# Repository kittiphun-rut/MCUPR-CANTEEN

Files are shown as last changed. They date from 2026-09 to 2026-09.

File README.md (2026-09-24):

# MCU Phrae Smart Canteen — ระบบบริหารจัดการอาหารกลางวันนิสิต

ระบบคูปองอาหารดิจิทัล (โควตา 35 บาท/คน/วัน) ของมหาวิทยาลัยมหาจุฬาลงกรณราชวิทยาลัย
วิทยาเขตแพร่ ประกอบด้วยเฟิร์มแวร์ ESP32-S3 สองฝั่งที่คุยกันผ่าน ESP-NOW

> 📌 **ย้อนกลับไปใช้เวอร์ชันเก่า** — ทุกรุ่นของทั้งสองฝั่งอยู่บน GitHub แล้ว
> กดโหลด zip ได้เลยจาก [`VERSIONS.md`](VERSIONS.md) ·
> **ต้นฉบับก่อนแก้ไข** เก็บไว้ครบที่ [`original/`](original/)

| โฟลเดอร์ | บทบาท | เวอร์ชัน |
|---|---|---|
| `Canteen_Host_Server/` | เครื่องแม่ข่าย: ฐานข้อมูลนิสิต, นาฬิกา RTC, เว็บสำหรับเจ้าหน้าที่ | 113.1.0 |
| `Canteen_Station_Client/` | เครื่องประจำร้านค้า: อ่านบัตร RFID แล้วถามสิทธิ์จากแม่ข่าย | 122.1.0 |

> รุ่น 113.0.0 / 122.0.0 **เริ่มใหม่จากไฟล์ต้นฉบับ 107.0.1 / 117.0.7** ไม่ได้ต่อยอด
> จากสายเดิม ฟีเจอร์ที่เคยมีในสายเดิมบางอย่าง (เครื่องพิมพ์สลิป, คิวออฟไลน์,
> จอสาธารณะ `/display`) **ยังไม่ถูกใส่กลับเข้ามาในรุ่นนี้** ถ้าต้องการให้ใช้
> `release/11` หรือเก่ากว่า รายละเอียดอยู่ใน [`CHANGELOG.md`](CHANGELOG.md)

### โครงสร้างไฟล์

ทั้งสองฝั่งแยกส่วนวาดจอออกมาเป็นไฟล์ของตัวเองเหมือนกัน

```
Canteen_Host_Server/
├── Canteen_Host_Server.ino      ตรรกะระบบ ฐานข้อมูล ESP-NOW เส้นทางเว็บ  (2,052 บรรทัด)
├── HostScreen.h                 ทุกอย่างที่วาดลงจอ TFT ของแม่ข่าย           (836 บรรทัด)
└── WebDashboard.h               หน้าเว็บ แดชบอร์ด + จอสาธารณะบนทีวี          (936 บรรทัด)

Canteen_Station_Client/
├── Canteen_Station_Client.ino   ตรรกะระบบ อ่านบัตร ESP-NOW ปุ่มกด          (1,183 บรรทัด)
└── StationScreen.h              ทุกอย่างที่วาดลงจอ TFT ของจุดบริการ          (948 บรรทัด)
```

ไฟล์ `.h` เหล่านี้ถูก `#include` ไว้ **ท้ายไฟล์หลักก่อน `setup()`** เพราะโค้ดข้างใน
อ้างถึงตัวแปรส่วนกลางที่ประกาศไว้ข้างบน **อย่าย้าย `#include` ขึ้นไปบนสุด**
Arduino IDE จะแสดงทุกไฟล์เป็นแท็บของสเก็ตช์เดียวกัน เปิดพร้อมกันได้เลย

> ⚠️ ฟังก์ชันที่นิยามในไฟล์ `.h` จะ "มาทีหลัง" โค้ดทุกบรรทัดเหนือบรรทัด `#include`
> ถ้าโค้ดข้างบนเรียกใช้โดยไม่มีการประกาศล่วงหน้า **จะคอมไพล์ไม่ผ่าน**
> และค่าปริยายของพารามิเตอร์ต้องอยู่ที่การประกาศล่วงหน้าเท่านั้น ใส่ซ้ำที่นิยามไม่ได้
> ตรวจทั้งสองข้อได้ด้วย `python3 tools/proto-check/splitcheck.py`
>
> ⚠️ กติกาเดียวกันนี้ใช้ **ภายในไฟล์ `.h` เอง** ด้วย ฟังก์ชันที่ถูกเรียกต้องนิยามอยู่ข้างบน
> หรือมีบรรทัดประกาศล่วงหน้าอยู่ข้างบน จะอยู่ใน `.h` เดียวกันหรืออยู่ใน `.ino`
> เหนือบรรทัด `#include` ก็ได้ เพราะคอมไพเลอร์เห็นทั้งสองไฟล์เป็นไฟล์เดียวกัน
> ตรวจด้วย `python3 tools/proto-check/ordercheck.py`

---

## อินเตอร์เฟส

**หน้าเว็บเป็นสองภาษา ไทย/อังกฤษ** กดปุ่มบนแถบบนเพื่อสลับ เบราว์เซอร์จำค่าที่เลือกไว้
ค่าเริ่มต้นเป็นอังกฤษเพราะนิสิตส่วนใหญ่เป็นชาวต่างชาติ ส่วนหน้าเข้าสู่ระบบสลับได้เช่นกัน

**จอ TFT ทั้งสองฝั่งเป็นภาษาอังกฤษอย่างเดียว** เพราะฟอนต์ในตัวไลบรารี Adafruit GFX
ไม่มีตัวอักษรไทย ถ้าจะให้เป็นไทยต้องฝังฟอนต์บิตแมปเข้าไปเอง ซึ่งกินแฟลชเพิ่มมาก

> ⚠️ ถ้ามีภาษาไทยหลุดไปถึงจอ จะไม่ใช่แค่อ่านไม่ออก แต่ **ตัวอักษรจะซ้อนทับกัน**
> เพราะภาษาไทยหนึ่งตัวกินสามไบต์ จอจึงวาดเป็นสัญลักษณ์สามตัวและกว้างกว่าที่นับไว้สามเท่า
> ทุกข้อความที่มาจากผู้ใช้หรือฐานข้อมูลจึงผ่าน `asciiOnly()` ก่อนถึงจอเสมอ
> และ **ชื่อร้านมีช่องแยกสำหรับขึ้นจอโดยเฉพาะ** ตั้งได้จากแท็บ Shops บนหน้าเว็บ

มีสองโหมดสี **สว่าง** และ **มืด** เครื่องแม่ข่ายเป็นผู้กำหนดให้ทั้งระบบ

### คำแปลทำงานอย่างไร

ข้อความอังกฤษเขียนไว้ใน HTML ตามปกติแล้วติดป้าย `data-i="คีย์"` ส่วนคำไทยอยู่ใน
พจนานุกรมชุดเดียวชื่อ `TH` ที่หัวของ `DASH_JS` **ไม่ได้เขียนซ้ำสองชุดในทุกบรรทัด**
แบบที่เฟิร์มแวร์รุ่นเก่าทำ เวลาเพิ่มข้อความใหม่จึงแก้แค่สองที่ คือติดป้ายที่ HTML
กับเติมอีกหนึ่งบรรทัดในพจนานุกรม

ถ้าลืมเติมคำแปล หน้าเว็บจะแสดงภาษาอังกฤษไว้ก่อน ไม่พังและไม่กลายเป็นช่องว่าง

### หน้าเว็บของเจ้าหน้าที่

| แท็บ | มีอะไร |
|---|---|
| **Today** | จำนวนจานที่จ่ายวันนี้ · เป็นเงินเท่าไร · เหลืออีกกี่คน · นาฬิกาและสถานะเปิดบริการ<br>ยอดขายรายร้านเป็นแท่งเทียบกัน และสถานะของจุดบริการทั้งสี่จุด |
| **Students** | ค้นหา เพิ่ม ลบ ตัดสิทธิ์ด้วยตนเอง ผูกบัตรชั่วคราว และดาวน์โหลด CSV |
| **Shops** | ชื่อร้านและชื่อผู้ประกอบการทั้งสี่ร้าน |
| **Settings** | โหมดการแสดงผลของทุกจุดบริการ · เวลาเปิดบริการ · นาฬิกา · นำเข้ารายชื่อ<br>บัญชีเจ้าหน้าที่ · ไฟล์ประวัติย้อนหลัง · ปิดยอดประจำวัน |

ทุกแท็บสลับไทย/อังกฤษได้ รวมถึงข้อความแจ้งเตือนและกล่องถามยืนยันก่อนลบ

### จอของเครื่องแม่ข่าย (3 หน้า)

| หน้า | มีอะไร |
|---|---|
| **TODAY** | จำนวนจาน เงินที่จ่าย นาฬิกา และป้ายเปิด/ปิดบริการ |
| **SHOPS** | สี่ช่อง ช่องละร้าน ขึ้นชื่อร้านก่อนเลขจุดบริการ พร้อมจุดสถานะ สัญญาณ และแบตเตอรี่ |
| **SYSTEM** | ผลการแตะบัตรครั้งล่าสุด ข้อมูลเครือข่าย และข้อมูลเครื่อง |

### จอของเครื่องประจำร้านค้า (3 หน้า)

| หน้า | มีอะไร |
|---|---|
| **หน้าแรก** | บอกสถานะการให้บริการสามแบบ **TAP YOUR CARD** (คลื่นเขียว) เมื่อพร้อม · **SERVER OFFLINE** (คลื่นเหลือง) เมื่อแม่ข่ายไม่ตอบ · **OUT OF SERVICE** (คลื่นแดง) เมื่อเครื่องอ่านบัตรไม่ตอบ พร้อมยอดวันนี้และเวลา |
| **หน้าสอง** | ยอดของจุดนี้ หมายเลขจุด สถานะการเชื่อมต่อ และเวลา |
| **SYSTEM** | ข้อมูลเครื่องสำหรับคนดูแล |

ผลการแตะบัตรขึ้นเต็มจอเป็นคำเดียวตัวโต: `APPROVED` · `ALREADY SERVED` ·
`CLOSED NOW` · `NOT ON THE LIST` พร้อมประโยคอธิบายหนึ่งบรรทัดด้านล่าง

---

## ภาพหน้าจอ

ภาพทั้งหมดอยู่ใน [`docs/interface/`](docs/interface/) และเปิดดูพร้อมคำอธิบายทีละภาพได้ที่
[`docs/interface-gallery.html`](docs/interface-gallery.html) (โหลดไฟล์แล้วเปิดด้วยเบราว์เซอร์)

| | |
|---|---|
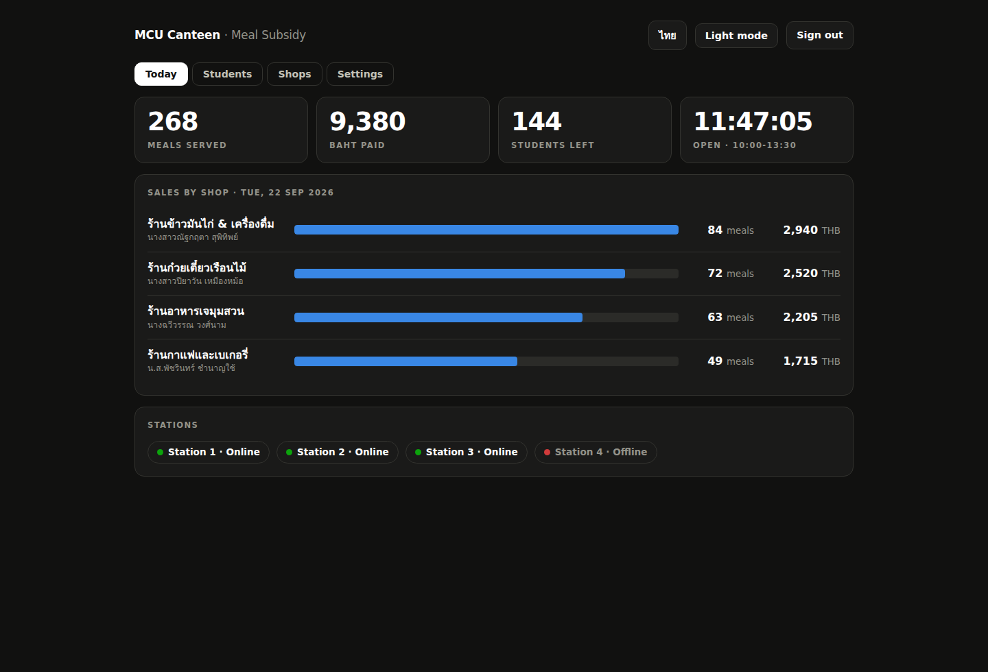
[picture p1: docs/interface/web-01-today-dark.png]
แดชบอร์ด Today โหมดมืด
|  | แดชบอร์ด Today โหมดสว่าง |
| **Today** — สิ่งที่เจ้าของร้านอยากรู้อยู่หน้าแรก | โหมดสว่าง ใช้ชุดสีที่ปรับแยกกัน |
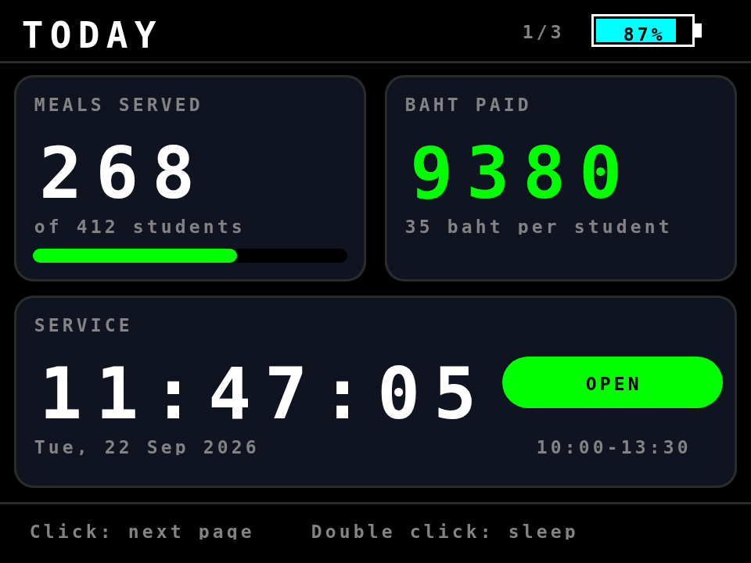
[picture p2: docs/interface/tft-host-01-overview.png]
จอแม่ข่ายหน้า TODAY
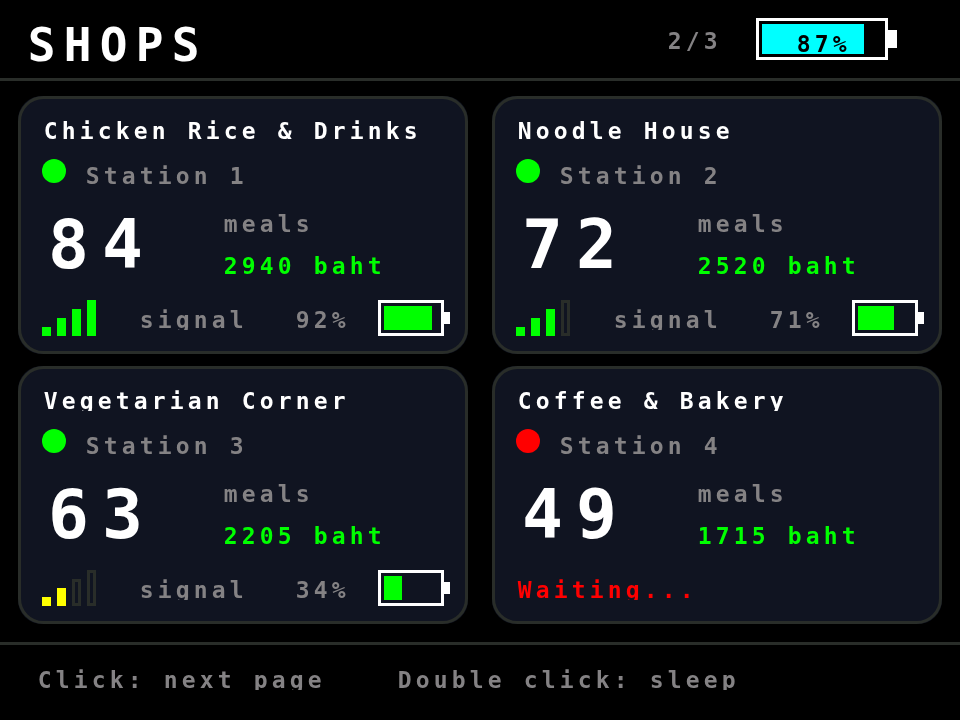
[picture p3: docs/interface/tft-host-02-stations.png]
จอแม่ข่ายหน้า SHOPS
|  |  |
| จอแม่ข่าย หน้า **TODAY** | จอแม่ข่าย หน้า **SHOPS** |
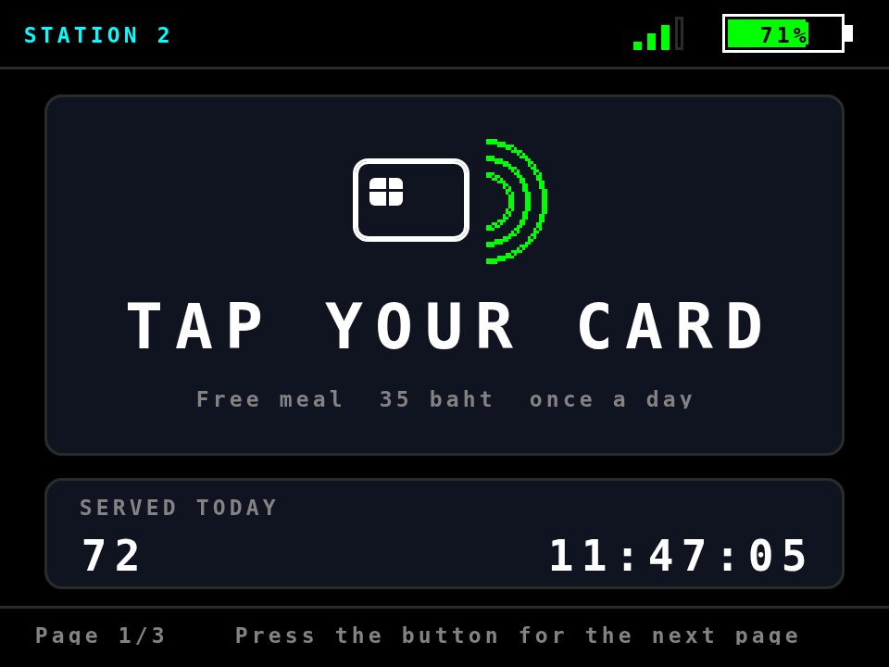
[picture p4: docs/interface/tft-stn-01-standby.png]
จอร้านค้ารอแตะบัตร
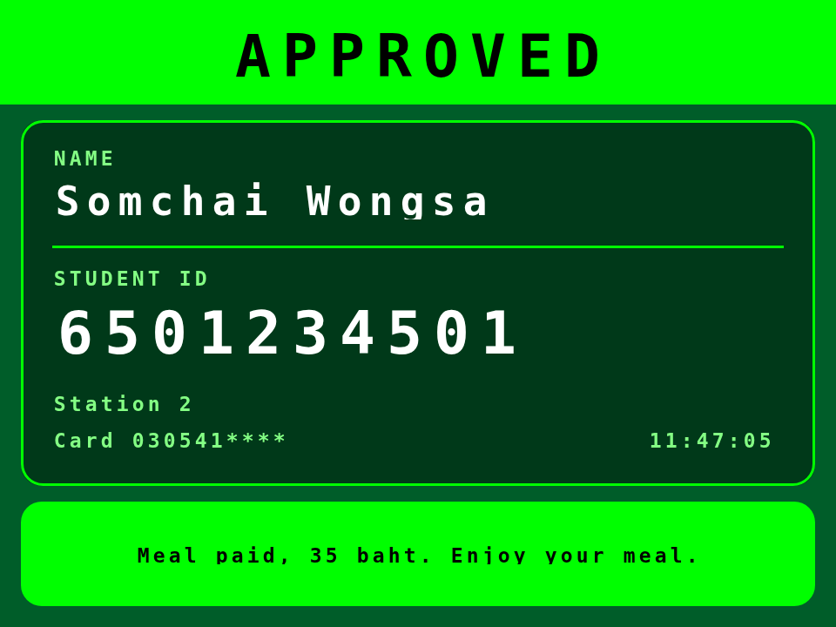
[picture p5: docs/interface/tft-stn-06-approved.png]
แจ้งผล APPROVED
|  |  |
| จอประจำร้านค้า มีประโยคเดียวที่นิสิตต้องอ่าน | ผลการแตะบัตร คำเดียวตัวโต |

ภาพจอ TFT ทั้งหมดเรนเดอร์จากตัวจำลอง Adafruit GFX บนผืนผ้าใบ 320x240
ภาพหน้าเว็บเรนเดอร์จากหน้าจริงที่ประกอบจาก `WebDashboard.h` ด้วย Chromium
ข้อมูลในภาพเป็นชุดตัวอย่างสำหรับสาธิต

---

## ฮาร์ดแวร์

ทั้งสองฝั่งใช้ ESP32-S3 DevKitC-1 (N16R8) + จอ ST7789V 2.8" 320x240 + WS2812 บน GPIO 48

**อุปกรณ์ภายนอกทุกตัวอยู่บนแถวซ้ายของบอร์ดแถวเดียว** แถวขวาไม่ได้ต่ออะไรเลย
และขาของแต่ละโมดูลเรียงติดกันตามลำดับขาบนตัวโมดูลเอง สายจึงไม่มีเส้นไหนไขว้กัน

### Host Server
| อุปกรณ์ | ขา | ตำแหน่งบนแถวซ้าย |
|---|---|---|
| TFT (บัส FSPI) | BLK 9 · CS 10 · DC 11 · RES 12 · SDA 13 · SCL 14 | 15–20 |
| DS3231 RTC (I2C) | SDA 4 · SCL 5 | 4–5 |
| Buzzer | 17 | 10 |
| ปุ่มกด | 18 (INPUT_PULLUP) | 11 |
| วัดแรงดันแบตเตอรี่ | 8 (ADC1_CH7, ตัวแบ่งแรงดัน 1:2) | 12 |
| การ์ด SD (หลังโมดูลจอ, **บัส HSPI แยกของตัวเอง**) | SCK 6 · MISO 7 · MOSI 15 · CS 16 | 6–9 |

### Station Client
| อุปกรณ์ | ขา | ตำแหน่งบนแถวซ้าย |
|---|---|---|
| TFT (**บัส HSPI**) | BLK 9 · CS 10 · DC 11 · RES 12 · SDA 13 · SCL 14 | 15–20 |
| RC522 (**บัส FSPI ผ่านตัวแปร `SPI`**) | SS 4 · SCK 5 · MOSI 6 · MISO 7 · RST 15 | 4–8 |
| Buzzer | 17 | 10 |
| ปุ่มกด | 18 (INPUT_PULLUP) | 11 |
| วัดแรงดันแบตเตอรี่ | 8 (ADC1_CH7, ตัวแบ่งแรงดัน 1:2) | 12 |

บัซเซอร์ ปุ่มกด และสายวัดแบตเตอรี่ **ใช้ขาเดียวกันทั้งสองบอร์ด**
ประกอบสายชุดเดียวแล้วสลับใช้ได้ทั้งสองฝั่ง

> **สำคัญ:** บน ESP32-S3 ตัวแปร `SPI` มาตรฐานผูกกับ FSPI (SPI2_HOST) และไลบรารี MFRC522
> เรียกใช้ตัวแปรนั้น จอจึงต้องอยู่บน HSPI (SPI3_HOST) มิฉะนั้นอุปกรณ์สองตัวจะแย่ง
> peripheral เดียวกันคนละขา และจอจะเพี้ยนหลัง `PCD_Init()`

---

## เมื่อเครื่องแม่ข่ายไม่ตอบ

ระบบนี้ออกแบบให้ **fail-closed** คือถ้าตัดสินสิทธิ์ไม่ได้ก็ไม่ให้บริการ
ไม่ใช่เดาแล้วปล่อยผ่าน เพราะอาหารที่จ่ายไปแล้วเรียกคืนไม่ได้
และสิทธิ์เป็นวันละครั้งข้ามสี่จุดบริการ ถ้าแม่ข่ายล่มก็ล่มพร้อมกันทั้งสี่จุด
การอนุมัติเองตอนออฟไลน์จึงเปิดช่องให้รับซ้ำได้ทันทีโดยกระทบกันทีหลังไม่ได้

**จุดบริการไม่มีฐานข้อมูลเลย** ไม่เคยตัดสินใจเอง ส่งหมายเลขบัตรไปแล้วรอคำตอบอย่างเดียว

| สถานการณ์ | สิ่งที่จุดบริการทำ | ตัดสิทธิ์ไปหรือยัง |
|---|---|---|
| แม่ข่ายเงียบเกิน 15 วินาที | หน้าแรกขึ้น **SERVER OFFLINE** และ**ไม่รับการแตะบัตร** | **ไม่** การันตีได้ เพราะไม่ได้ส่งอะไรออกไป |
| แตะบัตรตอนนั้นพอดี | ขึ้นหน้าเตือน **SERVER OFFLINE** ทันที ไม่ต้องรอหมดเวลา | **ไม่** เหตุผลเดียวกัน |
| ส่งไปแล้วไม่มีคำตอบใน 3 วินาที | ขึ้นหน้า **RESULT UNKNOWN** | **ไม่ทราบ** ดูคำอธิบายข้างล่าง |

### ทำไมต้องมีคำว่า "ไม่ทราบผล"

ถ้าแม่ข่ายอนุมัติและบันทึกไปแล้ว แต่แพ็กเก็ตตอบกลับหายระหว่างทางทั้งสามครั้ง
จุดบริการจะหมดเวลารอโดยที่ **แม่ข่ายบันทึกว่ารับไปแล้วจริง ๆ**
การขึ้นว่า "ไม่สำเร็จ" ในกรณีนี้จึงเป็นการบอกข้อมูลผิด

เรื่องนี้แก้ให้หายขาดไม่ได้ในทางทฤษฎี เป็นปัญหา **Two Generals**
มาตรฐานจึงไม่พยายามกำจัด แต่ทำให้ **กู้คืนได้** แทน
หน้าจอจึงบอกว่าไม่ทราบผล แล้วชี้ทางให้ **แตะบัตรซ้ำ**
ถ้าแม่ข่ายบันทึกไปแล้วจะตอบว่า `ALREADY SERVED` ถ้ายังไม่ได้บันทึกก็จะตัดสิทธิ์ให้ตามปกติ
ไม่ว่าทางไหนก็ได้คำตอบที่ถูกต้อง และไม่มีทางจ่ายซ้ำ

### การส่งซ้ำไม่ทำให้ตัดสิทธิ์ซ้ำ

ทุกครั้งที่แตะบัตร จุดบริการแนบ **หมายเลขลำดับ (seq)** ไปด้วย และส่งซ้ำสูงสุดสามครั้ง
แม่ข่ายจำคู่ `(หมายเลขจุดบริการ, seq)` ล่าสุดไว้ ถ้าเจอคู่เดิมซ้ำ
มันจะ **ส่งคำตอบเดิมที่แคชไว้กลับไป ไม่ประมวลผลใหม่**
คุณสมบัตินี้เรียกว่า idempotent request เป็นหัวใจของการกันข้อมูลไม่ตรงกัน
ถ้าไม่มี การส่งซ้ำสามครั้งจะกลายเป็นตัดสิทธิ์สามครั้ง

> ⚠️ บนรุ่น **N16R8** ขา `GPIO33`–`GPIO37` ถูก **PSRAM แบบ OPI** จองไว้
> ถึงแม้ `GPIO35` `GPIO36` `GPIO37` จะโผล่อยู่บนแถวขวาของบอร์ดก็ห้ามใช้
> ตรวจได้ด้วย `python3 tools/proto-check/pincheck.py`

**ผังการต่อสายเต็ม ๆ พร้อมลำดับขาของทุกโมดูล อยู่ใน
[`docs/HARDWARE.md`](docs/HARDWARE.md)**

---

## ไลบรารีที่ต้องติดตั้ง

`Adafruit GFX` · `Adafruit ST7735/ST7789` · `ArduinoJson (v6)` · `RTClib` · `MFRC522`
บน Arduino ESP32 core 2.x หรือ 3.x (โค้ดครอบ `ESP_ARDUINO_VERSION_MAJOR` ไว้แล้ว)

### การตั้งค่าบอร์ดใน Arduino IDE

| หัวข้อใน Tools | ต้องตั้งเป็น |
|---|---|
| Board | ESP32S3 Dev Module |
| Flash Size | **16MB (128Mb)** |
| PSRAM | **OPI PSRAM** |
| Partition Scheme | **Huge APP (3MB No OTA/1MB SPIFFS)** |
| USB Mode | Hardware CDC and JTAG |

> ⚠️ **Partition Scheme สำคัญมาก เลือกผิดแล้วอัปโหลดไม่ได้เลย**
>
> ถ้าใช้ค่าเริ่มต้น *Default 4MB with spiffs* จะได้พื้นที่โปรแกรมแค่ **1.25 MB**
> ซึ่งไม่พอ เฟิร์มแวร์แม่ข่ายจะขึ้นว่า `Sketch too big` ทั้งที่บอร์ดมีแฟลช 16 MB
> พอเปลี่ยนเป็น *Huge APP* จะได้ 3 MB
>
> **ห้ามเลือกแบบที่ลงท้ายด้วย FATFS** (เช่น *16M Flash (3MB APP/9.9MB FATFS)*)
> เพราะโค้ดเรียก `LittleFS.begin(true)` ซึ่งมองหาพาร์ทิชันชื่อ `spiffs`
> ส่วนแบบ FATFS ตั้งชื่อพาร์ทิชันว่า `ffat` ทำให้เมานต์ไม่ขึ้นและ
> **ฐานข้อมูลนิสิตทั้งหมดหายไป** ต้องเป็นแบบที่ลงท้ายด้วย SPIFFS เท่านั้น

---

## แก้ปัญหาที่พบบ่อย

### ไม่มีชื่อ Wi-Fi `MCU_CANTEEN_HOST` ขึ้นมาให้เลือก

เครื่องแม่ข่าย **ขึ้นจอบอกสถานะเครือข่ายให้เองตอนบูต** ค้างไว้สามวินาที
ดูที่จอของเครื่องแม่ข่ายก่อนเสมอ

| สิ่งที่เห็นบนจอ | แปลว่า | ทำอย่างไร |
|---|---|---|
| แถบเขียว **WI-FI IS ON** พร้อมชื่อ รหัสผ่าน และเลข IP | เครื่องปล่อยสัญญาณแล้ว | ปัญหาอยู่ที่อุปกรณ์ที่ใช้ค้นหา ลองปิด-เปิด Wi-Fi ของโทรศัพท์ หรือลืมเครือข่ายเดิมแล้วค้นใหม่ |
| แถบแดง **WI-FI FAILED TO START** | เรียก `WiFi.softAP()` ไม่สำเร็จสามครั้งติด | ถอดไฟแล้วเสียบใหม่ ถ้ายังเป็นอีกให้แฟลชใหม่ (การอ่านบัตรยังทำงานได้ตามปกติ) |
| จอไม่ขึ้นอะไรเลย หรือค้างที่แอนิเมชันบูต | เครื่องแพนิกหรือบูตวน | ดูข้อความบน Serial Monitor ที่ 115200 |

> **เคยเกิดขึ้นจริงมาแล้ว** ในสายเฟิร์มแวร์เดิม สาเหตุคือ `WIFI_PROTOCOL_LR`
> ซึ่งเป็นโหมดระยะไกลเฉพาะของ Espressif ทำให้โทรศัพท์และคอมพิวเตอร์
> **มองไม่เห็นชื่อ Wi-Fi** ทั้งที่เครื่องปล่อยสัญญาณอยู่
> รุ่นนี้เริ่มใหม่จากต้นฉบับซึ่งไม่มีบรรทัดนั้นแล้ว ถ้าจะเพิ่มโหมดระยะไกลในอนาคต
> **ต้องทดสอบกับโทรศัพท์จริงก่อนเสมอ**

### เข้า `canteen.local` ไม่ได้

Android บางรุ่นไม่รองรับ mDNS ให้พิมพ์ `192.168.4.1` ตรง ๆ แทน
(จอตอนบูตแสดงหมายเลขนี้ไว้ให้แล้ว)

---

## ข้อควรรู้เวลาแก้โค้ดต่อ

Arduino IDE **สร้างต้นแบบฟังก์ชัน (prototype) ให้เองอัตโนมัติ** แล้ววางไว้ใกล้หัวไฟล์
ซึ่งอยู่ **เหนือจุดที่นิยาม struct ของสเก็ตช์** ถ้าเพิ่มฟังก์ชันที่รับ struct ของโครงการ
เป็นพารามิเตอร์แล้วลืมประกาศล่วงหน้า จะคอมไพล์ไม่ผ่านด้วยข้อความชวนงงแบบนี้

```
error: variable or field 'fillStationConfig' declared void
error: 'HostConfigPacket' was not declared in this scope
```

ทุกฟังก์ชันแบบนั้นต้องมีบรรทัดประกาศอยู่ในบล็อก *Forward Declarations*
(อยู่หลังนิยามโครงสร้างทั้งหมด) ตรวจได้ด้วย

```sh
python3 tools/proto-check/protoscan.py \
  Canteen_Host_Server/Canteen_Host_Server.ino \
  Canteen_Station_Client/Canteen_Station_Client.ino
```

และตรวจวงเล็บของทุกไฟล์ (รวมไฟล์ `.h` ที่ถูก include) ด้วย

```sh
python3 tools/proto-check/runall.py        # รันทุกตัวข้างล่างนี้รวดเดียว

python3 tools/proto-check/headercheck.py   # หัวไฟล์และป้ายเวอร์ชัน
python3 tools/proto-check/asciicheck.py    # ข้อความที่ฟอนต์ของจอ TFT วาดไม่ได้
python3 tools/proto-check/bracecheck.py    # วงเล็บและเครื่องหมายคำพูดของทุกไฟล์
python3 tools/proto-check/splitcheck.py    # ปัญหาจากการแยกโค้ดไปไว้ในไฟล์ .h
python3 tools/proto-check/ordercheck.py    # ฟังก์ชันที่ถูกเรียกก่อนถูกประกาศ
python3 tools/proto-check/gfxcheck.py      # ฟังก์ชัน GFX ที่ต้องมี startWrite() ก่อน
python3 tools/proto-check/packetcheck.py   # แพ็กเก็ตคำสั่งที่ใส่ฟิลด์ไม่ครบ
python3 tools/proto-check/pincheck.py      # ขาชนกันเองหรือไปโดนขาต้องห้าม
python3 tools/proto-check/kicadcheck.py    # ไฟล์วงจร KiCad ตรงกับผังขาในซอร์ส
```

### มาตรฐานคอมเมนต์

ทุกไฟล์ซอร์สมีหัวไฟล์แบบ **Doxygen** บอกเวอร์ชัน วันที่ และ **ตารางประวัติการแก้ไข**
ว่าแต่ละรุ่นเปลี่ยนอะไรในไฟล์นั้นบ้าง ส่วนในเนื้อโค้ดมีป้าย `// [113.0.0] เพิ่ม: ...`
ปักไว้เหนือจุดที่เพิ่มหรือแก้ เปิดไฟล์ขึ้นมาแล้วรู้ทันทีว่าอะไรมาจากรุ่นไหน
โดยไม่ต้องไปไล่อ่าน git log

รายละเอียดและกติกาทั้งหมดอยู่ใน **[`docs/CODE-STANDARD.md`](docs/CODE-STANDARD.md)**
และถูกบังคับด้วย `headercheck.py` — ถ้าลืมอัปเดตเลขเวอร์ชัน ลืมเติมแถวในตาราง
หรือปักป้ายด้วยเลขที่ไม่มีอยู่จริง ตัวตรวจจะฟ้องทันที

`bracecheck` ตรวจทั้งวงเล็บและ **สตริงที่เปิดแล้วไม่ปิดภายในบรรทัดเดียวกัน**
ข้อหลังเพิ่มเข้ามาหลังจากพลาดลบเครื่องหมายคำพูดเปิดทิ้งตอนแก้ HTML ที่ฝังอยู่ในสตริง C++
ซึ่งคอมไพล์ไม่ผ่านแน่นอนแต่ตัวนับวงเล็บมองไม่เห็น

---

## โปรโตคอล ESP-NOW (ช่อง 1, ไม่เข้ารหัส)

ทุกแพ็กเก็ตขึ้นต้นด้วย `magic = 0xCA` และ `version = 2` ฝั่งรับจะตรวจทั้งสองค่าก่อนเสมอ

| โครงสร้าง | ขนาด | ทิศทาง | ใช้เมื่อ |
|---|---|---|---|
| `StationPacket` | 50 ไบต์ | สถานี → แม่ข่าย | `MSG_HEARTBEAT (1)`, `MSG_SCAN_REQ (2)` |
| `HostResponsePacket` | 200 ไบต์ | แม่ข่าย → สถานี | `MSG_HEARTBEAT (1)`, `MSG_SCAN_RESP (3)` |
| `HostConfigPacket` | 8 ไบต์ | แม่ข่าย → สถานี | `MSG_CONFIG (4)` สั่งโหมดการแสดงผล: ธีม ไฟหน้าจอ และโหมดพักหน้าจอ (`stationId = 0` คือทุกสถานี) |

ขนาดทั้งสามถูกยืนยันด้วย `static_assert` ทั้งสองฝั่ง ถ้าแก้โครงสร้างแล้วขนาดไม่ตรง
จะคอมไพล์ไม่ผ่าน แทนที่จะไปพังตอนใช้งานจริง

การกันแพ็กเก็ตซ้ำ: `MSG_SCAN_REQ` พกหมายเลขลำดับ (`seq`) ถ้าแม่ข่ายได้รับซ้ำ
จะส่งคำตอบเดิมกลับไปโดยไม่ตัดสิทธิ์ซ้ำ

---

## เว็บสำหรับเจ้าหน้าที่

เข้าผ่าน `http://192.168.4.1` หรือ `http://canteen.local` หลังต่อ Wi-Fi `MCU_CANTEEN_HOST`
บัญชีเริ่มต้น `admin` / `admin1234` (**ควรเปลี่ยนทันทีหลังติดตั้ง**)

### หน้าเข้าระบบเด้งขึ้นเอง (Captive Portal)

เมื่อโทรศัพท์ต่อ Wi-Fi ระบบปฏิบัติการจะยิงคำขอไปยัง URL ที่ใช้ตรวจว่าเครือข่าย
ออกอินเทอร์เน็ตได้หรือไม่ เครื่องแม่ข่ายดักไว้ด้วย `DNSServer` ที่ตอบทุกโดเมน
กลับมาที่ `192.168.4.1` และ `server.onNotFound()` ที่ตอบ HTTP 302 ไปหน้าเข้าสู่ระบบ

หน้าต่างที่เด้งขึ้นมาบน iOS เป็นเบราว์เซอร์ย่อส่วน คุกกี้ที่ได้จากการล็อกอินในหน้าต่างนี้
จะไม่ถูกส่งต่อให้ Safari ถ้าเจ้าหน้าที่ต้องใช้งานนาน ให้เลือก "ใช้เครือข่ายนี้ตามที่เป็น"
แล้วเปิด Safari ไปที่ `192.168.4.1` แทน

### เส้นทาง

| Method | Path | หน้าที่ |
|---|---|---|
| GET | `/` | แดชบอร์ด (โครงหน้าเล็ก ๆ ตัวเลขมาจาก `/api/dashboard`) |
| GET | `/display` | **จอสาธารณะสำหรับทีวีในโรงอาหาร เปิดดูได้โดยไม่ต้องเข้าสู่ระบบ** |
| GET | `/api/board` | ตัวเลขของจอสาธารณะ ดึงทุกสองวินาที เปิดดูได้โดยไม่ต้องเข้าสู่ระบบ |
| GET | `/s.css` · `/a.js` | สไตล์และสคริปต์ เสิร์ฟตรงจากแฟลช เบราว์เซอร์แคชได้ 1 วัน |
| GET | `/api/dashboard` | ตัวเลขสดทั้งหมด หน้าเว็บดึงทุกสองวินาที |
| GET | `/api/students` | รายชื่อแบบแบ่งหน้า (`page`, `limit` สูงสุด 100, `search`) |
| GET | `/export.csv` | รายงานสรุปประจำวัน |
| GET | `/api/archive/download?file=arc_*.csv` | ดาวน์โหลดไฟล์ประวัติ |
| GET | `/api/system/health` | อุณหภูมิ โหลด และหน่วยความจำของเครื่องแม่ข่าย |
| POST | `/api/display` | สั่งโหมดการแสดงผลของทุกจุดบริการ |
| POST | `/api/student/save` · `/api/student/delete` | จัดการรายชื่อ |
| POST | `/api/tempcard/save` · `/api/tempcard/remove` · `/bind-temp` | จัดการบัตรชั่วคราว |
| POST | `/manual-claim` | ตัดสิทธิ์ด้วยตนเอง |
| POST | `/api/admin/save` · `/api/admin/delete` | จัดการบัญชีเจ้าหน้าที่ |
| POST | `/save-shops` · `/api/settings/time` · `/api/rtc/set` | ตั้งค่าระบบ |
| POST | `/reset` · `/api/archive/delete` | ปิดยอดประจำวัน / ลบไฟล์ประวัติ |
| POST | `/upload` | นำเข้ารายชื่อจาก CSV |

**คำสั่งที่เปลี่ยนแปลงข้อมูลเป็น POST ทั้งหมด** ลิงก์เดียวจึงลบข้อมูลไม่ได้
และการพรีเฟตช์ของเบราว์เซอร์ไม่ไปกดคำสั่งโดยบังเอิญ

---

## จอสาธารณะบนทีวี (`/display`)

เปิดเบราว์เซอร์บนทีวีหรือกล่อง Android ไปที่ `http://192.168.4.1/display`
แล้วกดเต็มจอ ปล่อยค้างไว้ได้ทั้งวัน หน้านี้ **ไม่ต้องเข้าสู่ระบบ** โดยตั้งใจ
เพราะไม่มีใครอยากพิมพ์รหัสผ่านด้วยรีโมททีวี และถ้าเครื่องทีวีรีบูต
หน้าจอต้องกลับมาเองโดยไม่ต้องมีคนไปกด

### แสดงอะไรบ้าง

| ส่วน | เนื้อหา |
|---|---|
| แถบบน | ชื่อโรงอาหาร นาฬิกา วันที่ และป้ายเปิด/ปิดบริการพร้อมช่วงเวลา |
| ตัวเลขสามช่อง | จ่ายไปกี่จาน เป็นเงินกี่บาท และเหลืออีกกี่คน |
| ยอดขายรายร้าน | ชื่อร้าน จำนวนจาน จำนวนเงิน และแท่งเทียบสัดส่วนกัน |
| รายการล่าสุด | แปดรายการหลังสุดที่ผ่านแล้วเท่านั้น |

ไทยกับอังกฤษขึ้นพร้อมกันทั้งคู่ ไม่มีปุ่มสลับภาษาแบบหน้าแดชบอร์ด
เพราะไม่มีใครเดินไปกดปุ่มบนจอทีวี

### ข้อมูลที่หน้านี้ห้ามมีเด็ดขาด

ใครเดินผ่านโรงอาหารก็เห็นจอนี้ หน้านี้จึงถูกกำหนดไว้ว่า

* **รหัสนิสิตถูกปิดบังเหลือห้าหลักแรก** ที่เหลือเป็นดอกจัน เช่น `65012*****`
* **ไม่มีชื่อนิสิต** ไม่ว่ากรณีใด
* **ไม่มีหมายเลขบัตร** และ **ไม่มีเลขอ้างอิงรายการ**
* **ไม่มีข้อมูลฮาร์ดแวร์ของเครื่องแม่ข่าย** เช่น อุณหภูมิ หน่วยความจำ หรือ MAC
* **มีเฉพาะรายการที่ผ่านแล้ว** รายการที่ถูกปฏิเสธหรือซ้ำไม่ขึ้นบนจอนี้

ข้อกำหนดนี้ไม่ได้อยู่แค่ในเอกสาร แต่ถูกบังคับด้วย
`tools/proto-check/privacycheck.py` ซึ่งจะฟ้องทันทีถ้ามีใครเผลอใส่ฟิลด์ต้องห้าม
ลงใน `handlePublicBoard()` หรือเพิ่มเส้นทางสาธารณะใหม่โดยไม่ได้ตั้งใจ

### ข้อควรระวังเรื่องเครือข่าย

เส้นทางนี้เปิดให้ **ทุกคนที่ต่อ Wi-Fi ของเครื่องแม่ข่ายได้** ไม่ใช่เฉพาะทีวี
ข้อมูลที่ปล่อยออกไปจึงถูกจำกัดไว้เท่าที่ยอมให้คนนอกเห็นตามรายการข้างบน
ถ้าต้องการให้แคบกว่านี้ ต้องแยกเครือข่ายของทีวีออกจากเครือข่ายที่ให้บริการ

---

## ไฟล์ข้อมูลใน LittleFS

| ไฟล์ | เนื้อหา |
|---|---|
| `/students.csv` | ทะเบียนนิสิต `studentId,fullName,uid` |
| `/daily_log.csv` | บันทึกการรับสิทธิ์ของวัน ใช้กู้สถานะเมื่อไฟดับแล้วบูตใหม่ |
| `/arc_YYYYMMDD_HHMMSS.csv` | ไฟล์ประวัติที่ถูกจัดเก็บตอนปิดยอดประจำวัน |
| `/admins.json` | บัญชีเจ้าหน้าที่ |
| `/shops.json` | ชื่อร้านและผู้ประกอบการ |

ไฟล์ที่ส่งออกจาก `/export.csv` ครอบทุกช่องด้วยเครื่องหมายคำพูดและเติมซ้ำให้ถูกแบบ
ชื่อร้านหรือชื่อนิสิตที่มีลูกน้ำหรือเครื่องหมายคำพูดจึงไม่ทำให้คอลัมน์เลื่อน

---

## การใช้งานปุ่มกด

| การกด | Host Server | Station Client |
|---|---|---|
| คลิก 1 ครั้ง | เปลี่ยนหน้า (3 หน้า) | เปลี่ยนหน้า (3 หน้า) |
| คลิก 2 ครั้ง | เข้าโหมดพักหน้าจอ **+ สั่งทุกจุดบริการตาม** | พักหน้าจอเฉพาะเครื่องนี้ (ตื่นเองเมื่อมีคนแตะบัตร) |
| คลิก 3 ครั้ง | สลับธีมสว่าง/มืด **+ สั่งทุกจุดบริการตาม** | ขึ้นข้อความแจ้งว่าธีมถูกกำหนดจากแม่ข่าย |
| กดค้าง 1.5 วินาที | — | ขึ้นข้อความแจ้งว่าการแสดงผลถูกกำหนดจากแม่ข่าย |
| กดค้าง 3 วินาที | — | ตั้งหมายเลขจุดบริการ (1-4) |
| กดค้าง 5 วินาที | หน้าเครดิตผู้พัฒนา | หน้าเครดิตผู้พัฒนา |

### โหมดการแสดงผลถูกควบคุมจากเครื่องแม่ข่าย

เครื่องแม่ข่ายเป็นเจ้าของโหมดการแสดงผลของทั้งระบบ สั่งได้สองทาง คือหน้า **Settings**
บนเว็บ และปุ่มกดบนเครื่อง คำสั่งไปถึงจุดบริการผ่าน `HostConfigPacket` (`MSG_CONFIG`)
ทั้งแบบ broadcast ทันทีที่โหมดเปลี่ยน และย้ำอีกครั้งทุกครั้งที่ตอบ heartbeat
จุดบริการที่เพิ่งบูตหรือที่พลาดคำสั่ง broadcast จึงกลับมาตรงกับแม่ข่ายภายในไม่กี่วินาที

| สิ่งที่ซิงค์ | พฤติกรรม |
|---|---|
| ธีมสว่าง/มืด | **บังคับเสมอ** จุดบริการเปลี่ยนตามทุกครั้งที่ค่าไม่ตรงกับแม่ข่าย |
| โหมดพักหน้าจอ | ทำตามเมื่อแม่ข่ายเข้า/ออกโหมดพักหน้าจอ |
| ไฟหน้าจอ | ทำตามเมื่อเจ้าหน้าที่สั่งปิด/เปิดจอที่แม่ข่าย |

โหมดพักหน้าจอและไฟหน้าจอเป็นคำสั่งแบบ "สั่งเมื่อเปลี่ยน" (ดูจากค่า `modeSeq` ที่เพิ่มขึ้น)
ส่วนธีมเป็นคำสั่งแบบบังคับ

**เหตุผลที่ตัดการตั้งค่าฝั่งจุดบริการออก:** ถ้าแต่ละจุดตั้งเองได้ จอในโรงอาหารจะไม่เหมือนกัน
และคนที่มารับช่วงดูแลต่อจะไม่มีทางรู้ว่าใครไปกดอะไรไว้ที่เครื่องไหน

ข้อยกเว้นที่ตั้งใจไว้: ถ้ามีคนแตะบัตรขณะระบบพักหน้าจอ จุดบริการนั้นจะตื่นขึ้นแสดงผลทันที
และแม่ข่ายจะปลุกทุกจุดพร้อมกัน เพราะถือว่ากลับมาให้บริการแล้ว

---

## ข้อควรทราบด้านความปลอดภัย

- รหัสผ่านเจ้าหน้าที่เก็บเป็นข้อความธรรมดาใน `/admins.json` — เครื่องนี้จึงควรอยู่ในพื้นที่ควบคุม
- ESP-NOW ไม่ได้เข้ารหัส ผู้ที่อยู่ในระยะสามารถดักฟังหมายเลขบัตรได้
- Wi-Fi AP ใช้รหัสผ่านเริ่มต้น `12345678` และบัญชีเริ่มต้นคือ `admin` / `admin1234`
  **ทั้งสองอย่างควรเปลี่ยนก่อนเปิดใช้งานจริง**
- โทเคนเข้าสู่ระบบสุ่มจากตัวสุ่มในตัวชิป (`esp_random`) ไม่ใช่ `random()` ของ Arduino
  ที่ให้ลำดับเดิมทุกครั้งที่เปิดเครื่อง
- การดาวน์โหลดและลบไฟล์ประวัติรับเฉพาะชื่อ `arc_*` ในรากของ LittleFS เท่านั้น

รายละเอียดสิ่งที่แก้ไขทั้งหมดอยู่ใน [CHANGELOG.md](CHANGELOG.md)

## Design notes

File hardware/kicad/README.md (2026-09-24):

# ไฟล์วงจรสำหรับ KiCad

ไฟล์ในโฟลเดอร์นี้ **สร้างขึ้นอัตโนมัติ** จากผังขาในซอร์สของเฟิร์มแวร์
อย่าแก้ไฟล์ `.kicad_sch` ด้วยมือ เพราะจะถูกทับเมื่อสร้างใหม่

| ไฟล์ | คืออะไร |
|---|---|
| `Canteen_Host.kicad_pro` · `.kicad_sch` | วงจรของเครื่องแม่ข่าย เปิดด้วย KiCad ได้เลย |
| `Canteen_Station.kicad_pro` · `.kicad_sch` | วงจรของจุดบริการ |
| `MCUPR_Canteen.kicad_sym` | ไลบรารีสัญลักษณ์ เผื่ออยากเอาไปใช้ในงานอื่น |
| `*.net` | netlist ที่ KiCad เอ็กซ์พอร์ตออกมา ใช้ตรวจสอบและนำเข้า Pcbnew |
| `*.pdf` | ภาพวงจรสำหรับพิมพ์หรือส่งต่อ ไม่ต้องมี KiCad ก็เปิดดูได้ |
| `generate_kicad.py` | ตัวสร้างไฟล์ทั้งหมด |

## วิธีเปิด

ดับเบิลคลิก `Canteen_Station.kicad_pro` แล้วเปิดหน้า Schematic
**ไม่ต้องติดตั้งไลบรารีอะไรเพิ่ม** เพราะสัญลักษณ์ทุกตัวถูกฝังไว้ในไฟล์วงจรแล้ว
สร้างและทดสอบด้วย **KiCad 7** ส่วน KiCad 8 ขึ้นไปจะถามว่าจะอัปเกรดไฟล์หรือไม่ ตอบตกลงได้

## อ่านวงจรนี้อย่างไร

วงจรนี้ **ไม่ได้ลากเส้นยาวข้ามหน้า** แต่ใช้ **ป้ายชื่อเน็ต (global label)** แทน
ขาไหนที่มีป้ายชื่อเดียวกัน คือขาที่ต้องต่อถึงกัน เช่น ขา `GPIO14` ของบอร์ด
กับขา `SCL` ของจอ ต่างก็มีป้ายว่า `TFT_SCL` แปลว่าสองขานี้ต่อเข้าหากัน

วิธีนี้ตรงกับงานเดินสายจริงมากกว่าการลากเส้น เพราะสิ่งที่ช่างต้องรู้คือ
"ขานี้ไปขาไหน" ไม่ใช่ "เส้นวิ่งอ้อมทางไหน" และหน้ากระดาษก็ไม่รก

ขาที่มีเครื่องหมาย **✕** คือขาที่ตั้งใจไม่ต่ออะไร

## หมายเลขขาของบอร์ด ESP32-S3 DevKitC-1

สัญลักษณ์ `U1` นับขาแบบนี้ ให้หันด้านพอร์ต USB เข้าหาตัว

* **ขา 1 ถึง 22** คือแถวซ้าย ไล่จากบนลงล่าง เริ่มที่ `3V3` จบที่ `GND`
* **ขา 23 ถึง 44** คือแถวขวา ไล่จากบนลงล่าง เริ่มที่ `GND` จบที่ `GND`

เลขนี้ตรงกับตำแหน่งจริงบนบอร์ด และตรงกับตารางใน [`docs/HARDWARE.md`](../../docs/HARDWARE.md)

## รายการอุปกรณ์

| อ้างอิง | อุปกรณ์ | หมายเหตุ |
|---|---|---|
| `U1` | ESP32-S3 DevKitC-1 (N16R8) | 16 MB flash · 8 MB PSRAM แบบ OPI |
| `J2` | จอ ST7789 2.8" 320×240 | แปดขา ตรวจแรงดันก่อนจ่ายไฟ |
| `J3` (จุดบริการ) | MFRC522 13.56 MHz | ขา IRQ ไม่ได้ใช้ |
| `J3` (แม่ข่าย) | DS3231 ZS-042 | มีตัวต้านทานดึงขึ้น I2C บนโมดูลแล้ว ไม่ต้องใส่เพิ่ม |
| `J4` | ขั้วแบตเตอรี่ลิเธียม 1 เซลล์ | |
| `BZ1` | บัซเซอร์แบบพาสซีฟ | |
| `SW1` | สวิตช์กดติดปล่อยดับ | ใช้ตัวต้านทานดึงขึ้นภายในของชิป |
| `R1` `R2` | 100 kΩ 1% | วงจรแบ่งแรงดัน 1:2 สำหรับวัดแบตเตอรี่ |
| `C1` | 100 nF | กรองสัญญาณรบกวนที่จุดวัดแบตเตอรี่ |
| `C2` `C3` | 100 nF | กรองไฟเลี้ยงของโมดูล วางให้ชิดขาไฟของโมดูลที่สุด |

## สร้างไฟล์ใหม่และตรวจสอบ

```sh
python3 hardware/kicad/generate_kicad.py

cd hardware/kicad
kicad-cli sch export netlist --output Canteen_Host.net    Canteen_Host.kicad_sch
kicad-cli sch export netlist --output Canteen_Station.net Canteen_Station.kicad_sch
cd ../..

python3 tools/proto-check/kicadcheck.py
```

`kicadcheck.py` **ไม่ได้อ่านไฟล์วงจรตรง ๆ** แต่อ่าน netlist ที่ KiCad คำนวณออกมาเอง
แล้วเทียบกับค่าขาในซอร์สเฟิร์มแวร์ เท่ากับให้ KiCad เป็นคนยืนยันว่าเน็ตเชื่อมถึงกันจริง
จากนั้นตรวจสามข้อ

1. ทุกขาที่เฟิร์มแวร์ใช้ ต้องอยู่ในเน็ตชื่อเดียวกันในไฟล์วงจร
2. เน็ตสัญญาณต้องมีสองปลายพอดี ปลายเดียวคือลืมต่อ สามปลายคือชนกัน
3. ขา GPIO หนึ่งขาต้องไม่ไปโผล่อยู่สองเน็ต

## ข้อควรระวังก่อนลงมือประกอบ

* **แรงดันของจอ** จอ ST7789 บางรุ่นรับ 3.3V เท่านั้น ในวงจรต่อขา `VCC` ไว้ที่ `+3V3`
  ถ้าจอของท่านรับ 5V ได้และอยากใช้ 5V ให้ย้ายเอง **ตรวจสเปกก่อนจ่ายไฟทุกครั้ง**
* **บัซเซอร์ต่อตรงกับขา GPIO** ตามที่เครื่องต้นแบบใช้อยู่ ถ้าต้องการเสียงดังขึ้น
  ควรเพิ่มทรานซิสเตอร์ NPN กับตัวต้านทานฐาน แล้วให้ GPIO ขับฐานแทนการขับลำโพงตรง ๆ
* **วงจรแบ่งแรงดันกินไฟตลอดเวลา** ที่ 4.2V จะกินราว 21 µA ซึ่งน้อยมาก
  ถ้าต้องการประหยัดกว่านี้ให้เพิ่มมอสเฟตตัดวงจรตอนไม่ได้วัด

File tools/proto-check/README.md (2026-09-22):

# ตัวตรวจ forward declaration

Arduino IDE จะ **สร้างต้นแบบฟังก์ชัน (prototype) ให้เองอัตโนมัติ** แล้ววางไว้
ใกล้ ๆ หัวไฟล์ ซึ่งอยู่ **เหนือจุดที่นิยาม struct ของสเก็ตช์** ผลคือฟังก์ชันไหน
ที่รับ struct ของเราเป็นพารามิเตอร์แล้วไม่มีการประกาศล่วงหน้าไว้เอง จะคอมไพล์ไม่ผ่าน
ด้วยข้อความแบบนี้

```
error: variable or field 'fillStationConfig' declared void
error: 'HostConfigPacket' was not declared in this scope
```

วิธีแก้คือประกาศฟังก์ชันนั้นไว้ในบล็อก *Forward Declarations* (ซึ่งอยู่หลังนิยาม
โครงสร้างทั้งหมด) พอมีการประกาศไว้แล้ว Arduino จะไม่สร้างต้นแบบซ้อนให้อีก

สคริปต์นี้ไล่หาฟังก์ชันที่ยังขาดการประกาศ ใช้แทนการคอมไพล์จริงได้ในกรณีที่
เครื่องที่ใช้พัฒนาไม่มี toolchain ของ ESP32

## วิธีรัน

```sh
python3 tools/proto-check/protoscan.py \
  Canteen_Host_Server/Canteen_Host_Server.ino \
  Canteen_Station_Client/Canteen_Station_Client.ino
```

ได้ `ไม่พบปัญหา` ทั้งสองไฟล์แปลว่าผ่าน ถ้ามีรายการขึ้นมา ให้เอาชื่อฟังก์ชันนั้น
ไปเพิ่มในบล็อก Forward Declarations ของไฟล์นั้น (ฟังก์ชันที่เป็น `static`
ต้องประกาศเป็น `static` ด้วย)

## ข้อจำกัด

ตรวจเฉพาะฟังก์ชันที่เขียนนิยามโดยวงเล็บปีกกาเปิดอยู่บรรทัดเดียวกัน
ซึ่งเป็นรูปแบบที่ใช้ทั้งโครงการอยู่แล้ว

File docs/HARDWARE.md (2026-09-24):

# ผังการต่อสาย (Hardware Wiring)

> เอกสารนี้เป็นของ **Host 113.10.0 / Station 122.11.0** ขึ้นไป
> รุ่นก่อนหน้าใช้การจัดขาแบบเก่าซึ่งสายไขว้กันหลายเส้น ดู [`CHANGELOG.md`](../CHANGELOG.md)

ทั้งสองฝั่งใช้บอร์ดเดียวกันคือ **ESP32-S3 DevKitC-1 (N16R8)**
16 MB flash · 8 MB PSRAM แบบ OPI · Xtensa สองแกน 240 MHz

---

## หลักการจัดขาชุดนี้

1. **อุปกรณ์ภายนอกทุกตัวอยู่บนแถวซ้ายของบอร์ดแถวเดียว** แถวขวาไม่ได้ต่ออะไรเลย
   จึงเดินสายลงมาทางเดียว ไม่ต้องอ้อมหัวหรือท้ายบอร์ด
2. **ขาของโมดูลเดียวกันอยู่ติดกันเป็นกลุ่ม** และเรียงตามลำดับขาบนตัวโมดูลเอง
   สายของโมดูลหนึ่งจึงขนานกันทั้งชุด ไม่มีเส้นไหนไขว้ข้ามอีกเส้น
3. **บัซเซอร์ ปุ่มกด และสายวัดแบตเตอรี่ใช้ขาเดียวกันทั้งสองบอร์ด**
   ประกอบสายชุดเดียวแล้วสลับใช้ได้ทั้งเครื่องแม่ข่ายและจุดบริการ
4. **หลีกเลี่ยงขาต้องห้ามทั้งหมด** ดูรายการท้ายเอกสาร
   บังคับด้วย `tools/proto-check/pincheck.py` ซึ่งฟ้องทันทีถ้ามีใครย้ายขาไปโดน

---

## ผังรวมแถวซ้าย

นับตำแหน่งจาก **บนลงล่าง** ตามที่หันด้านพอร์ต USB เข้าหาตัว

| ตำแหน่ง | ขาบนบอร์ด | เครื่องแม่ข่าย | จุดบริการ |
|:---:|:---|:---|:---|
| 1 | `3V3` | ไฟเลี้ยงโมดูล | ไฟเลี้ยงโมดูล |
| 2 | `3V3` | ไฟเลี้ยงโมดูล | ไฟเลี้ยงโมดูล |
| 3 | `RST` | **ห้ามต่อ** ปุ่มรีเซ็ตของบอร์ด | **ห้ามต่อ** |
| 4 | `GPIO4` | DS3231 **SDA** | RC522 **SDA (SS)** |
| 5 | `GPIO5` | DS3231 **SCL** | RC522 **SCK** |
| 6 | `GPIO6` | การ์ด SD **SD_SCK** | RC522 **MOSI** |
| 7 | `GPIO7` | การ์ด SD **SD_MISO** | RC522 **MISO** |
| 8 | `GPIO15` | การ์ด SD **SD_MOSI** | RC522 **RST** |
| 9 | `GPIO16` | การ์ด SD **SD_CS** | ว่าง (คั่นกลุ่ม) |
| 10 | `GPIO17` | **บัซเซอร์** | **บัซเซอร์** |
| 11 | `GPIO18` | **ปุ่มกด** | **ปุ่มกด** |
| 12 | `GPIO8` | **วัดแบตเตอรี่** | **วัดแบตเตอรี่** |
| 13 | `GPIO3` | **ไม่ใช้** (strapping) | **ไม่ใช้** |
| 14 | `GPIO46` | **ไม่ใช้** (strapping) | **ไม่ใช้** |
| 15 | `GPIO9` | TFT **BLK** | TFT **BLK** |
| 16 | `GPIO10` | TFT **CS** | TFT **CS** |
| 17 | `GPIO11` | TFT **DC** | TFT **DC** |
| 18 | `GPIO12` | TFT **RES** | TFT **RES** |
| 19 | `GPIO13` | TFT **SDA** (MOSI) | TFT **SDA** (MOSI) |
| 20 | `GPIO14` | TFT **SCL** (SCLK) | TFT **SCL** (SCLK) |
| 21 | `5V0` | ไม่ได้ใช้ | ไม่ได้ใช้ |
| 22 | `GND` | กราวด์ร่วม | กราวด์ร่วม |

**แถวขวาไม่ได้ต่อสายอะไรเลย** มีแต่ `GPIO48` ซึ่งเป็นไฟ WS2812 บนบอร์ดอยู่แล้ว
ไม่ต้องเดินสายออกมา

---

## จอ ST7789 — เสียบตรงลงมาได้ทั้งแถว

โมดูลจอ 8 ขาที่ขายทั่วไปเรียงขาว่า
`GND · VCC · SCL · SDA · RES · DC · CS · BLK`

ถ้าอ่านตำแหน่งบนบอร์ด **จากล่างขึ้นบน** จะได้

```
ตำแหน่ง 22  GND    <-- GND ของจอ
ตำแหน่ง 21  5V0    <-- VCC ของจอ  (ดูหมายเหตุแรงดันข้างล่าง)
ตำแหน่ง 20  GPIO14 <-- SCL
ตำแหน่ง 19  GPIO13 <-- SDA
ตำแหน่ง 18  GPIO12 <-- RES
ตำแหน่ง 17  GPIO11 <-- DC
ตำแหน่ง 16  GPIO10 <-- CS
ตำแหน่ง 15  GPIO9  <-- BLK
```

**ตรงกันขาต่อขาทั้งแปดเส้น** สายแพเส้นเดียววางขนานลงมาได้เลย ไม่มีเส้นไหนไขว้

> ⚠️ **หมายเหตุเรื่องแรงดันของจอ**
> จอ ST7789 บางรุ่นรับได้ทั้ง 5V เพราะมีเรกูเลเตอร์ในตัว แต่บางรุ่นรับ **3.3V เท่านั้น**
> ถ้าจอของท่านเป็นแบบ 3.3V ให้ต่อ **VCC ไปที่ขา `3V3` ตำแหน่ง 1 หรือ 2 ด้านบน**
> แทนตำแหน่ง 21 ส่วนขาสัญญาณอีกหกเส้นยังเสียบตรงเหมือนเดิม
> **ตรวจสเปกจอของท่านก่อนจ่ายไฟทุกครั้ง**

---

## การ์ด SD — เฉพาะฝั่งแม่ข่าย

โมดูลจอบางรุ่นมีช่องเสียบการ์ด microSD อยู่ด้านหลัง **แต่หัวต่อของการ์ดเป็นคนละชุด
กับหัวแถว SPI ของจอ** อยู่คนละขอบของบอร์ด ต้องเดินสายเพิ่มอีกสี่เส้น

| ขาบนหัวต่อการ์ด | ต่อไปที่ | ตำแหน่ง |
|---|---|:---:|
| `SD_SCK` | `GPIO6` | 6 |
| `SD_MISO` | `GPIO7` | 7 |
| `SD_MOSI` | `GPIO15` | 8 |
| `SD_CS` | `GPIO16` | 9 |

**สี่สายไปสี่ขาที่เรียงติดกัน หนึ่งต่อหนึ่ง** และลำดับตรงกับลำดับขาบนตัวโมดูลพอดี
เสียบตรงลงมาได้โดยไม่ต้องแยกสายเลย

### ทำไมถึงแยกบัส ไม่ใช้ร่วมกับจอ

โมดูลแบบนี้ **ออกแบบมาให้แชร์บัสกับจอได้** และนั่นคือวิธีมาตรฐานในตำราทั่วไป
แต่ผังนี้เลือกให้การ์ดอยู่บนบัสของตัวเอง (HSPI) ด้วยเหตุผลสามข้อ

1. **เดินสายง่ายกว่า** การแชร์บัสต้องเอาสายสองเส้นยัดเข้าหัวต่อเดียวกันที่
   `GPIO13` กับ `GPIO14` ซึ่งเป็นจุดที่หลุดง่ายที่สุดในงานประกอบด้วยมือ
2. **สายหลุดเส้นเดียวไม่ดับทั้งคู่** ถ้าแชร์บัสแล้วสาย SCK หลุด จอกับการ์ดจะดับพร้อมกัน
3. **บัสของจอสะอาดเหมือนเดิม** ไลบรารี ST77xx ตั้งความเร็วไว้ที่ **32 MHz**
   การแตกแขนงสายเพิ่มที่ความถี่นั้นทำให้คุณภาพสัญญาณแย่ลง

ที่ทำได้เพราะแม่ข่ายใช้ SPI อยู่ตัวเดียวคือ FSPI ส่วน **HSPI ว่างสนิท**
เหตุผลที่ตำราส่วนใหญ่ให้แชร์บัสคือบอร์ดอย่าง Arduino Uno มีขาไม่พอ
ซึ่งไม่ใช่ข้อจำกัดของบอร์ดนี้

### การ์ดเป็นสำเนา ไม่ใช่ที่เก็บหลัก

**LittleFS ในบอร์ดยังเป็นที่เก็บหลักเหมือนเดิมทุกประการ** ออกแบบแบบนี้โดยตั้งใจ
เพราะการ์ดถอดออกได้ เสียได้ และไม่มีก็ได้ ถ้าให้การ์ดเป็นที่เก็บหลัก
วันที่ลืมเสียบการ์ดคือวันที่ระบบจ่ายอาหารไม่ได้

สิ่งที่ถูกเขียนลงการ์ด

| ไฟล์บนการ์ด | เขียนเมื่อไร |
|---|---|
| `/canteen/daily_log.csv` | ทุกครั้งที่มีนิสิตรับสิทธิ์สำเร็จ |
| `/canteen/arc_YYYYMMDD_HHMMSS.csv` | ตอนปิดยอดประจำวัน |
| `/canteen/students_backup.csv` | ทุกครั้งที่ทะเบียนนิสิตเปลี่ยน |

ถ้าไม่มีการ์ด ระบบข้ามการเขียนไปเฉย ๆ และลองเมานต์ใหม่ทุกสามสิบวินาที
เสียบการ์ดทีหลังได้โดยไม่ต้องรีบูต สถานะดูได้ที่หน้าตั้งค่าบนเว็บ

> การ์ดต้องฟอร์แมตเป็น **FAT32** และควรใช้ความจุไม่เกิน 32 GB

---

## RC522 — เฉพาะฝั่งจุดบริการ

โมดูล RC522 เรียงขาว่า
`SDA · SCK · MOSI · MISO · IRQ · GND · RST · 3.3V`

| ขาบนโมดูล | ต่อไปที่ | ตำแหน่ง |
|---|---|:---:|
| SDA (SS) | `GPIO4` | 4 |
| SCK | `GPIO5` | 5 |
| MOSI | `GPIO6` | 6 |
| MISO | `GPIO7` | 7 |
| IRQ | **ไม่ต่อ** | — |
| GND | รางกราวด์ | — |
| RST | `GPIO15` | 8 |
| 3.3V | รางไฟ 3.3V | — |

สี่เส้นแรกเสียบตรงลงมาที่ตำแหน่ง 4 ถึง 7 พอดี ส่วน RST ข้าม IRQ กับ GND
ลงมาที่ตำแหน่ง 8 **ลำดับยังเรียงลงทางเดียวกัน จึงไม่มีเส้นไหนไขว้กัน**

> **สำคัญ:** บน ESP32-S3 ตัวแปร `SPI` มาตรฐานผูกกับ FSPI (SPI2_HOST)
> และไลบรารี MFRC522 เรียกใช้ตัวแปรนั้น **จอจึงต้องอยู่บน HSPI (SPI3_HOST)**
> ไม่งั้นอุปกรณ์สองตัวจะแย่ง peripheral เดียวกันคนละขา และจอจะเพี้ยนทันทีหลัง `PCD_Init()`
> เรื่องนี้กำหนดไว้ในโค้ดแล้วด้วยบรรทัด `SPIClass SPI_TFT(HSPI);`

---

## ไฟเลี้ยงและกราวด์

บอร์ดรุ่นนี้วาง `3V3` ไว้บนสุดของแถวซ้าย ส่วน `GND` อยู่ล่างสุด
ถ้าโมดูลอยู่คนละปลาย สายไฟกับสายกราวด์จะต้องวิ่งยาวข้ามสายสัญญาณ

**วิธีที่แนะนำคือทำรางไฟเล็ก ๆ** สองแถวไว้ข้างบอร์ด แถวหนึ่งเป็น 3.3V อีกแถวเป็นกราวด์
แล้วลากจากบอร์ดไปรางแถวละเส้นเดียว จากนั้นทุกโมดูลดึงไฟและกราวด์จากรางแทน
สายสัญญาณจึงเป็นสายสั้น ๆ ขนานกันทั้งหมด และเหลือสายยาวแค่สองเส้น

---

## ขาที่ห้ามต่ออุปกรณ์บนรุ่น N16R8

| ขา | เหตุผล |
|---|---|
| `GPIO26`–`GPIO32` | ขาของ SPI flash บนโมดูล |
| `GPIO33`–`GPIO37` | **ขาของ PSRAM แบบ OPI** ต่ออะไรลงไปแล้วหน่วยความจำเสียหาย |
| `GPIO19` · `GPIO20` | USB D- และ D+ ใช้แล้วพอร์ต USB ของบอร์ดใช้ไม่ได้ |
| `GPIO43` · `GPIO44` | U0TXD และ U0RXD ของ Serial Monitor |
| `GPIO0` | ขา strapping และปุ่ม BOOT |
| `GPIO3` | ขา strapping เลือกแหล่ง JTAG |
| `GPIO45` | ขา strapping กำหนดแรงดัน VDD_SPI |
| `GPIO46` | ขา strapping เปิดปิดข้อความจาก ROM |

`GPIO35` `GPIO36` `GPIO37` **โผล่อยู่บนแถวขวาของบอร์ดและดูเหมือนใช้ได้**
แต่บนรุ่น N16R8 สามขานี้ถูก PSRAM จองไว้แล้ว เป็นกับดักที่เจอบ่อยที่สุด

### เรื่องที่ต้องระวังเพิ่ม

* **วัดแรงดันแบตเตอรี่ต้องใช้ขาใน ADC1 เท่านั้น** คือ `GPIO1` ถึง `GPIO10`
  เพราะ **ADC2 อ่านค่าไม่ได้ขณะเปิด Wi-Fi** ซึ่งเครื่องนี้เปิดตลอดเวลา
  ผังชุดนี้ใช้ `GPIO8` (ADC1_CH7) ทั้งสองบอร์ด
* **ไฟ WS2812 บนบอร์ด** รุ่น v1.1 ใช้ `GPIO48` ส่วนรุ่น v1.0 ใช้ `GPIO38`
  โค้ดตั้งไว้ที่ `GPIO48` ถ้าไฟไม่ติดให้แก้ `RGB_LED_PIN` เป็น `38`
* ตัวแบ่งแรงดันของแบตเตอรี่เป็นอัตราส่วน **1:2** และโค้ดตั้ง `analogSetAttenuation(ADC_11db)` ไว้แล้ว

---

## ไฟล์วงจรสำหรับ KiCad

ผังเดียวกันนี้มีเป็น **ไฟล์วงจรที่ KiCad เปิดได้จริง** อยู่ที่
[`hardware/kicad/`](../hardware/kicad/) พร้อมไฟล์ PDF สำหรับพิมพ์
สัญลักษณ์ทุกตัวฝังอยู่ในไฟล์แล้ว เปิดได้โดยไม่ต้องติดตั้งไลบรารีเพิ่ม

ไฟล์เหล่านั้น **สร้างจากผังขาในซอร์สของเฟิร์มแวร์โดยตรง** ไม่ได้วาดมือ
จึงไม่มีทางเพี้ยนจากของจริง และมีตัวตรวจ `kicadcheck.py` คอยยืนยันอีกชั้น

---

## ตรวจแล้วว่าไม่ทับบริการของบอร์ด

`ESP32-S3-DevKitC-1` ต่ออุปกรณ์ของตัวเองไว้เพียงห้าจุด นอกจากนี้ขาว่างหมด

| ขา | บอร์ดใช้ทำอะไร | ผังนี้ใช้ไหม |
|---|---|---|
| `GPIO0` | ปุ่ม BOOT | **ไม่ใช้** |
| `GPIO19` · `GPIO20` | USB D- และ D+ | **ไม่ใช้** |
| `GPIO43` · `GPIO44` | UART ของตัวแปลง USB สำหรับแฟลชและ Serial Monitor | **ไม่ใช้** |
| `GPIO48` | ไฟ WS2812 บนบอร์ด | **ใช้ และตั้งใจใช้** |
| `GPIO26`–`GPIO37` | แฟลชกับ PSRAM ภายในโมดูล | **ไม่ใช้** |

จุดเดียวที่ซ้อนกันคือ `GPIO48` ซึ่งเป็นไฟ WS2812 ที่เราตั้งใจใช้อยู่แล้ว
**ไม่ได้ต่อสายออกมา** เพราะมันอยู่บนบอร์ด

ขาที่ผังนี้ใช้ทั้งหมดอยู่ในช่วง `GPIO4` ถึง `GPIO18` ซึ่งบนบอร์ดรุ่นนี้
**ไม่ได้ต่อกับอะไรเลย** เป็นขาเปล่าที่ออกมาที่หัวต่อโดยตรง

### สองจุดที่ต้องรู้ไว้ แต่ไม่ถึงกับห้าม

* **`GPIO15` และ `GPIO16`** มีหน้าที่สำรองเป็นขาคริสตัล 32.768 kHz
  ใช้ได้ปกติเพราะ DevKitC-1 มาตรฐาน **ไม่ได้ติดคริสตัลตัวนั้นมา**
  และถึงมีก็ไม่กระทบ เพราะเวลาของระบบมาจาก DS3231 ไม่ได้มาจากคริสตัลในชิป
* **`GPIO17` และ `GPIO18`** มีหน้าที่สำรองเป็น `U1TXD` กับ `U1RXD`
  ใช้ได้เพราะโปรเจกต์นี้ **ไม่ได้ใช้ `Serial1` เลย** ตรวจได้ด้วยการค้นหาในซอร์ส

ดูตารางเต็มที่ระบุหน้าที่ประจำของทุกขาที่ใช้ได้จาก

```sh
python3 tools/proto-check/pincheck.py
```

---

## เรื่องไฟเลี้ยงที่ต้องเผื่อไว้

ขาสัญญาณไม่ทับกันแล้ว แต่ **ไฟเลี้ยงเป็นอีกเรื่องหนึ่ง** ทุกโมดูลกินไฟจาก
ตัวควบคุมแรงดัน 3.3V ตัวเดียวบนบอร์ด และโหลดที่กินเป็นจังหวะมีหลายตัวพร้อมกัน

| ตัวกิน | ลักษณะการกิน |
|---|---|
| ESP32-S3 ตอนส่ง Wi-Fi | พุ่งเป็นจังหวะสั้น ๆ ระดับหลายร้อยมิลลิแอมป์ |
| **การ์ด SD ตอนเขียน** | พุ่งได้หลายสิบถึงร้อยมิลลิแอมป์ ขึ้นกับยี่ห้อการ์ด |
| RC522 ตอนอ่านบัตร | พุ่งเป็นจังหวะ |
| ไฟส่องหลังจอ | กินต่อเนื่อง |

จังหวะที่แย่ที่สุดคือ **นิสิตแตะบัตรแล้วระบบเขียนการ์ดพอดีกับที่ Wi-Fi ส่งออก**
ถ้าแรงดันตกชั่วขณะ บอร์ดอาจรีบูตเอง ซึ่งเป็นอาการที่หาสาเหตุยากมาก

ข้อแนะนำ

1. ใส่ **ตัวเก็บประจุ 100 µF** คร่อมไฟ 3.3V กับกราวด์ **ให้ใกล้ช่องเสียบการ์ดที่สุด**
   เพิ่มจากตัว 100 nF ที่มีอยู่แล้วในวงจร ตัวใหญ่รับกระแสพุ่ง ตัวเล็กกรองความถี่สูง
2. จ่ายไฟเข้าบอร์ดด้วยอะแดปเตอร์ 5V ที่จ่ายได้อย่างน้อย **2 A**
   ไม่ใช่พอร์ต USB ของคอมพิวเตอร์หรือที่ชาร์จโทรศัพท์กำลังต่ำ
3. ถ้าใช้สาย USB ยาว ให้เปลี่ยนเป็นสายสั้นและหนา สายบางทำให้แรงดันตกที่ปลายทาง

### ไฟส่องหลังจอ

ขา `BLK` ของโมดูลจอบางรุ่นต่อเข้าทรานซิสเตอร์บนโมดูลเองแล้ว บางรุ่นต่อตรงเข้าหลอด
ถ้าเป็นแบบหลัง กระแสอาจเกินที่ขา GPIO ขับไหวสบาย ๆ
**วัดด้วยมัลติมิเตอร์ก่อนใช้งานจริง** ถ้าเกิน 20 mA ให้เพิ่มทรานซิสเตอร์ขับ
หรือต่อ `BLK` ไปที่ 3.3V ตรง ๆ แล้วยอมให้ไฟส่องหลังติดตลอด

---

## ตรวจก่อนจ่ายไฟ

```sh
python3 tools/proto-check/pincheck.py
```

ตัวตรวจนี้อ่านค่าขาจากซอร์สจริงของทั้งสองบอร์ด แล้วฟ้องเมื่อ

* มีขาไหนถูกใช้ซ้ำสองหน้าที่ในบอร์ดเดียวกัน
* มีขาไหนไปโดนรายการต้องห้ามข้างบน
* ขาวัดแบตเตอรี่ไม่ได้อยู่ใน ADC1

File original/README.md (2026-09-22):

# ต้นฉบับของเฟิร์มแวร์ก่อนแก้ไข (Baseline)

โฟลเดอร์นี้เก็บ **โค้ดต้นฉบับที่ส่งมาให้ตอนเริ่มโครงการ** ไว้ตามเดิมทุกไบต์
เพื่อให้ย้อนดูได้เสมอว่าจุดเริ่มต้นของระบบเขียนมาแบบไหน และการแก้ไขแต่ละครั้ง
เปลี่ยนอะไรไปบ้างเมื่อเทียบกับของเดิม

| ไฟล์ | เวอร์ชัน | ขนาด |
|---|---|---|
| `Canteen_Host_Server/Canteen_Host_Server.ino` | 107.0.1 | 3,207 บรรทัด |
| `Canteen_Station_Client/Canteen_Station_Client.ino` | 117.0.7 | 1,629 บรรทัด |

## ข้อควรระวัง

> **ห้ามแก้ไฟล์ในโฟลเดอร์นี้** ถ้าแก้แล้วจะหมดความหมายของการเก็บต้นฉบับ
> โค้ดที่ใช้งานจริงและพัฒนาต่ออยู่ที่ `Canteen_Host_Server/` และ
> `Canteen_Station_Client/` ที่โฟลเดอร์หลักของโครงการ

ทั้งสองไฟล์วางไว้ในโฟลเดอร์ที่ชื่อตรงกับชื่อไฟล์ จึงเปิดด้วย Arduino IDE
และคอมไพล์ได้ทันทีถ้าต้องการย้อนกลับไปใช้ของเดิมจริง ๆ

## เทียบกับของเดิมอย่างไร

ดูความต่างทั้งหมดตั้งแต่ต้นจนถึงตอนนี้:

```sh
diff -u original/Canteen_Host_Server/Canteen_Host_Server.ino \
        Canteen_Host_Server/Canteen_Host_Server.ino | less

diff -u original/Canteen_Station_Client/Canteen_Station_Client.ino \
        Canteen_Station_Client/Canteen_Station_Client.ino | less
```

หรือดูผ่าน git ซึ่งเก็บต้นฉบับไว้เป็นคอมมิตแรกของโครงการด้วย
(คอมมิต `b351769`)

```sh
git diff b351769 HEAD -- Canteen_Host_Server/
```

## สิ่งที่พบในต้นฉบับ

รายการข้อผิดพลาดและช่องโหว่ที่ตรวจพบในโค้ดชุดนี้ พร้อมวิธีแก้ทีละข้อ
อยู่ในหัวข้อท้าย ๆ ของ [`../CHANGELOG.md`](../CHANGELOG.md)
(หัวข้อ *Host Server 108.0.0 / Station Client 118.0.0*)

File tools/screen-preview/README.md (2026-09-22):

# ตัวจำลองหน้าจอ TFT

วาดหน้าจอของทั้งสองฝั่งลงบนผืนผ้าใบในเบราว์เซอร์ ด้วยพรีมิทีฟชุดเดียวกับ
Adafruit GFX (`fillRect`, `drawRoundRect`, `setCursor`, ฟอนต์กว้าง 6 พิกเซลต่อขนาด 1)
ที่ความละเอียด 320x240 เท่าจอจริง

มีไว้ดูหน้าตาและตรวจว่าตัวอักษรไม่ล้นกรอบ **โดยไม่ต้องแฟลชลงบอร์ด**

> ⚠️ **นี่คือสำเนาที่เขียนตามโค้ดเฟิร์มแวร์ ไม่ใช่ตัวเฟิร์มแวร์เอง**
> ถ้าแก้หน้าจอใน `HostScreen.h` หรือ `StationScreen.h` แล้วไม่แก้ที่นี่ด้วย
> ภาพที่เห็นจะไม่ตรงกับของจริง **อย่าเชื่อภาพจากที่นี่แทนการทดสอบบนเครื่องจริง**

## ใช้อย่างไร

```sh
cd tools/screen-preview
python3 -m http.server 8099      # แล้วเปิด http://127.0.0.1:8099/tft.html
```

## ตรวจว่าการวาดบางส่วนไม่ทิ้งเศษพิกเซล

หน้าจอ MCU ไม่วาดใหม่ทั้งหน้าทุกครั้ง แต่วาดซ้ำเฉพาะช่องที่ค่าเปลี่ยน
ถ้าช่องที่ล้างเล็กกว่าตัวเลขเดิม จะเหลือเศษพิกเซลค้างบนจอ

`run_partial.mjs` ทดสอบให้อัตโนมัติ โดยวาดเต็มหน้าด้วยค่า ก. แล้วเทียบกับ
การวาดเต็มหน้าด้วยค่า ข. กับการวาดค่า ก. แล้วแก้เฉพาะช่องเป็นค่า ข.
**สองภาพต้องตรงกันทุกพิกเซล** ทดสอบทั้งโหมดมืดและโหมดสว่าง

```sh
cd tools/screen-preview
python3 -m http.server 8099 &
node run_partial.mjs
```

ตัวทดสอบนี้จับบั๊กจริงมาแล้ว: การเปลี่ยนป้าย ONLINE เป็น OFFLINE
ทิ้งสีเขียวค้างไว้ที่มุมโค้งทั้งสี่ของป้าย เพราะ `fillRoundRect` ไม่ได้ลงสีที่มุม
จึงต้องล้างกรอบสี่เหลี่ยมเต็ม ๆ ก่อนวาดป้ายใหม่

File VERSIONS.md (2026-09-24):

# สารบัญเวอร์ชัน (Release Index)

ทุกจุดที่เลขเวอร์ชันของฝั่งใดฝั่งหนึ่งเปลี่ยน ถูกชี้ตำแหน่งไว้ที่นี่
เพื่อให้ **ย้อนกลับไปใช้ชุดที่สมบูรณ์ชุดไหนก็ได้** โดยไม่ต้องไล่หาคอมมิตเอง

หนึ่งรุ่นคือ **เฟิร์มแวร์ครบทั้งคู่** ทั้งฝั่งแม่ข่ายและฝั่งสถานี
ที่ทดสอบและจัดทำเอกสารมาด้วยกัน — ไม่ควรจับคู่ข้ามรุ่น เพราะโปรโตคอล
ESP-NOW ระหว่างสองฝั่งเปลี่ยนไปในบางรุ่น

ทุกรุ่นถูก push ขึ้น GitHub ไว้เป็น **branch** ใต้โฟลเดอร์ `release/`
กดโหลดเป็นไฟล์ zip จากตารางข้างล่างได้เลย ไม่ต้องใช้คำสั่ง git

### โครงสร้าง branch ของ repository

```
main                              branch หลัก งานล่าสุดทั้งหมดอยู่ที่นี่
claude/fervent-wozniak-66knt2     branch ที่ Claude ใช้พัฒนา ชี้คอมมิตเดียวกับ main
release/00-h107.0.1-s117.0.7      หมุดเวลาของแต่ละรุ่น ห้ามแก้ ห้าม push ทับ
release/01-h107.0.1-s118.0.0
release/02-h108.0.0-s118.0.0
release/03-h108.0.0-s118.1.0
release/04-h108.0.0-s118.2.0
release/05-h108.0.0-s119.0.0
release/06-h109.0.0-s119.0.0
release/07-h110.0.1-s120.0.0
release/08-h110.0.2-s120.0.1
release/09-h111.0.0-s120.0.1
release/10-h111.1.0-s120.0.1
release/11-h112.0.0-s121.0.0
release/12-h113.0.0-s122.0.0
release/13-h113.1.0-s122.0.0
release/14-h113.1.0-s122.1.0
release/15-h113.1.0-s122.1.0-docs
release/16-h113.2.0-s122.2.0
release/17-h113.3.0-s122.3.0
release/18-h113.4.0-s122.4.0
release/19-h113.5.0-s122.5.0
release/20-h113.6.0-s122.5.0
release/21-h113.6.0-s122.6.0
release/22-h113.6.0-s122.6.1
release/23-h113.6.0-s122.6.2
release/24-h113.7.0-s122.7.0
release/25-h113.8.0-s122.8.0
release/26-h113.8.0-s122.9.0
release/27-h113.9.0-s122.10.0
release/28-h113.10.0-s122.11.0
release/29-h113.10.0-s122.12.0
release/30-h113.11.0-s122.12.0
release/31-h113.12.0-s122.12.0
```

> หมายเหตุ: ปกติงานลักษณะนี้ควรเป็น **tag** ไม่ใช่ branch แต่บัญชีที่เซสชันนี้ใช้
> push `refs/tags/*` ไม่ได้ เซิร์ฟเวอร์ตอบ 403 ทุกครั้ง จึงใช้ branch แทน
> ได้ผลเหมือนกันทุกอย่างสำหรับการย้อนกลับ
> ถ้าอยากได้ tag จริงด้วย รันคำสั่งในหัวข้อ **สร้างแท็กเอง** ครั้งเดียวจบ
>
> **branch เหล่านี้ห้ามแก้และห้าม push ทับ** ให้ถือเป็นหมุดเวลาอย่างเดียว
> งานที่พัฒนาต่ออยู่ที่ `main`

| ชื่อรุ่น | Host | Station | คอมไพล์ | โหลด zip | คอมมิต | สาระสำคัญ |
|---|---|---|---|---|---|---|
| `release/00-h107.0.1-s117.0.7` | 107.0.1 | 117.0.7 | ✅ | [zip](https://github.com/kittiphun-rut/MCUPR-CANTEEN/archive/refs/heads/release/00-h107.0.1-s117.0.7.zip) | [`b351769`](https://github.com/kittiphun-rut/MCUPR-CANTEEN/tree/b3517697c239e72ce180c0759843973b8903d7bf) | **ต้นฉบับตามที่ส่งมา** ยังไม่แก้อะไรเลย เก็บสำเนาไว้ที่ [`original/`](original/) ด้วย<br><sub>21 ก.ย. 2026</sub> |
| `release/01-h107.0.1-s118.0.0` | 107.0.1 | 118.0.0 | ✅ | [zip](https://github.com/kittiphun-rut/MCUPR-CANTEEN/archive/refs/heads/release/01-h107.0.1-s118.0.0.zip) | [`8a20d11`](https://github.com/kittiphun-rut/MCUPR-CANTEEN/tree/8a20d11c8268e7102bd789f66c212bea5e83f9fc) | ฝั่งสถานี: แยกบัส SPI ของจอกับเครื่องอ่านบัตร (จอเพี้ยนหลัง `PCD_Init()`), ซ่อมสถานะลิงก์สด, รับคำสั่งสลับธีมจากแม่ข่าย<br><sub>21 ก.ย. 2026</sub> |
| `release/02-h108.0.0-s118.0.0` | 108.0.0 | 118.0.0 | ✅ | [zip](https://github.com/kittiphun-rut/MCUPR-CANTEEN/archive/refs/heads/release/02-h108.0.0-s118.0.0.zip) | [`eec7139`](https://github.com/kittiphun-rut/MCUPR-CANTEEN/tree/eec713955d9c3fd56498f801d28f0bdd6d0f4662) | ฝั่งแม่ข่าย: ปิดช่องโหว่ความปลอดภัย, ซ่อม CSV และเลขอ้างอิง, ยกเครื่องเว็บพอร์ทัลให้อัปเดตสด, แยกหน้าเว็บออกเป็น `WebPortal.h`, เพิ่มจอสาธารณะ `/display`<br><sub>21 ก.ย. 2026</sub> |
| `release/03-h108.0.0-s118.1.0` | 108.0.0 | 118.1.0 | ❌ | [zip](https://github.com/kittiphun-rut/MCUPR-CANTEEN/archive/refs/heads/release/03-h108.0.0-s118.1.0.zip) | [`a883805`](https://github.com/kittiphun-rut/MCUPR-CANTEEN/tree/a883805c9283a80f4240d1d90b7a971217f1a5b5) | ซิงค์โหมดการแสดงผลจากแม่ข่ายไปทุกสถานี, แก้พอร์ทัลใช้งานไม่ได้ในหน้าต่าง captive portal, เพิ่มสัญลักษณ์ RFID บนหน้าแรกของสถานี<br><sub>21 ก.ย. 2026</sub> |
| `release/04-h108.0.0-s118.2.0` | 108.0.0 | 118.2.0 | ❌ | [zip](https://github.com/kittiphun-rut/MCUPR-CANTEEN/archive/refs/heads/release/04-h108.0.0-s118.2.0.zip) | [`1ca1c8a`](https://github.com/kittiphun-rut/MCUPR-CANTEEN/tree/1ca1c8ac3f8d21df85a88f87a076334e787bf659) | เติมข้อมูลหน้า 2 ของสถานีให้เต็มจอและเป็นข้อมูลสด (ยอดทั้งโรงอาหาร + รายการที่จ่ายล่าสุด)<br><sub>21 ก.ย. 2026</sub> |
| `release/05-h108.0.0-s119.0.0` | 108.0.0 | 119.0.0 | ❌ | [zip](https://github.com/kittiphun-rut/MCUPR-CANTEEN/archive/refs/heads/release/05-h108.0.0-s119.0.0.zip) | [`6620ab5`](https://github.com/kittiphun-rut/MCUPR-CANTEEN/tree/6620ab5382a80fa3a9519bbb75f90561896788f5) | เสริมความทนทานของลิงก์สำหรับระยะ 20 เมตร และเพิ่ม **คิวออฟไลน์** ฝั่งสถานี<br><sub>21 ก.ย. 2026</sub> |
| `release/06-h109.0.0-s119.0.0` | 109.0.0 | 119.0.0 | ❌ | [zip](https://github.com/kittiphun-rut/MCUPR-CANTEEN/archive/refs/heads/release/06-h109.0.0-s119.0.0.zip) | [`c3584ff`](https://github.com/kittiphun-rut/MCUPR-CANTEEN/tree/c3584ffe8522ec5314dd960944e6ae16a2df569a) | เพิ่ม **เครื่องพิมพ์สลิปความร้อน 58 มม.** (`ThermalPrinter.h`) ผ่าน USB OTG หรือ UART<br><sub>21 ก.ย. 2026</sub> |
| `release/07-h110.0.1-s120.0.0` | 110.0.1 | 120.0.0 | ❌ | [zip](https://github.com/kittiphun-rut/MCUPR-CANTEEN/archive/refs/heads/release/07-h110.0.1-s120.0.0.zip) | [`7fd0e20`](https://github.com/kittiphun-rut/MCUPR-CANTEEN/tree/7fd0e20) | **ตรวจสิทธิ์ได้เองตอนลิงก์ขาด** ด้วยบัญชีสิทธิ์ย่อที่แม่ข่ายผลักไปเก็บที่สถานี<br><sub>22 ก.ย. 2026</sub> |
| `release/08-h110.0.2-s120.0.1` | 110.0.2 | 120.0.1 | ✅ | [zip](https://github.com/kittiphun-rut/MCUPR-CANTEEN/archive/refs/heads/release/08-h110.0.2-s120.0.1.zip) | [`b7dfc73`](https://github.com/kittiphun-rut/MCUPR-CANTEEN/tree/b7dfc734119d9352e1c4e2de58a9e684670a343c) | **แก้ให้คอมไพล์ผ่าน Arduino IDE** — เพิ่ม forward declaration ที่ขาดสองจุด ฟีเจอร์เท่ากับ `release/07` ทุกอย่าง<br><sub>22 ก.ย. 2026</sub> |
| `release/09-h111.0.0-s120.0.1` | 111.0.0 | 120.0.1 | ✅ | [zip](https://github.com/kittiphun-rut/MCUPR-CANTEEN/archive/refs/heads/release/09-h111.0.0-s120.0.1.zip) | [`4ade160`](https://github.com/kittiphun-rut/MCUPR-CANTEEN/tree/4ade160790e7f5dd9c22b044dd1ec9f31f60fb70) | **ปิดเครื่องพิมพ์สลิปเป็นค่าเริ่มต้น** เพื่อลดขนาดเฟิร์มแวร์ ฟีเจอร์เดิมคงไว้ครบทุกอย่าง เปิดกลับได้ด้วยการแก้ `#define` บรรทัดเดียว<br><sub>22 ก.ย. 2026</sub> |
| `release/10-h111.1.0-s120.0.1` | 111.1.0 | 120.0.1 | ✅ | [zip](https://github.com/kittiphun-rut/MCUPR-CANTEEN/archive/refs/heads/release/10-h111.1.0-s120.0.1.zip) | [ล่าสุดของ branch นี้](https://github.com/kittiphun-rut/MCUPR-CANTEEN/tree/release/10-h111.1.0-s120.0.1) | **แยกไฟล์หลักให้เหลือ 2,674 บรรทัด** ย้ายส่วนวาดจอไป `HostDisplay.h` และเนื้อหาสลิปไป `HostSlips.h` เป็นการย้ายที่อยู่ล้วน ๆ ตรรกะไม่เปลี่ยน<br><sub>22 ก.ย. 2026</sub> |

| `release/11-h112.0.0-s121.0.0` | 112.0.0 | 121.0.0 | ✅ | [zip](https://github.com/kittiphun-rut/MCUPR-CANTEEN/archive/refs/heads/release/11-h112.0.0-s121.0.0.zip) | [`427e5d4`](https://github.com/kittiphun-rut/MCUPR-CANTEEN/tree/427e5d499f3dde2921b1fac6c9f8b9882c37a870) | **แก้ปัญหาชื่อ Wi-Fi ไม่โผล่มา** ปิด `WIFI_PROTOCOL_LR` เป็นค่าเริ่มต้น ย้าย `printerBegin()` ไปหลังเว็บเซิร์ฟเวอร์ และเพิ่มจอแจ้งสถานะเครือข่ายตอนบูต<br><sub>22 ก.ย. 2026</sub> |
| `release/12-h113.0.0-s122.0.0` | 113.0.0 | 122.0.0 | ❔ | [zip](https://github.com/kittiphun-rut/MCUPR-CANTEEN/archive/refs/heads/release/12-h113.0.0-s122.0.0.zip) | [`7f4fed9`](https://github.com/kittiphun-rut/MCUPR-CANTEEN/tree/7f4fed947d667942dbf3e8ceccf1079165cfda96) | **เริ่มใหม่จากต้นฉบับ 107.0.1/117.0.7** แล้วรื้ออินเตอร์เฟสทั้งหมดเป็นภาษาอังกฤษสองโหมด แยกไฟล์แดชบอร์ดและไฟล์วาดจอออกมา แม่ข่ายคุมการแสดงผลของทุกจุดบริการ **ยังไม่มีเครื่องพิมพ์สลิป คิวออฟไลน์ และจอสาธารณะ**<br><sub>22 ก.ย. 2026</sub> |

| `release/13-h113.1.0-s122.0.0` | 113.1.0 | 122.0.0 | ❔ | [zip](https://github.com/kittiphun-rut/MCUPR-CANTEEN/archive/refs/heads/release/13-h113.1.0-s122.0.0.zip) | [`b18a20c`](https://github.com/kittiphun-rut/MCUPR-CANTEEN/tree/b18a20cb0929869e58c711e713fab3f6268c5a3f) | **หน้าเว็บกลับมาเป็นสองภาษา ไทย/อังกฤษ** คำไทยอยู่ในพจนานุกรมชุดเดียว ไม่ได้เขียนซ้ำสองชุดทุกบรรทัดแบบรุ่นเก่า · ฝั่งจอ TFT ยังเป็นอังกฤษ · เพิ่มตัวตรวจคำพูดไม่ครบคู่ใน bracecheck<br><sub>22 ก.ย. 2026</sub> |

| `release/14-h113.1.0-s122.1.0` | 113.1.0 | 122.1.0 | ❔ | [zip](https://github.com/kittiphun-rut/MCUPR-CANTEEN/archive/refs/heads/release/14-h113.1.0-s122.1.0.zip) | [`0a4bd73`](https://github.com/kittiphun-rut/MCUPR-CANTEEN/tree/0a4bd7397e8102e8c929b02df0e71965e987ec8a) | **แยกส่วนวาดจอของฝั่งจุดบริการออกเป็น `StationScreen.h`** ไฟล์หลักเหลือ 1,141 บรรทัด ย้ายแบบยกก้อน ไม่แก้เนื้อใน · เพิ่มเครื่องมือ `splitcheck.py` ตรวจปัญหาจากการแยกไฟล์<br><sub>22 ก.ย. 2026</sub> |

| `release/15-h113.1.0-s122.1.0-docs` | 113.1.0 | 122.1.0 | ❔ | [zip](https://github.com/kittiphun-rut/MCUPR-CANTEEN/archive/refs/heads/release/15-h113.1.0-s122.1.0-docs.zip) | [`3d8a123`](https://github.com/kittiphun-rut/MCUPR-CANTEEN/tree/3d8a12324dd3261527af9bf94af9fc76b7b5620e) | **มาตรฐานคอมเมนต์แบบ Doxygen** หัวไฟล์มีตารางประวัติการแก้ไข และป้าย `// [เวอร์ชัน] เพิ่ม/แก้/ย้าย` ในเนื้อโค้ด · เพิ่ม `headercheck.py` บังคับใช้ · **แตะแต่คอมเมนต์ ตรรกะเหมือน `release/14` ทุกบรรทัด**<br><sub>22 ก.ย. 2026</sub> |

| `release/16-h113.2.0-s122.2.0` | 113.2.0 | 122.2.0 | ❔ | [zip](https://github.com/kittiphun-rut/MCUPR-CANTEEN/archive/refs/heads/release/16-h113.2.0-s122.2.0.zip) | [`beda1b4`](https://github.com/kittiphun-rut/MCUPR-CANTEEN/tree/beda1b4c5d6f682d200c53eec77cb17fd8cb0119) | **ซ่อมการรีเฟรชตัวเลขบนจอทั้งสองฝั่ง** ยอดรายร้าน หน้า SYSTEM นาฬิกาของจุดบริการ และแถบสัญญาณที่ไม่เคยขึ้นมาเลย · วาดซ้ำเฉพาะช่องที่เปลี่ยน จอไม่กะพริบ · เพิ่ม `tools/screen-preview/`<br><sub>22 ก.ย. 2026</sub> |

| `release/17-h113.3.0-s122.3.0` | 113.3.0 | 122.3.0 | ❔ | [zip](https://github.com/kittiphun-rut/MCUPR-CANTEEN/archive/refs/heads/release/17-h113.3.0-s122.3.0.zip) | [`38eb7ee`](https://github.com/kittiphun-rut/MCUPR-CANTEEN/tree/38eb7eefd48ba438e35ab521dffe0f8c704c6bac) | **แก้จอกะพริบทุกวินาที** ต้นเหตุคือการล้างพื้นก่อนเขียนตัวอักษร เปลี่ยนมาเขียนทับที่เดิมด้วย `drawFixedText()` · แก้สีค้างที่มุมโค้งของแถบความคืบหน้า<br><sub>22 ก.ย. 2026</sub> |

| `release/18-h113.4.0-s122.4.0` | 113.4.0 | 122.4.0 | ❔ | [zip](https://github.com/kittiphun-rut/MCUPR-CANTEEN/archive/refs/heads/release/18-h113.4.0-s122.4.0.zip) | [`712f5c4`](https://github.com/kittiphun-rut/MCUPR-CANTEEN/tree/712f5c4da8ebe1fc0d6ab977c637ae73547c529e) | **แก้อักษรซ้อนและภาษาไทยอ่านไม่ออกบนจอ** ต้นตอคือค่าเริ่มต้นของชื่อร้านเป็นภาษาไทยแล้วถูกวาดลงจอตรง ๆ · เพิ่มช่องตั้งชื่อร้านสำหรับจอ และตัวกรอง `asciiOnly()`<br><sub>23 ก.ย. 2026</sub> |

| `release/19-h113.5.0-s122.5.0` | 113.5.0 | 122.5.0 | ❔ | [zip](https://github.com/kittiphun-rut/MCUPR-CANTEEN/archive/refs/heads/release/19-h113.5.0-s122.5.0.zip) | [`24e4b9c`](https://github.com/kittiphun-rut/MCUPR-CANTEEN/tree/24e4b9cdd50e07890d8c8f54417139125dafc6a5) | **จัดตำแหน่งตัวอักษรบนจอ** หน้าพักจอจัดกึ่งกลางทุกบรรทัด · แก้หน่วยเงินที่เหลือช่องว่างกลางอากาศ · กระจายแถวหน้า SYSTEM ของจุดบริการให้เต็มการ์ด<br><sub>23 ก.ย. 2026</sub> |

| `release/20-h113.6.0-s122.5.0` | 113.6.0 | 122.5.0 | ❔ | [zip](https://github.com/kittiphun-rut/MCUPR-CANTEEN/archive/refs/heads/release/20-h113.6.0-s122.5.0.zip) | [`9e19814`](https://github.com/kittiphun-rut/MCUPR-CANTEEN/tree/9e198141987be7143dbb6ff61b74772c98e93683) | **จอสาธารณะบนทีวีในโรงอาหาร** หน้า `/display` เปิดดูได้โดยไม่ต้องเข้าสู่ระบบ · มี `/api/board` เป็นของตัวเองที่ปิดบังรหัสนิสิตเหลือห้าหลักแรก ไม่มีชื่อ ไม่มีหมายเลขบัตร ไม่มีเลขอ้างอิง และไม่มีข้อมูลฮาร์ดแวร์ · เพิ่มตัวตรวจ `privacycheck.py` บังคับข้อกำหนดนี้<br><sub>23 ก.ย. 2026</sub> |

| `release/21-h113.6.0-s122.6.0` | 113.6.0 | 122.6.0 | ❌ | [zip](https://github.com/kittiphun-rut/MCUPR-CANTEEN/archive/refs/heads/release/21-h113.6.0-s122.6.0.zip) | [`9d86481`](https://github.com/kittiphun-rut/MCUPR-CANTEEN/tree/9d8648129de47011b51e201491fceee9b1dbcdd3) | **คืนสัญลักษณ์แตะบัตร RFID บนหน้าแรกของจุดบริการ** ที่หายไปตอนเริ่มใหม่ในรุ่น 122.0.0 · ต่อเข้ากับตัวตรวจสุขภาพ RC522 คลื่นเขียวคือเครื่องอ่านพร้อม แดงคือไม่ตอบพร้อมบรรทัดให้ตามเจ้าหน้าที่<br><sub>23 ก.ย. 2026</sub> |

| `release/22-h113.6.0-s122.6.1` | 113.6.0 | 122.6.1 | ✅ | [zip](https://github.com/kittiphun-rut/MCUPR-CANTEEN/archive/refs/heads/release/22-h113.6.0-s122.6.1.zip) | [`f35e8b0`](https://github.com/kittiphun-rut/MCUPR-CANTEEN/tree/f35e8b0ff8f17d550c5f81b5c99a4fe589ac47bd) | **แก้ `release/21` ที่คอมไพล์ไม่ผ่าน** `drawStandbyReadyState()` ถูกวางไว้ต่ำกว่าจุดที่เรียก · เพิ่มตัวตรวจ `ordercheck.py` จับฟังก์ชันที่ถูกเรียกก่อนถูกประกาศ ซึ่งตัวตรวจเดิมทั้งหกตัวมองไม่เห็น<br><sub>23 ก.ย. 2026</sub> |

| `release/23-h113.6.0-s122.6.2` | 113.6.0 | 122.6.2 | ✅ | [zip](https://github.com/kittiphun-rut/MCUPR-CANTEEN/archive/refs/heads/release/23-h113.6.0-s122.6.2.zip) | [`51bb316`](https://github.com/kittiphun-rut/MCUPR-CANTEEN/tree/51bb31635c3761aab7b672d4b4348804ca87b7c9) | **แก้คลื่นของสัญลักษณ์แตะบัตรที่ไม่ขึ้นบนจอจริง** `drawCircleHelper()` ไม่เปิดทรานแซกชัน SPI เอง · เปลี่ยนมาวาดครึ่งวงกลมเองด้วย `drawPixel()` · เพิ่มตัวตรวจ `gfxcheck.py` และแก้โปรแกรมจำลองที่ปิดบังบั๊กนี้<br><sub>23 ก.ย. 2026</sub> |

| `release/24-h113.7.0-s122.7.0` | 113.7.0 | 122.7.0 | ❔ | [zip](https://github.com/kittiphun-rut/MCUPR-CANTEEN/archive/refs/heads/release/24-h113.7.0-s122.7.0.zip) | [`7fc1ebf`](https://github.com/kittiphun-rut/MCUPR-CANTEEN/tree/7fc1ebf19da60b6e5d1401faa4aa56c8d14b3b85) | **คำสั่งเปลี่ยนโหมดการแสดงผลไปถึงจุดบริการทันที** เดิมต้องรอรอบ heartbeat ราวห้าวินาที · ส่งยูนิแคสต์ก่อนแล้วค่อยกระจายเสียง · แก้แพ็กเก็ตกระจายเสียงที่ใส่ฟิลด์ไม่ครบ · สั่งเปลี่ยนธีมตอนพักหน้าจอไม่เตะออกจากหน้าพักจออีก<br><sub>23 ก.ย. 2026</sub> |

| `release/25-h113.8.0-s122.8.0` | 113.8.0 | 122.8.0 | ❔ | [zip](https://github.com/kittiphun-rut/MCUPR-CANTEEN/archive/refs/heads/release/25-h113.8.0-s122.8.0.zip) | [`b79d6cd`](https://github.com/kittiphun-rut/MCUPR-CANTEEN/tree/b79d6cd90f94ebd72aff44d127f0c4084f2cd295) | **เปลี่ยนคำว่า Point เป็น Station ทั้งจอและหน้าเว็บ** ให้ตรงกับชื่อไฟล์ ตัวแปร และโปรโตคอล · ร้านค้ายังใช้คำว่า Shop เหมือนเดิม · คำไทยไม่เปลี่ยน<br><sub>23 ก.ย. 2026</sub> |

| `release/26-h113.8.0-s122.9.0` | 113.8.0 | 122.9.0 | ❔ | [zip](https://github.com/kittiphun-rut/MCUPR-CANTEEN/archive/refs/heads/release/26-h113.8.0-s122.9.0.zip) | [`232306b`](https://github.com/kittiphun-rut/MCUPR-CANTEEN/tree/232306b04efe35e5b66da13b5ef4eb4fed884b3a) | **ขีดสัญญาณมุมขวาบนของจุดบริการหายหลังเปลี่ยนหน้า** เพราะแถบบนล้างพื้นแล้วไม่วาดคืน · ตัดตัวเลข dBm และคำว่า OFFLINE ออก เหลือแต่สัญลักษณ์ ตอนขาดการเชื่อมต่อโครงขีดเป็นสีแดง<br><sub>23 ก.ย. 2026</sub> |

| `release/27-h113.9.0-s122.10.0` | 113.9.0 | 122.10.0 | ❔ | [zip](https://github.com/kittiphun-rut/MCUPR-CANTEEN/archive/refs/heads/release/27-h113.9.0-s122.10.0.zip) | [`361c907`](https://github.com/kittiphun-rut/MCUPR-CANTEEN/tree/361c907947d3b674b3db6811cef5b672ec450b73) | **ต้นเหตุจริงของการหน่วงห้าวินาที** วิทยุของจุดบริการหลับ เพราะ Arduino core สั่งทับ `esp_wifi_set_ps()` กลับเป็นโหมดประหยัดพลังงานตอนอีเวนต์ STA_START · แก้ด้วย `WiFi.setSleep(false)` · แม่ข่ายย้ำคำสั่งหกรอบกระจายสองวินาทีโดยไม่หน่วงลูป<br><sub>23 ก.ย. 2026</sub> |

| `release/28-h113.10.0-s122.11.0` | 113.10.0 | 122.11.0 | ❔ | [zip](https://github.com/kittiphun-rut/MCUPR-CANTEEN/archive/refs/heads/release/28-h113.10.0-s122.11.0.zip) | [`6ff9621`](https://github.com/kittiphun-rut/MCUPR-CANTEEN/tree/6ff96219e0cc25851c31c06a655aa1e8e906b65a) | **จัดขาใหม่ทั้งสองบอร์ดให้สายไม่ไขว้กัน** อุปกรณ์ทุกตัวอยู่บนแถวซ้ายแถวเดียว · จอเสียบตรงลงมาได้ทั้งแถว · ย้ายวัดแบตเตอรี่ออกจากขา strapping GPIO3 · เพิ่ม `pincheck.py` และ `docs/HARDWARE.md` · **ต้องรื้อสายจริง**<br><sub>24 ก.ย. 2026</sub> |

| `release/29-h113.10.0-s122.12.0` | 113.10.0 | 122.12.0 | ❔ | [zip](https://github.com/kittiphun-rut/MCUPR-CANTEEN/archive/refs/heads/release/29-h113.10.0-s122.12.0.zip) | [`b0a1038`](https://github.com/kittiphun-rut/MCUPR-CANTEEN/tree/b0a103853a161a30234107607d4a896d70ece210) | **หน้าแรกบอกสถานะก่อนนิสิตแตะบัตร** SERVER OFFLINE คลื่นเหลือง และไม่รับการแตะบัตร · แยกหน้าเตือน "ไม่ทราบผล" ออกจาก "ไม่สำเร็จ" เพราะคำตอบอาจหายหลังแม่ข่ายบันทึกแล้ว<br><sub>24 ก.ย. 2026</sub> |

| `release/30-h113.11.0-s122.12.0` | 113.11.0 | 122.12.0 | ❔ | [zip](https://github.com/kittiphun-rut/MCUPR-CANTEEN/archive/refs/heads/release/30-h113.11.0-s122.12.0.zip) | [`1476746`](https://github.com/kittiphun-rut/MCUPR-CANTEEN/tree/14767466e75d0571bb4a2c72fb70c03fb55ed4fc) | **บันทึกสำเนาลงการ์ด SD หลังโมดูลจอ** รายการประจำวัน ไฟล์ปิดยอด และทะเบียนนิสิต · LittleFS ยังเป็นที่เก็บหลัก ไม่มีการ์ดก็ทำงานได้ครบ · **ต้องเดินสายเพิ่มสี่เส้น**<br><sub>24 ก.ย. 2026</sub> |

| `release/31-h113.12.0-s122.12.0` | 113.12.0 | 122.12.0 | ❔ | [zip](https://github.com/kittiphun-rut/MCUPR-CANTEEN/archive/refs/heads/release/31-h113.12.0-s122.12.0.zip) | [`515f9e4`](https://github.com/kittiphun-rut/MCUPR-CANTEEN/tree/515f9e4355204bc8e575e4cbaa2de2c3423772fe) | **การ์ด SD ย้ายไปบัส HSPI ของตัวเอง** ไม่ใช้ร่วมกับจอ · สี่ขาเรียงติดกันที่ตำแหน่ง 6 ถึง 9 เดินสายหนึ่งต่อหนึ่งไม่ต้องแยกสาย · **ใช้แทน `release/30`**<br><sub>24 ก.ย. 2026</sub> |

> ❔ **`release/12` ถึง `release/31` ยังไม่ผ่านการคอมไพล์จริง**
> (`release/18` ท่านแฟลชแล้วและยืนยันว่าอักษรซ้อนหาย การกะพริบดีขึ้น แต่ยังไม่ได้แจ้งผลการคอมไพล์) เพราะเครื่องที่ใช้พัฒนาเข้า
> `downloads.arduino.cc` ไม่ได้ ตรวจมาแล้วเท่าที่ตรวจได้: วงเล็บครบทุกไฟล์
> การประกาศฟังก์ชันล่วงหน้าครบ ไวยากรณ์ JavaScript ที่ฝังอยู่ผ่าน `node --check`
> และทุกหน้าจอถูกเรนเดอร์ดูแล้วว่าตัวอักษรไม่ล้นกรอบ
> **รบกวนท่านคอมไพล์แล้วแจ้งผลกลับมา** ถ้าผ่านจะได้แก้ช่องนี้เป็น ✅

> ⚠️ **`release/22` คอมไพล์ผ่านแล้ว แต่คลื่นของสัญลักษณ์แตะบัตรไม่ขึ้นบนจอ**
> `drawCircleHelper()` ของไลบรารีไม่เปิดทรานแซกชัน SPI เอง จอจึงไม่ได้รับข้อมูล
> ใช้ **`release/23`** แทน ซึ่งมีฟีเจอร์เท่ากันทุกอย่าง

> ℹ️ **`release/30` ใช้บัส SPI ร่วมกับจอ** ซึ่งใช้งานได้แต่ต้องต่อสายสองเส้น
> เข้าหัวต่อเดียวกัน ใช้ **`release/31`** แทน ซึ่งแยกบัสของการ์ดออกมา
> เดินสายหนึ่งต่อหนึ่ง ฟีเจอร์เท่ากันทุกอย่าง

> ⚠️ **`release/21` คอมไพล์ไม่ผ่าน** `drawStandbyReadyState()` ถูกวางไว้ต่ำกว่า
> จุดที่เรียกใน `StationScreen.h` ขึ้นข้อความว่า `was not declared in this scope`
> ใช้ **`release/22`** แทน ซึ่งมีฟีเจอร์เท่ากันทุกอย่าง

> ⚠️ **`release/03` ถึง `release/07` คอมไพล์ไม่ผ่าน** ด้วย Arduino IDE
> ติดปัญหา forward declaration ที่หายไป (`fillStationConfig` และ `rosterApplyPacket`)
> ขึ้นข้อความว่า `variable or field 'fillStationConfig' declared void`
> ถ้าต้องการรุ่นล่าสุดที่ใช้งานได้จริง ให้ใช้ **`release/08`**
> ถ้าจำเป็นต้องย้อนไปรุ่นใดรุ่นหนึ่งในช่วงนั้นจริง ๆ แก้ได้เองด้วยการเพิ่มบรรทัดเดียว
> ในบล็อก *Forward Declarations* ของไฟล์นั้น รายละเอียดอยู่ใน
> [`tools/proto-check/`](tools/proto-check/)

รายละเอียดของแต่ละรุ่นอยู่ใน [`CHANGELOG.md`](CHANGELOG.md)

## หมายเหตุเรื่องเลขเวอร์ชันฝั่งแม่ข่ายที่ค้าง

ระหว่าง `release/02` ถึง `release/05` ฝั่งแม่ข่ายมีการแก้ไขจริงหลายรอบ
(จอสาธารณะ, ซิงค์โหมดการแสดงผล, แก้ captive portal) แต่ `APP_VERSION`
ในโค้ดถูกลืมเลื่อน ค้างอยู่ที่ `108.0.0` ตลอด ขณะที่ CHANGELOG ระบุเป็น
108.1.0 / 108.2.0 / 108.3.0 ไปแล้ว เรื่องนี้ถูกแก้ตอน `release/06`
ด้วยการกระโดดไป `109.0.0` ทีเดียว
**ชื่อรุ่นในตารางข้างบนใช้เลขที่อยู่ในโค้ดจริง** ไม่ใช่เลขใน CHANGELOG
ตรวจแล้วทีละรุ่นด้วยการอ่าน `APP_VERSION` ออกมาจากโค้ดของคอมมิตนั้นจริง ๆ

## วิธีย้อนกลับไปใช้เวอร์ชันเก่า

### ไม่ใช้ git เลย

กด **zip** ในตารางข้างบน ได้ไฟล์ที่มีทั้งสองสเก็ตช์ครบชุดพร้อมอัปโหลดทันที

### ดูว่ารุ่นนั้นมีอะไรบ้าง

```sh
git fetch origin
git show origin/release/05-h108.0.0-s119.0.0 --stat
```

### ดึงโค้ดของรุ่นนั้นมาดูโดยไม่ยุ่งกับงานปัจจุบัน

```sh
git switch --detach origin/release/05-h108.0.0-s119.0.0
```

กลับมางานล่าสุดด้วย `git switch main`

### ดึงเฉพาะไฟล์เดียวจากรุ่นเก่ามาทับของปัจจุบัน

```sh
git checkout origin/release/05-h108.0.0-s119.0.0 -- Canteen_Station_Client/
```

### ล้าง branch ชุดเก่า

รอบก่อนใช้ชื่อแบน ๆ `release-00-...` ตอนนี้ย้ายมาอยู่ใต้โฟลเดอร์ `release/` แล้ว
และ branch หลักเดิมชื่อ `fervent-wozniak-66knt2` (ชื่อสุ่มจากเซสชัน) ถูกแทนด้วย `main`
ของเก่าทั้งหมดชี้คอมมิตเดียวกับของใหม่ จึงลบทิ้งได้โดยไม่เสียอะไรเลย

บัญชีที่เซสชันนี้ใช้ **ลบ branch ไม่ได้** (เซิร์ฟเวอร์ตอบ 403 เช่นเดียวกับ tag)
ทำสองขั้นนี้เองครับ

**ขั้นที่ 1** เปลี่ยน branch หลักเป็น `main` ที่หน้า
<https://github.com/kittiphun-rut/MCUPR-CANTEEN/settings/branches>
กดปุ่มสลับตรง *Default branch* แล้วเลือก `main`

**ขั้นที่ 2** รันคำสั่งนี้เพื่อลบของเก่าทิ้ง

```sh
git push origin --delete \
  release-00-h107.0.1-s117.0.7 \
  release-01-h107.0.1-s118.0.0 \
  release-02-h108.0.0-s118.0.0 \
  release-03-h108.0.0-s118.1.0 \
  release-04-h108.0.0-s118.2.0 \
  release-05-h108.0.0-s119.0.0 \
  release-06-h109.0.0-s119.0.0 \
  release-07-h110.0.1-s120.0.0 \
  fervent-wozniak-66knt2
```

> ต้องทำขั้นที่ 1 ก่อนเสมอ เพราะ GitHub ไม่ยอมให้ลบ branch ที่เป็น default อยู่
> และอย่าลบ `main` กับ `claude/fervent-wozniak-66knt2`

### สร้างแท็กเอง

คัดลอกทั้งก้อนนี้ไปวางในเครื่องที่มีสิทธิ์ push เต็ม แล้วรันครั้งเดียวจบ

```sh
git tag -a v00-h107.0.1-s117.0.7 b351769 -m "Host 107.0.1 / Station 117.0.7"
git tag -a v01-h107.0.1-s118.0.0 8a20d11 -m "Host 107.0.1 / Station 118.0.0"
git tag -a v02-h108.0.0-s118.0.0 eec7139 -m "Host 108.0.0 / Station 118.0.0"
git tag -a v03-h108.0.0-s118.1.0 a883805 -m "Host 108.0.0 / Station 118.1.0"
git tag -a v04-h108.0.0-s118.2.0 1ca1c8a -m "Host 108.0.0 / Station 118.2.0"
git tag -a v05-h108.0.0-s119.0.0 6620ab5 -m "Host 108.0.0 / Station 119.0.0"
git tag -a v06-h109.0.0-s119.0.0 c3584ff -m "Host 109.0.0 / Station 119.0.0"
git tag -a v07-h110.0.1-s120.0.0 origin/release-07-h110.0.1-s120.0.0 -m "Host 110.0.1 / Station 120.0.0"
git tag -a v08-h110.0.2-s120.0.1 origin/release/08-h110.0.2-s120.0.1 -m "Host 110.0.2 / Station 120.0.1"
git tag -a v09-h111.0.0-s120.0.1 origin/release/09-h111.0.0-s120.0.1 -m "Host 111.0.0 / Station 120.0.1"
git tag -a v10-h111.1.0-s120.0.1 origin/release/10-h111.1.0-s120.0.1 -m "Host 111.1.0 / Station 120.0.1"
git push origin --tags
```

หลังจากนั้นหน้า <https://github.com/kittiphun-rut/MCUPR-CANTEEN/tags> จะมีทุกรุ่นให้กดดาวน์โหลด zip ได้เลย

## เวลาจะแจ้งให้ปรับปรุง

บอกชื่อรุ่นมาได้เลย เช่น *"ย้อนไป `release/05` แล้วแก้เรื่อง ..."*
จะได้ตรงกันว่าหมายถึงโค้ดชุดไหน และไม่ต้องเดาว่าเป็นเวอร์ชันก่อนหรือหลัง
การเปลี่ยนโปรโตคอล

## ความเข้ากันได้ของโปรโตคอล ESP-NOW

ขนาดโครงสร้างด้านล่างอ่านจาก `static_assert` ในโค้ดของแต่ละแท็กจริง ไม่ได้อ้างจากความจำ

| ช่วงรุ่น | โครงสร้างแพ็กเก็ต | ผสมรุ่นข้ามฝั่งได้ไหม |
|---|---|---|
| `release/00` ถึง `release/02` | Station 50 / Host 200 / Config **5** ไบต์ | ได้ ขนาดเท่าต้นฉบับทั้งหมด (ต้นฉบับมี `HostConfigPacket` อยู่แล้ว แต่ฝั่งสถานีประกาศไว้เฉย ๆ ไม่เคยรับคำสั่งจริง) |
| `release/03` ถึง `release/06` | Config ขยาย **5 → 8** ไบต์ | **ไม่ได้** ต้องแฟลชทั้งสองฝั่ง ไม่งั้นคำสั่งโหมดการแสดงผลจะถูกทิ้งทั้งหมด |
| `release/07` | เพิ่ม `HostRosterPacket` **206** ไบต์ | ได้ แม่ข่ายรุ่นใหม่ตรวจจาก heartbeat ว่าสถานีรองรับบัญชีหรือไม่ ถ้าเป็นรุ่นเก่าจะไม่ส่งบัญชีไปให้เลย และแดชบอร์ดขึ้นว่า *เฟิร์มแวร์เก่า ไม่รองรับ* (จุดบริการนั้นยังทำงานครบทุกอย่าง แค่ไม่มีการตรวจสิทธิ์ตอนลิงก์ขาด) |

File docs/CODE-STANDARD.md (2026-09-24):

# มาตรฐานคอมเมนต์ของโครงการ

เอกสารนี้กำหนดรูปแบบคอมเมนต์ที่ทุกไฟล์ซอร์สในโครงการต้องมี
เพื่อให้เปิดไฟล์ขึ้นมาแล้ว **รู้ทันทีว่าไฟล์นี้คืออะไร เวอร์ชันอะไร และมีอะไรเพิ่มเข้ามาบ้าง**
โดยไม่ต้องไปไล่อ่าน git log หรือ CHANGELOG

รูปแบบที่ใช้คือ **Doxygen** ซึ่งเป็นมาตรฐานที่ใช้กันทั่วไปในงานเฟิร์มแวร์
แท็กทุกตัวที่ใช้ในเอกสารนี้เป็นแท็กจริงของ Doxygen ไม่ได้คิดขึ้นเอง
ถ้าวันหนึ่งอยากสร้างเอกสารอัตโนมัติจากโค้ด ก็รัน Doxygen ได้เลยโดยไม่ต้องแก้อะไร

---

## 1. หัวไฟล์ (บังคับทุกไฟล์)

ทุกไฟล์ `.ino` และ `.h` ต้องขึ้นต้นด้วยบล็อกนี้

```c
/**
 * @file      ชื่อไฟล์.h
 * @brief     ไฟล์นี้ทำอะไร หนึ่งบรรทัด
 * @version   113.1.0
 * @date      2026-09-22
 * @author    Kittiphan Rattanakorn <kittiphun.rut@mcu.ac.th>
 *
 * @par Organization
 * มหาวิทยาลัยมหาจุฬาลงกรณราชวิทยาลัย วิทยาเขตแพร่
 *
 * @par Description
 * คำอธิบายยาวได้ตามต้องการ ว่าไฟล์นี้รับผิดชอบส่วนไหนของระบบ
 *
 * @par Revision History
 * | Version | Date | Change |
 * |---|---|---|
 * | 113.1.0 | 2026-09-22 | สิ่งที่เปลี่ยนในเวอร์ชันนี้ |
 * | 113.0.0 | 2026-09-22 | สิ่งที่เปลี่ยนในเวอร์ชันก่อน |
 *
 * @warning  เรื่องที่ถ้าไม่รู้แล้วจะพัง
 * @note     เรื่องที่ควรรู้แต่ไม่ถึงกับพัง
 */
```

### กติกาของแต่ละแท็ก

| แท็ก | บังคับ | กติกา |
|---|---|---|
| `@file` | ✅ | ต้องตรงกับชื่อไฟล์จริง |
| `@brief` | ✅ | หนึ่งบรรทัด ไม่เกินหนึ่งประโยค |
| `@version` | ✅ | ไฟล์ `.ino` ต้องตรงกับ `APP_VERSION` **เป๊ะ** · ไฟล์ `.h` คือ **เวอร์ชันที่ไฟล์นี้ถูกแก้ครั้งล่าสุด** ต้องเป็นแถวบนสุดของตารางของตัวเอง และต้องไม่ใหม่กว่า `APP_VERSION` |
| `@date` | ✅ | รูปแบบ `YYYY-MM-DD` เท่านั้น คือวันที่แก้ไขล่าสุด |
| `@author` | ✅ | ชื่อผู้พัฒนาหลัก |
| `@par Revision History` | ✅ | ตารางเรียงจาก**ใหม่ไปเก่า** แถวบนสุดต้องตรงกับ `@version` ของไฟล์ · ใส่เฉพาะเวอร์ชันที่ไฟล์นี้**ถูกแก้จริง** ไม่ต้องใส่เวอร์ชันที่ไม่ได้แตะไฟล์นี้ |
| `@warning` / `@note` | ตามสมควร | ใส่เมื่อมีเรื่องที่คนมารับช่วงต่อต้องรู้ |

> ทั้งหมดนี้ถูกตรวจอัตโนมัติด้วย `python3 tools/proto-check/headercheck.py`
> ถ้าลืมอัปเดตเลขเวอร์ชันหรือลืมเติมแถวใหม่ในตาราง ตัวตรวจจะฟ้อง
>
> **ตัวอย่างจริง** `HostScreen.h` ค้างอยู่ที่ `113.0.0` ขณะที่สเก็ตช์เป็น `113.1.0`
> เพราะรุ่น 113.1.0 แก้แค่หน้าเว็บ ไม่ได้แตะไฟล์วาดจอเลย **นี่คือสิ่งที่ถูกต้อง**
> การไล่ขยับเลขทุกไฟล์ให้เท่ากันหมดจะทำให้ตารางโกหกว่าไฟล์นั้นถูกแก้ทั้งที่ไม่ได้แก้

---

## 2. ป้ายบอกเวอร์ชันในโค้ด

หัวไฟล์บอกภาพรวม แต่ไม่ได้บอกว่า **บรรทัดไหน** เพิ่มมาตอนไหน
เวลาเพิ่มหรือแก้อะไรที่ไม่ใช่เรื่องเล็ก ให้ปักป้ายไว้เหนือจุดนั้น

```c
// [113.0.0] เพิ่ม: ข้อมูลสดสำหรับแดชบอร์ด หน้าเว็บดึงชุดนี้ทุกสองวินาที
void handleDashboardAPI() {
```

รูปแบบคือ `// [เลขเวอร์ชัน] คำกริยา: คำอธิบาย` โดยคำกริยาใช้สามคำนี้เท่านั้น

| คำกริยา | ใช้เมื่อ |
|---|---|
| **เพิ่ม** | ของใหม่ที่ไม่เคยมีมาก่อน |
| **แก้** | ของเดิมที่ทำงานผิดแล้วซ่อม |
| **ย้าย** | ของเดิมที่ย้ายที่อยู่ ตรรกะไม่เปลี่ยน |

เลขเวอร์ชันในป้ายต้องมีอยู่จริงในตาราง Revision History ของไฟล์นั้น
ตัวตรวจจะฟ้องถ้าปักป้ายด้วยเลขที่ไม่มีในตาราง

**ไม่ต้องปักป้ายกับ** การแก้คำผิด จัดย่อหน้า เปลี่ยนชื่อตัวแปร
หรือการแก้เล็ก ๆ ที่อ่านโค้ดแล้วเข้าใจได้เอง ป้ายที่เยอะเกินไปจะกลายเป็นขยะ

---

## 3. คอมเมนต์ในเนื้อโค้ด

- **เขียนเป็นภาษาไทย** เพราะคนที่มารับช่วงดูแลต่อคือนิสิตของวิทยาเขต
  ส่วนข้อความที่ผู้ใช้เห็นบนจอและบนหน้าเว็บเป็นภาษาอังกฤษ คนละเรื่องกัน

### ห้ามมีภาษาไทยในโค้ดที่วาดลงจอ TFT

ฟอนต์ในตัวของ Adafruit GFX **มีแต่ ASCII** ไบต์ตั้งแต่ `0x80` ขึ้นไปจะถูกวาดเป็น
สัญลักษณ์มั่ว ภาษาไทยหนึ่งตัวกินสามไบต์ จึงกลายเป็นตัวประหลาดสามตัว
และ **กินที่กว้างกว่าที่โค้ดนับไว้สามเท่า** ข้อความจึงล้นไปทับของข้างเคียง
เห็นเป็นอักษรซ้อนกัน

- สตริงในไฟล์ที่วาดจอ (`HostScreen.h`, `StationScreen.h`) ต้องเป็น ASCII ล้วน
- ข้อความที่มาจากผู้ใช้หรือจากฐานข้อมูล ต้องผ่าน `asciiOnly()` ก่อนถึงจอเสมอ
- ชื่อร้านมีช่องแยกสำหรับขึ้นจอโดยเฉพาะ ตั้งได้จากแท็บ Shops บนหน้าเว็บ

`asciicheck.py` ตรวจทั้งสองข้อให้อัตโนมัติ
- **อธิบายว่าทำไม ไม่ใช่ทำอะไร** โค้ดบอกอยู่แล้วว่าทำอะไร
  สิ่งที่โค้ดบอกไม่ได้คือเหตุผล เช่น *"แยกบัสจอออกจากเครื่องอ่านบัตร
  เพราะไลบรารี MFRC522 ยึดตัวแปร SPI มาตรฐานไว้ ถ้าใช้ร่วมกันจอจะเพี้ยนหลัง PCD_Init()"*
- **ห้ามเขียนคอมเมนต์รับประกันสิ่งที่ยังไม่ได้ทดสอบ** เคยเกิดขึ้นมาแล้วว่า
  มีคอมเมนต์เขียนไว้ว่า *"การใส่เพิ่มเฉย ๆ ปลอดภัย"* ทั้งที่ไม่เคยลองจริง
  แล้วทำให้ชื่อ Wi-Fi ไม่ขึ้นมาให้เลือก ถ้ายังไม่ได้ทดสอบให้เขียนตรง ๆ ว่ายังไม่ได้ทดสอบ

---

## 4. ตรวจก่อน commit ทุกครั้ง

```sh
python3 tools/proto-check/runall.py        # รันทุกตัวข้างล่างนี้รวดเดียว

python3 tools/proto-check/headercheck.py   # หัวไฟล์และป้ายเวอร์ชัน
python3 tools/proto-check/asciicheck.py    # ข้อความที่ฟอนต์ของจอวาดไม่ได้
python3 tools/proto-check/bracecheck.py    # วงเล็บและเครื่องหมายคำพูด
python3 tools/proto-check/splitcheck.py    # ปัญหาจากการแยกโค้ดไปไว้ในไฟล์ .h
python3 tools/proto-check/ordercheck.py    # ฟังก์ชันที่ถูกเรียกก่อนถูกประกาศ
python3 tools/proto-check/gfxcheck.py      # ฟังก์ชัน GFX ที่ต้องมี startWrite() ก่อน
python3 tools/proto-check/packetcheck.py   # แพ็กเก็ตคำสั่งที่ใส่ฟิลด์ไม่ครบ
python3 tools/proto-check/pincheck.py      # ขาชนกันเองหรือไปโดนขาต้องห้าม
python3 tools/proto-check/kicadcheck.py    # ไฟล์วงจร KiCad ตรงกับผังขาในซอร์ส
python3 tools/proto-check/protoscan.py Canteen_Host_Server/Canteen_Host_Server.ino \
                                       Canteen_Station_Client/Canteen_Station_Client.ino
```

ทุกตัวไม่ได้แทนการคอมไพล์ เป็นแค่ตัวกันความผิดพลาดที่เคยเกิดขึ้นจริงมาแล้ว
**การคอมไพล์และทดสอบบนเครื่องจริงยังจำเป็นเสมอ**

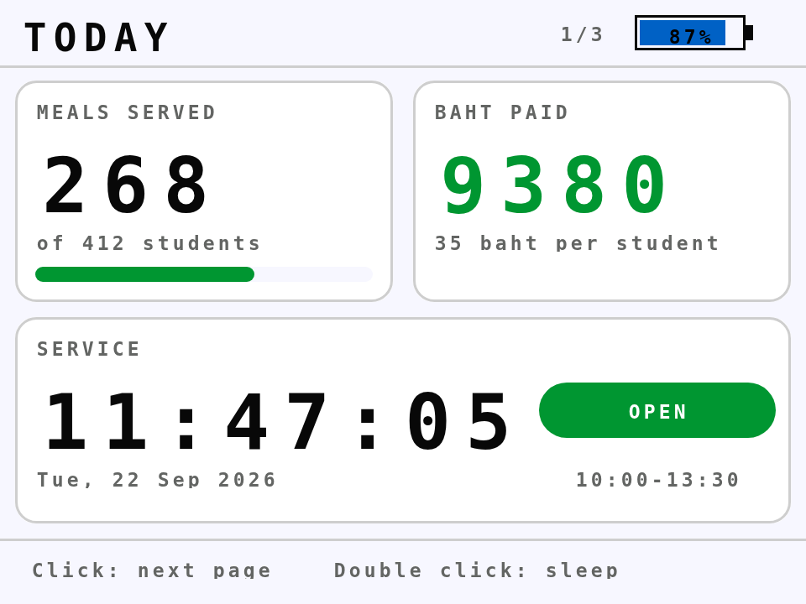
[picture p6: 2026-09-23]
docs/interface/tft-host-12-overview-light.png

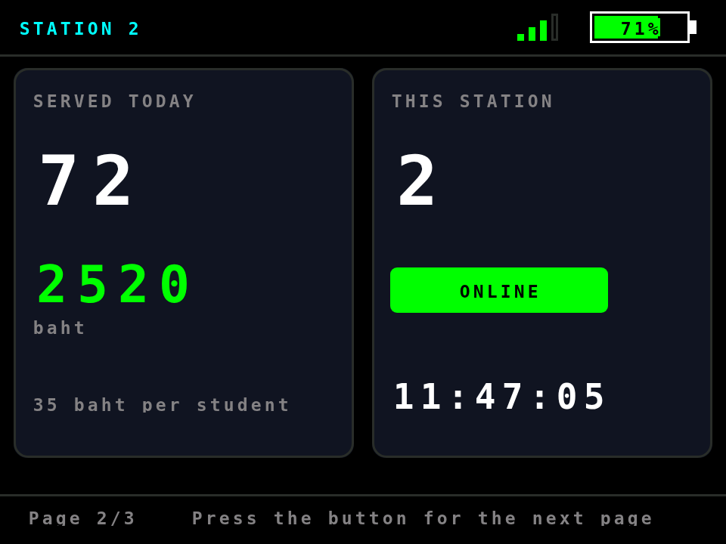
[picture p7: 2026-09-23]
docs/interface/tft-stn-02-stats.png

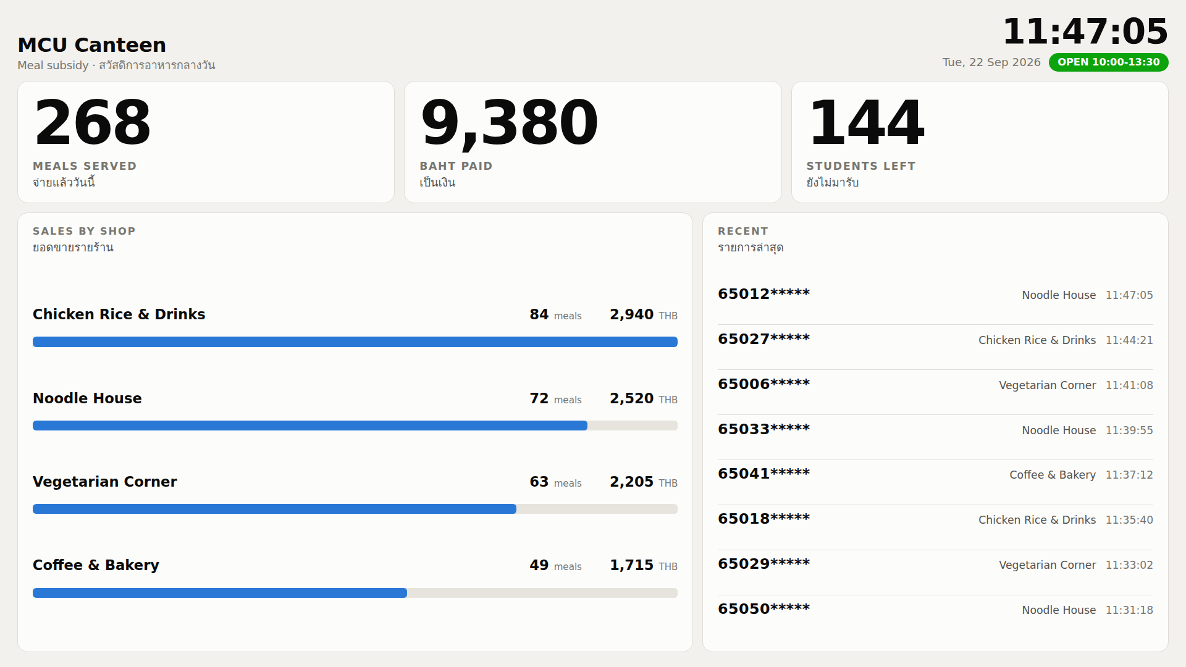
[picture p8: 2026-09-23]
docs/interface/web-14-display-light.png

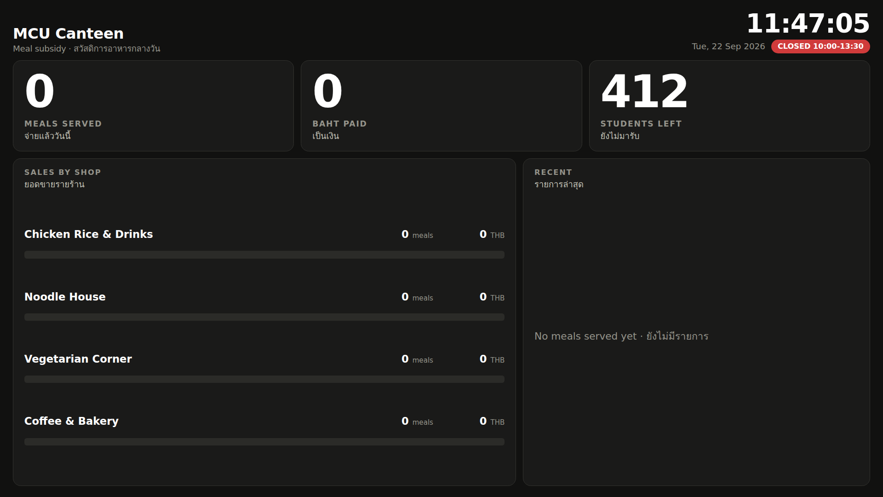
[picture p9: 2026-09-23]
docs/interface/web-15-display-empty.png

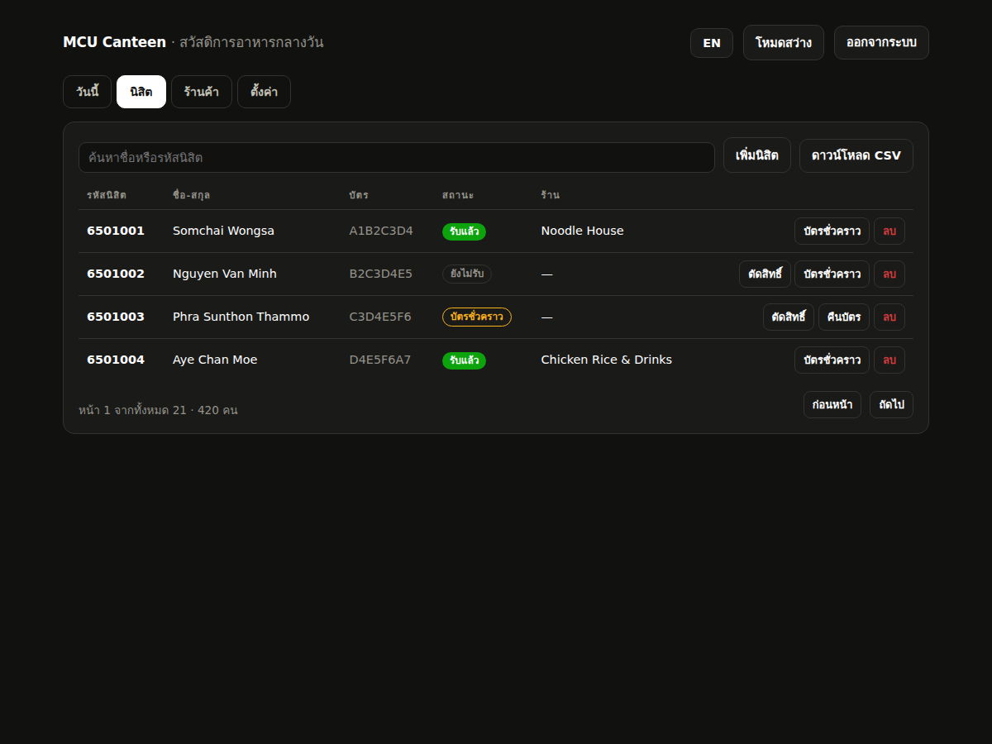
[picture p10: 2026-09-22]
docs/interface/web-09-students-th.png

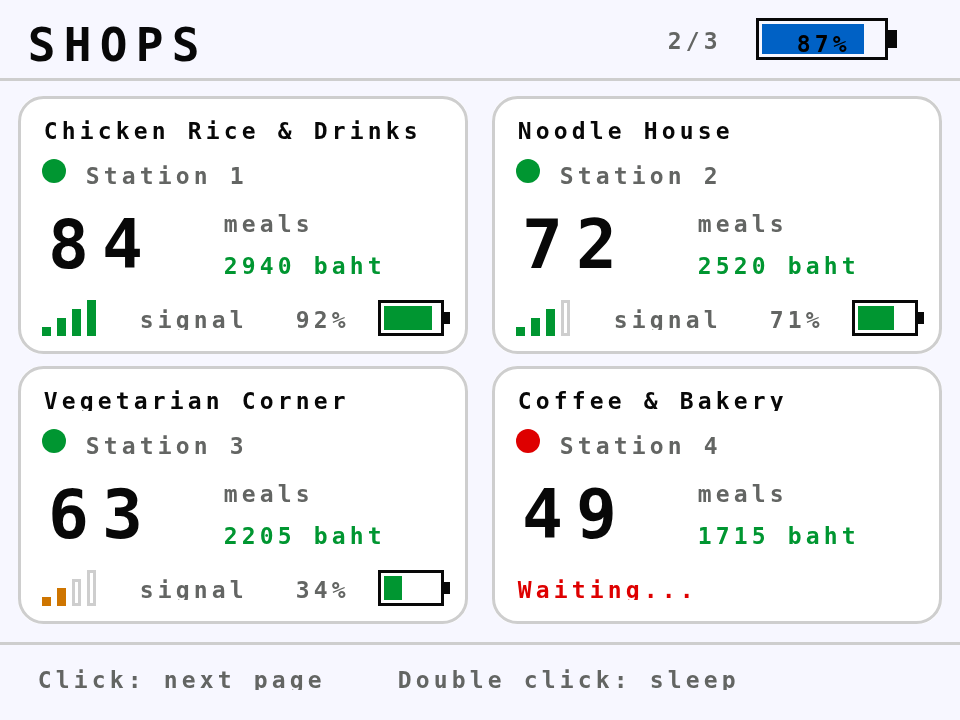
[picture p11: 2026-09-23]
docs/interface/tft-host-13-stations-light.png

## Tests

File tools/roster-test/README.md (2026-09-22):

# ชุดทดสอบโปรโตคอลบัญชีสิทธิ์ (roster)

สคริปต์นี้ **ดึงฟังก์ชันจริงออกมาจากไฟล์ `.ino` ทั้งสองฝั่ง** แล้วคอมไพล์ด้วย `g++`
บนเครื่องพัฒนา เพื่อรันจำลองการคุยกันระหว่างแม่ข่ายกับสถานีทั้งวงจร
ไม่ได้คัดลอกโค้ดมาวางซ้ำ ถ้าแก้ตรรกะในสเก็ตช์แล้วพัง ชุดทดสอบนี้จะจับได้ทันที

## วิธีรัน

```sh
cd tools/roster-test
python3 extract.py      # ดึงโค้ดจาก .ino มาไว้ใน gen.inc
g++ -std=c++17 -Wall -Wextra -Wno-unused-parameter -Wno-unused-function -o rtest main.cpp
./rtest
```

ต้องมี `python3` กับ `g++` เท่านั้น ไม่ต้องใช้ toolchain ของ ESP32

## ครอบคลุมอะไรบ้าง

1. ผลักบัญชีชุดเต็มครั้งแรก (ตัดนิสิตที่ยังไม่ผูกบัตรออก)
2. ตัดสิทธิ์แล้วส่งอัปเดตทีละรายการ ไม่ผลักทั้งชุดใหม่
3. อัปเดตหายกลางทาง แล้วกู้คืนเองผ่าน heartbeat
4. สถานีทำเครื่องหมายเองตอนรับบัตรเข้าคิวออฟไลน์
5. ปิดยอดประจำวัน คืนสิทธิ์ทุกคน
6. บัญชีใหญ่เกินที่สถานีเก็บไหว (ต้องไม่ผลักชุดเต็มวนไม่จบ)
7. บัญชีค้างข้ามวัน — สถานะใช้สิทธิ์ของเมื่อวานต้องใช้ไม่ได้ แต่ยังปัดตกบัตรนอกทะเบียนได้
8. ค่าแฮชชนกันในชุดนิสิตจริง และผลแฮชสองฝั่งต้องเท่ากัน
9. เลขรุ่นวนรอบที่ 65535
10. heartbeat จากเฟิร์มแวร์สถานีรุ่นเก่าที่ไม่ได้ฝากเลขรุ่นมา

สคริปต์ยังตรวจด้วยว่านิยาม `RosterEntry` และ `HostRosterPacket` ในไฟล์ทั้งสองฝั่ง
ตรงกันทุกไบต์ ถ้าแก้ข้างเดียวจะฟ้องทันทีก่อนคอมไพล์

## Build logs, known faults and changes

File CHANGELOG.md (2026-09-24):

# CHANGELOG

## ย้ายการ์ด SD ไปอยู่บัส SPI ของตัวเอง (Host 113.12.0 / Station 122.12.0)

ท่านถามว่าการแชร์บัสกับจอจะมีปัญหาไหม และแยกบัสได้หรือเปล่า

### คำตอบคือแชร์ได้จริง แต่แยกดีกว่าในงานนี้

การแชร์บัสเป็นวิธีมาตรฐาน และฝั่งซอฟต์แวร์ปลอดภัยแน่นอน — ผมไปอ่านซอร์สของ
ไลบรารี SD ใน arduino-esp32 แล้ว มันเรียก `beginTransaction()` / `endTransaction()`
ทุกครั้งเหมือนที่ Adafruit ทำ ทั้งสองตัวจึงผลัดกันใช้บัสอย่างถูกต้อง
และความเสี่ยงคลาสสิกเรื่องการ์ดไม่ยอมปล่อยขา MISO ก็ใช้ไม่ได้กับผังนี้
เพราะจอไม่มีสาย MISO ต่ออยู่เลย

แต่พอดูตัวเลขจริงแล้วพบสองอย่างที่เปลี่ยนคำตอบ

1. **จอวิ่งที่ 32 MHz** ค่า `SPI_DEFAULT_FREQ` ในไลบรารี ST77xx คือ 32,000,000
   การแตกแขนงสายเพิ่มไปหาการ์ดที่ความถี่นั้นทำให้สัญญาณแย่ลง
2. **แม่ข่ายใช้ SPI อยู่ตัวเดียวคือ FSPI ส่วน HSPI ว่างสนิท** ไม่ได้ใช้ทำอะไรเลย

### เหตุผลที่สำคัญที่สุดคือเรื่องการเดินสาย

การแชร์บัสแปลว่าต้อง **เอาสายสองเส้นยัดเข้าหัวต่อเดียวกัน** ที่ `GPIO13` กับ `GPIO14`
ซึ่งเป็นจุดที่หลุดง่ายที่สุดในงานที่ไขสายด้วยมือ

แบบแยกกลับ **เดินง่ายกว่า** คือสี่สายไปสี่ขาที่เรียงติดกันพอดี หนึ่งต่อหนึ่ง
และลำดับตรงกับลำดับขาบนตัวโมดูล เสียบตรงลงมาได้โดยไม่ต้องแยกสายเลย

| ขาบนหัวต่อการ์ด | ต่อไปที่ | ตำแหน่ง |
|---|---|:---:|
| `SD_SCK` | `GPIO6` | 6 |
| `SD_MISO` | `GPIO7` | 7 |
| `SD_MOSI` | `GPIO15` | 8 |
| `SD_CS` | `GPIO16` | 9 |

ได้ของแถมอีกสองอย่างคือ **สายหลุดเส้นเดียวไม่ดับทั้งคู่** และ **บัสของจอสะอาดเหมือนเดิม**
จ่ายแค่ขาสองขาที่ยังไงก็ไม่ได้ใช้อยู่แล้ว

เหตุผลที่ตำราส่วนใหญ่ให้แชร์บัสคือบอร์ดอย่าง Arduino Uno **มีขาไม่พอ**
ข้อจำกัดนั้นไม่มีอยู่ในบอร์ดนี้

### สิ่งที่แก้

* เพิ่ม `SPIClass SPI_SD(HSPI)` เป็นบัสของการ์ดโดยเฉพาะ
* **คืนบัสของจอกลับเป็นไม่มี MISO** เหมือนเดิม เพราะจอไม่เคยต้องอ่านข้อมูลกลับ
  รุ่นที่แล้วต้องใส่ MISO เข้าไปเพราะการ์ดใช้บัสร่วมกัน ตอนนี้ไม่ต้องแล้ว
* ตรวจแล้วว่า `SPIClass::begin()` คืนค่าทันทีถ้าบัสเปิดอยู่ การเรียกซ้ำตอนลองเมานต์ใหม่
  ทุกสามสิบวินาทีจึงปลอดภัย ไม่ได้เปิดบัสซ้ำซ้อน

### ไฟล์วงจรและกติกาตรวจสอบ

ไฟล์วงจร KiCad สร้างใหม่แล้ว การ์ดมีเน็ตของตัวเองครบสี่เส้น

และ **คืนกติกาของ `kicadcheck.py` ให้เข้มเหมือนเดิม** รุ่นที่แล้วต้องผ่อนให้
`TFT_SCL` กับ `TFT_SDA` มีสามปลายได้เพราะใช้บัสร่วมกัน ตอนนี้ไม่มีบัสที่ใช้ร่วมกันแล้ว
จึงตั้งรายการนั้นเป็นค่าว่าง กลับไปบังคับว่า **เน็ตสัญญาณทุกเส้นต้องมีสองปลายพอดี**
เก็บกลไกไว้เผื่ออนาคต แต่ตอนนี้ไม่มีข้อยกเว้นให้อะไรเลย

---

## บันทึกสำเนาลงการ์ด SD ที่อยู่หลังโมดูลจอ (Host 113.11.0 / Station 122.12.0)

ท่านส่งรูปโมดูลจอมาให้ดูว่ามีช่องเสียบการ์ด microSD อยู่ด้านหลัง และถามว่าเขียนโค้ดให้บันทึกได้เลยไหม

**ทำได้ครับ และมีสองอย่างที่ตรวจแล้วพบว่าเอื้อพอดี**

### หนึ่ง หัวต่อการ์ดเป็นคนละชุดกับหัวต่อจอ

จากรูป หัวต่อ `SD_SCK` `SD_MISO` `SD_MOSI` `SD_CS` อยู่ที่ขอบขวาของบอร์ด
แยกจากหัวแถว SPI ของจอที่อยู่ขอบซ้าย **ต้องเดินสายเพิ่มสี่เส้น** ไม่ได้ต่อมาให้แล้ว

แต่สองในสี่เส้นใช้บัสร่วมกับจอได้เลย เหลือแค่สองเส้นที่ต้องมีขาของตัวเอง
ซึ่ง **ลงตำแหน่ง 6 กับ 7 ที่ว่างอยู่พอดี** สายยังไม่ไขว้กันเหมือนผังเดิม

| ขาบนหัวต่อการ์ด | ต่อไปที่ | หมายเหตุ |
|---|---|---|
| `SD_SCK` | `GPIO14` | เส้นเดียวกับ TFT SCL |
| `SD_MISO` | `GPIO6` | ขาใหม่ ตำแหน่ง 6 |
| `SD_MOSI` | `GPIO13` | เส้นเดียวกับ TFT SDA |
| `SD_CS` | `GPIO7` | ขาใหม่ ตำแหน่ง 7 |

ใช้บัสร่วมกันได้เพราะแยกกันด้วยขา CS และ **จอในผังนี้ไม่ได้ใช้ขา MISO** จึงไม่แย่งสายกัน
ของเดิมเปิดบัสด้วย `SPI_TFT.begin(TFT_SCLK, -1, TFT_MOSI, TFT_CS)` คือไม่มี MISO
ต้องแก้ให้มี ไม่งั้นอ่านการ์ดไม่ได้

### สอง ลำดับในโค้ดเดิมเอื้อพอดี

`processScanRequest()` **ส่งคำตอบให้จุดบริการก่อน แล้วค่อยเขียนไฟล์**
การ์ด SD เขียนช้ากว่าแฟลชในบอร์ดมาก บางจังหวะการ์ดหยุดลบบล็อกภายในเป็นร้อยมิลลิวินาที
ถ้าลำดับกลับกัน จุดบริการอาจรอจนหมดเวลาแล้วขึ้นว่าไม่ทราบผท ทั้งที่ทุกอย่างปกติ
ตรงนี้โค้ดเดิมทำถูกอยู่แล้ว ไม่ต้องแก้

### การ์ดเป็นสำเนา ไม่ใช่ที่เก็บหลัก

**LittleFS ยังเป็นที่เก็บหลักเหมือนเดิมทุกประการ** ตั้งใจออกแบบแบบนี้
เพราะการ์ดถอดออกได้ เสียได้ และไม่มีก็ได้ **ถ้าให้การ์ดเป็นที่เก็บหลัก
วันที่ลืมเสียบการ์ดคือวันที่ระบบจ่ายอาหารไม่ได้** ซึ่งขัดกับหลักที่วางกันไว้
ว่าระบบต้องไม่หยุดเพราะอุปกรณ์เสริม

| ไฟล์บนการ์ด | เขียนเมื่อไร |
|---|---|
| `/canteen/daily_log.csv` | ทุกครั้งที่มีนิสิตรับสิทธิ์สำเร็จ |
| `/canteen/arc_YYYYMMDD_HHMMSS.csv` | ตอนปิดยอดประจำวัน |
| `/canteen/students_backup.csv` | ทุกครั้งที่ทะเบียนนิสิตเปลี่ยน |

ประโยชน์จริงคือ **ถ้าบอร์ดแม่ข่ายพัง ถอดการ์ดไปเสียบคอมก็ได้ข้อมูลครบ**
ไม่ต้องไปกู้จากแฟลชในชิป และเก็บประวัติย้อนหลังได้ไม่ติดเพดาน 1 MB ของแฟลช

ถ้าไม่มีการ์ดก็ข้ามการเขียนไปเฉย ๆ และลองเมานต์ใหม่ทุกสามสิบวินาที
**เสียบการ์ดทีหลังได้โดยไม่ต้องรีบูต** และถ้าการ์ดหลุดกลางวันแล้วเสียบคืน
ระบบกลับมาบันทึกต่อเองโดยไม่ต้องมีใครสั่ง

เพิ่มแผงสถานะในหน้าตั้งค่าบนเว็บ บอกว่ากำลังบันทึกอยู่หรือไม่ ความจุเท่าไร
และเขียนพลาดไปกี่ครั้ง

### ตัวตรวจที่ผ่านทั้งที่ไม่ได้ตรวจ

หลังเพิ่มขา `SD_MISO_PIN` กับ `SD_CS_PIN` แล้ว `pincheck.py` ยังขึ้นว่าผ่าน
ดูเผิน ๆ เหมือนดี แต่ผมไปดูจำนวนขาที่มันรายงานแล้วพบว่า **ยังนับได้ 12 ขาเท่าเดิม**

ต้นเหตุคือ regex ของมันจับเฉพาะชื่อที่ขึ้นต้นด้วย `TFT_` `RC522_` `BUZZER` และอื่น ๆ
ที่มีอยู่ตอนเขียน **ขาที่ขึ้นต้นด้วย `SD_` จึงถูกมองข้ามเงียบ ๆ**
เป็นบั๊กชนิดเดียวกับที่เจอใน `packetcheck.py` รอบก่อน คือตัวตรวจที่บอกว่าผ่าน
ทั้งที่ไม่ได้ตรวจอะไรเลย แก้ regex แล้วตอนนี้นับได้ 14 ขาถูกต้อง

### ไฟล์วงจรตามไปด้วย

เพิ่มสัญลักษณ์หัวต่อการ์ดลงในวงจรของแม่ข่าย สร้างไฟล์ใหม่ด้วยสคริปต์
แล้วให้ KiCad เอ็กซ์พอร์ต netlist ออกมาตรวจ

ต้องแก้กติกาของ `kicadcheck.py` ด้วย เพราะเดิมบังคับว่า **เน็ตสัญญาณต้องมีสองปลายพอดี**
แต่ตอนนี้ `TFT_SCL` กับ `TFT_SDA` มีสามปลายโดยตั้งใจ คือบอร์ด จอ และการ์ด
เปลี่ยนเป็น "ต้องมีอย่างน้อยสองปลาย และถ้าเกินสองต้องอยู่ในรายการบัสที่ใช้ร่วมกัน"
ซึ่งเข้มกว่าเดิมด้วยซ้ำ เพราะยังจับกรณีขาชนกันโดยไม่ตั้งใจได้อยู่
พิสูจน์แล้วโดยลองเอา `TFT_SCL` ออกจากรายการ ตัวตรวจฟ้องทันที

### ก่อนใช้งาน

* การ์ดต้องฟอร์แมตเป็น **FAT32** ความจุไม่เกิน 32 GB
* เดินสายสี่เส้นตามตารางข้างบนก่อนแฟลช
* ถ้าเสียบการ์ดแล้วหน้าตั้งค่ายังขึ้นว่าไม่พบ ให้ดูสาย `SD_MISO` ก่อน
  เพราะเป็นเส้นเดียวที่ระบบเดิมไม่เคยใช้

---

## ไฟล์วงจรสำหรับ KiCad ทั้งสองบอร์ด (Host 113.10.0 / Station 122.12.0)

ท่านขอแบบการต่อวงจรเพื่อเอาไปใช้ใน KiCad

### สร้างด้วยสคริปต์ ไม่ได้วาดมือ

ผังขาอยู่ในซอร์สของเฟิร์มแวร์ ถ้าวาดมือแล้ววันหนึ่งย้ายขา
**ไฟล์วงจรจะเพี้ยนจากของจริงโดยไม่มีอะไรฟ้องเลย** ช่างก็จะเดินสายตามแบบที่ผิด
จนกว่าจะประกอบเสร็จแล้วใช้ไม่ได้ ซึ่งเป็นความผิดพลาดที่แพงที่สุดในงานฮาร์ดแวร์

`hardware/kicad/generate_kicad.py` จึง **อ่านค่า `#define` ของขาจากซอร์สจริง**
แล้วสร้างไฟล์วงจรใหม่ทั้งหมด สั่งรันซ้ำเมื่อไรก็ตรงกับเฟิร์มแวร์เสมอ

### สิ่งที่ได้

| ไฟล์ | ใช้ทำอะไร |
|---|---|
| `Canteen_Host.kicad_sch` · `.kicad_pro` | วงจรเครื่องแม่ข่าย เปิดด้วย KiCad ได้เลย |
| `Canteen_Station.kicad_sch` · `.kicad_pro` | วงจรจุดบริการ |
| `MCUPR_Canteen.kicad_sym` | ไลบรารีสัญลักษณ์ |
| `*.net` | netlist สำหรับนำเข้า Pcbnew และใช้ตรวจสอบ |
| `*.pdf` | ภาพวงจรสำหรับพิมพ์ ไม่ต้องมี KiCad ก็เปิดดูได้ |

**สัญลักษณ์ทุกตัวฝังอยู่ในไฟล์วงจรแล้ว** เปิดที่เครื่องไหนก็ได้โดยไม่ต้องติดตั้งไลบรารีเพิ่ม
ซึ่งจำเป็น เพราะบอร์ด ESP32-S3 DevKitC-1 จอ ST7789 และ RC522
ไม่มีอยู่ในไลบรารีมาตรฐานของ KiCad

### อ่านวงจรนี้อย่างไร

ไม่ได้ลากเส้นยาวข้ามหน้า แต่ใช้ **ป้ายชื่อเน็ต** ขาไหนที่มีป้ายชื่อเดียวกันคือขาที่ต่อถึงกัน
วิธีนี้ตรงกับงานเดินสายจริงมากกว่า เพราะสิ่งที่ช่างต้องรู้คือ "ขานี้ไปขาไหน"
ไม่ใช่ "เส้นวิ่งอ้อมทางไหน" และหน้ากระดาษก็ไม่รก

สัญลักษณ์ `U1` นับขา 1 ถึง 22 เป็นแถวซ้ายจากบนลงล่าง และ 23 ถึง 44 เป็นแถวขวา
ตรงกับตำแหน่งจริงบนบอร์ดและตรงกับตารางใน `docs/HARDWARE.md`

วงจรมีมากกว่าผังขา คือมีวงจรแบ่งแรงดัน 1:2 สำหรับวัดแบตเตอรี่
ตัวเก็บประจุกรองไฟของแต่ละโมดูล และตัวกรองสัญญาณรบกวนที่จุดวัด

### ตรวจด้วย KiCad ตัวจริง ไม่ได้เดาเอา

ผมติดตั้ง **KiCad 7 ลงในเครื่องที่ทำงานอยู่** เพื่อให้ตัวโปรแกรมเป็นคนบอกว่าไฟล์ถูกต้อง
ไม่ใช่ผมเดาเองแบบที่เคยพลาดมาแล้วในเซสชันนี้

* `kicad-cli sch export netlist` อ่านไฟล์วงจรได้และคำนวณเน็ตออกมาครบ
* `kicad-cli sch export pdf` และ `svg` พล็อตออกมาได้ ผมเปิดดูภาพแล้วจัดหน้าใหม่สองรอบ
  เพราะรอบแรกข้อความอ้างอิงทับตัวสัญลักษณ์ และภาษาไทยในกรอบชื่อเรื่องขึ้นเป็นกล่องสี่เหลี่ยม
  เนื่องจากฟอนต์มาตรฐานของ KiCad ไม่มีตัวอักษรไทย จึงเปลี่ยนกรอบชื่อเรื่องเป็นภาษาอังกฤษ

### ตัวตรวจใหม่ kicadcheck.py

เป็นตัวที่สิบ และทำงานต่างจากตัวอื่น คือ **ไม่ได้อ่านไฟล์วงจรตรง ๆ**
แต่อ่าน **netlist ที่ KiCad คำนวณออกมาเอง** แล้วเทียบกับค่าขาในซอร์สเฟิร์มแวร์
เท่ากับให้ KiCad เป็นคนยืนยันว่าเน็ตเชื่อมถึงกันจริง แล้วเราค่อยเทียบว่าตรงกับโค้ดไหม

ตรวจสามข้อ

1. ทุกขาที่เฟิร์มแวร์ใช้ ต้องอยู่ในเน็ตชื่อเดียวกันในไฟล์วงจร
2. เน็ตสัญญาณต้องมีสองปลายพอดี ปลายเดียวคือลืมต่อ สามปลายคือชนกัน
3. ขา GPIO หนึ่งขาต้องไม่ไปโผล่อยู่สองเน็ต

พิสูจน์แล้วโดยลองย้ายบัซเซอร์ในโค้ดจาก GPIO17 ไป GPIO16 โดยไม่สร้างแบบใหม่
ตัวตรวจฟ้องทันทีว่า `U1 ขา 9 ควรอยู่เน็ต BUZZER แต่ไม่อยู่`

---

## บอกสถานะก่อนนิสิตแตะบัตร และแยกกรณี "ไม่ทราบผล" ออกมา (Host 113.10.0 / Station 122.12.0)

ตามที่ตกลงกันไว้ว่าจะทำสองอย่าง

### หนึ่ง หน้าแรกบอกสถานะตั้งแต่ก่อนแตะบัตร

ของเดิมนิสิตต้องแตะก่อน แล้วยืนรอสามวินาที ถึงจะรู้ว่าแม่ข่ายล่ม
หลักสากลของเครื่องบริการตัวเองคือ **ต้องขึ้นสถานะหยุดให้บริการตั้งแต่ก่อนมีคนมาใช้**

หน้าแรกจึงบอกสถานะการให้บริการสามแบบ

| สถานะ | พาดหัว | สีคลื่นของสัญลักษณ์ |
|---|---|---|
| พร้อมรับบัตร | `TAP YOUR CARD` | เขียว |
| แม่ข่ายไม่ตอบ | `SERVER OFFLINE` | **เหลือง** |
| เครื่องอ่านบัตรไม่ตอบ | `OUT OF SERVICE` | **แดง** |

แยกสองความผิดพลาดด้วยคนละสี เพราะเป็นคนละเรื่องและแก้คนละทาง
เหลืองคือรอระบบกลับมา แดงคือฮาร์ดแวร์ของเครื่องนี้เสียต้องตามช่าง

และ **ปฏิเสธการแตะบัตรตั้งแต่ต้น** เมื่อรู้อยู่แล้วว่าแม่ข่ายไม่ตอบ
ไม่ส่งอะไรออกไปเลย รู้ผลทันทีไม่ต้องรอหมดเวลา

### สอง แยก "ไม่สำเร็จ" ออกจาก "ไม่ทราบผล"

นี่คือแกนของเรื่องทั้งหมด เดิมสองกรณีนี้ใช้หน้าจอเดียวกัน ทั้งที่ต่างกันโดยสิ้นเชิง

| กรณี | ตัดสิทธิ์ไปหรือยัง | หน้าจอใหม่ |
|---|---|---|
| รู้อยู่แล้วว่าแม่ข่ายไม่ตอบ จึงไม่ได้ส่งอะไรเลย | **ไม่** การันตีได้ | `SERVER OFFLINE` + *Nothing was taken from your quota* |
| ส่งไปแล้วไม่มีคำตอบใน 3 วินาที | **ไม่ทราบ** | `RESULT UNKNOWN` + *Your meal may or may not be recorded* |

กรณีที่สองเกิดเมื่อแม่ข่ายอนุมัติและบันทึกไปแล้ว แต่แพ็กเก็ตตอบกลับหายทั้งสามครั้ง
**การขึ้นว่า "ไม่สำเร็จ" ในกรณีนี้คือการบอกข้อมูลผิด** เพราะมันอาจสำเร็จไปแล้วจริง ๆ

เรื่องนี้แก้ให้หายขาดไม่ได้ในทางทฤษฎี เป็นปัญหา **Two Generals**
มาตรฐานจึงไม่พยายามกำจัด แต่ทำให้ **กู้คืนได้** แทน
แถบล่างของหน้านั้นจึงบอกว่า *Tap your card again to see the real result*
ซึ่งใช้กลไกที่ระบบมีอยู่แล้ว ถ้าบันทึกไปแล้วจะได้ `ALREADY SERVED`
ถ้ายังไม่ได้บันทึกก็จะตัดสิทธิ์ให้ตามปกติ **ไม่ว่าทางไหนก็ได้คำตอบที่ถูกต้อง และไม่มีทางจ่ายซ้ำ**

### สิ่งที่ตรวจแล้วพบว่าออกแบบไว้ดีอยู่แล้ว

ระหว่างไล่โค้ดเพื่อตอบคำถามนี้ พบว่าแม่ข่าย **กันการทำซ้ำด้วยคู่ `(หมายเลขจุดบริการ, seq)`
แล้วส่งคำตอบเดิมที่แคชไว้กลับไป ไม่ประมวลผลใหม่** ซึ่งคือ idempotent request ตามมาตรฐาน
ถ้าไม่มีอันนี้ การส่งซ้ำสามครั้งของจุดบริการจะกลายเป็นตัดสิทธิ์สามครั้ง
ส่วนนี้ไม่ต้องแก้อะไรเลย

### ตรวจแล้ว

เพิ่มกรณีทดสอบระดับพิกเซลสามกรณีสำหรับการสลับสถานะ
พร้อม→แม่ข่ายล่ม, แม่ข่ายล่ม→พร้อม และเครื่องอ่านเสีย→แม่ข่ายล่ม
**ทุกกรณีตรงกับการวาดใหม่ทั้งหน้าทุกพิกเซล ทั้งโหมดมืดและสว่าง**
เส้นทางที่วาดทุกวินาทียังล้างพื้น 0 ครั้ง ตัวตรวจทั้งเก้าตัวผ่าน
และเพิ่มหัวข้อ **เมื่อเครื่องแม่ข่ายไม่ตอบ** ลงใน README อธิบายนโยบายทั้งหมด

---

## จัดขาใหม่ทั้งสองบอร์ดให้สายไม่ไขว้กัน (Host 113.10.0 / Station 122.11.0)

ท่านขอให้ออกแบบการเชื่อมต่อใหม่ทั้งสองฝั่ง **ให้ขาของอุปกรณ์เรียงติดกัน ไม่ข้ามกัน**
เพื่อให้เดินสายง่าย พร้อมส่งผังขาของบอร์ดมาให้ดู

### ปัญหาของผังเดิม

ฝั่งจุดบริการหนักที่สุด ขาของ RC522 กระจายอยู่สี่ที่

| ขา | ผังเดิม | อยู่ตรงไหน |
|---|---|---|
| SCK | GPIO4 | แถวซ้าย ตำแหน่ง 4 |
| MOSI | GPIO5 | แถวซ้าย ตำแหน่ง 5 |
| SS | GPIO7 | แถวซ้าย ตำแหน่ง 7 |
| RST | GPIO17 | แถวซ้าย ตำแหน่ง 10 |
| **MISO** | **GPIO21** | **แถวขวา ตำแหน่ง 18** |

สาย MISO เส้นเดียวต้องอ้อมข้ามบอร์ดไปอีกฝั่ง และไฟหน้าจอ (BLK) ก็อยู่ที่ GPIO15
ซึ่งห่างจากขาจออีกห้าขาที่เหลือ

### ผังใหม่

**อุปกรณ์ภายนอกทุกตัวอยู่บนแถวซ้ายของบอร์ดแถวเดียว แถวขวาไม่ได้ต่ออะไรเลย**

| ตำแหน่ง | ขา | เครื่องแม่ข่าย | จุดบริการ |
|:---:|:---|:---|:---|
| 4 | GPIO4 | DS3231 SDA | RC522 SDA (SS) |
| 5 | GPIO5 | DS3231 SCL | RC522 SCK |
| 6 | GPIO6 | ว่าง | RC522 MOSI |
| 7 | GPIO7 | ว่าง | RC522 MISO |
| 8 | GPIO15 | ว่าง | RC522 RST |
| 10 | GPIO17 | บัซเซอร์ | บัซเซอร์ |
| 11 | GPIO18 | ปุ่มกด | ปุ่มกด |
| 12 | GPIO8 | วัดแบตเตอรี่ | วัดแบตเตอรี่ |
| 15–20 | GPIO9–14 | จอ BLK CS DC RES SDA SCL | จอ BLK CS DC RES SDA SCL |

**บัซเซอร์ ปุ่มกด และสายวัดแบตเตอรี่ใช้ขาเดียวกันทั้งสองบอร์ด**
ประกอบสายชุดเดียวแล้วสลับใช้ได้ทั้งสองฝั่ง

### จอเสียบตรงลงมาได้ทั้งแถว

จุดที่ลงตัวที่สุดของผังนี้ โมดูลจอ 8 ขาเรียงว่า `GND VCC SCL SDA RES DC CS BLK`
พอไล่ตำแหน่งบนบอร์ด **จากล่างขึ้นบน** จะได้

```
ตำแหน่ง 22 GND  <- GND      ตำแหน่ง 18 GPIO12 <- RES
ตำแหน่ง 21 5V0  <- VCC      ตำแหน่ง 17 GPIO11 <- DC
ตำแหน่ง 20 GPIO14 <- SCL    ตำแหน่ง 16 GPIO10 <- CS
ตำแหน่ง 19 GPIO13 <- SDA    ตำแหน่ง 15 GPIO9  <- BLK
```

**ตรงกันขาต่อขาทั้งแปดเส้น** สายแพเส้นเดียววางขนานลงมาได้เลย
ที่ลงตัวเพราะขา CS DC RES SDA SCL ของจอ **ใช้ GPIO10 ถึง 14 อยู่แล้วตั้งแต่ต้น**
ย้ายแค่ BLK จาก GPIO15 มาที่ GPIO9 เท่านั้น จอจึงแทบไม่ต้องรื้อสายเลย

> ⚠️ จอ ST7789 บางรุ่นรับ 3.3V เท่านั้น ถ้าเป็นแบบนั้นให้ต่อ VCC ไปที่ขา 3V3 ด้านบน
> แทนตำแหน่ง 21 **ตรวจสเปกจอของท่านก่อนจ่ายไฟ**

### เจอปัญหาเดิมที่ซ่อนอยู่ระหว่างทาง

ระหว่างเขียนตัวตรวจ พบว่าผังเดิมของฝั่งจุดบริการ
**วัดแรงดันแบตเตอรี่ที่ GPIO3 ซึ่งเป็นขา strapping** (ใช้เลือกแหล่ง JTAG ตอนบูต)
ต่อวงจรแบ่งแรงดันค้างไว้ที่ขานี้ทำให้ระดับแรงดันตอนบูตเพี้ยนได้
ผังใหม่ย้ายไปที่ GPIO8 ซึ่งเป็น ADC1_CH7 ปกติ

### ตัวตรวจใหม่ pincheck.py

เพิ่มเป็นตัวที่เก้า อ่านค่าขาจากซอร์สจริงของทั้งสองบอร์ด แล้วฟ้องเมื่อ

* มีขาไหนถูกใช้ซ้ำสองหน้าที่ในบอร์ดเดียวกัน
* มีขาไหนไปโดนขาต้องห้าม โดยเฉพาะ **GPIO33–37 ที่ PSRAM แบบ OPI จองไว้**
  ซึ่ง GPIO35 36 37 โผล่อยู่บนแถวขวาของบอร์ดและดูเหมือนใช้ได้ เป็นกับดักที่เจอบ่อยที่สุด
* ขาวัดแบตเตอรี่ไม่ได้อยู่ใน ADC1 เพราะ **ADC2 อ่านไม่ได้ขณะเปิด Wi-Fi**

พิสูจน์แล้วสองทาง รันกับผังเดิมจับ GPIO3 ได้ และลองย้ายบัซเซอร์ไปทับขาจอ
ก็ฟ้องว่า GPIO14 ถูกใช้ซ้ำ

### เอกสารใหม่

ผังเต็มพร้อมลำดับขาของทุกโมดูล ข้อควรระวังเรื่องแรงดัน และรายการขาต้องห้าม
อยู่ใน [`docs/HARDWARE.md`](docs/HARDWARE.md)

**ครั้งนี้ต้องรื้อสายจริงนะครับ** โดยเฉพาะฝั่งจุดบริการ
ตรวจให้ครบก่อนจ่ายไฟ และถ้าจอไม่ติดหลังแฟลช ให้ดูขา BLK ที่ย้ายจาก GPIO15 ไป GPIO9 ก่อน

---

## ต้นเหตุจริงของการหน่วงห้าวินาที: วิทยุของจุดบริการหลับ (Host 113.9.0 / Station 122.10.0)

ท่านแจ้งว่าหลังแก้รอบที่แล้ว **ยังหน่วงราวห้าวินาทีเท่าเดิม**

แปลว่าคำวินิจฉัยเดิมของผมยังไม่ถึงต้นตอ รอบที่แล้วผมแก้ **ฝั่งผู้ส่ง**
ให้ส่งยูนิแคสต์แทนการกระจายเสียงอย่างเดียว แต่ปัญหาอยู่ที่ **ฝั่งผู้รับ**

### ไล่ใหม่จากหลักฐาน

ลูปของจุดบริการตรวจ `pendingConfigUpdate` ทุกหนึ่งรอบ ซึ่งวนเร็วราวสองมิลลิวินาที
ถ้าแพ็กเก็ตมาถึงจริง คำสั่งจะถูกทำภายในเสี้ยววินาที **แปลว่าแพ็กเก็ตไม่ได้มาถึง**

แล้วทำไมมันมาถึงตอนห้าวินาที คำตอบคือ **มันมาถึงตอนที่จุดบริการเพิ่งส่ง heartbeat ออกไปเอง**
ทิศทางจากจุดบริการไปแม่ข่ายเร็วเสมอ แต่ทิศกลับช้า นั่นคือลายเซ็นของ
**ตัวรับที่หลับอยู่ แล้วตื่นเฉพาะตอนที่ตัวเองเพิ่งส่ง**

### ต้นเหตุ

โค้ดฝั่งจุดบริการสั่งปิดโหมดประหยัดพลังงานไว้แล้วด้วย `esp_wifi_set_ps(WIFI_PS_NONE)`
ดูเผิน ๆ เหมือนถูกต้อง แต่ **Arduino core สั่งทับกลับ**

ผมดาวน์โหลดซอร์สของ core มาอ่านยืนยัน ในไฟล์ `libraries/WiFi/src/STA.cpp`

```c
if (ev->event_id == ARDUINO_EVENT_WIFI_STA_START) {
  _sta_network_if->_setStatus(WL_DISCONNECTED);
  if (esp_wifi_set_ps(WiFi.getSleep()) != ESP_OK) {   // <-- ทับค่าที่เราตั้ง
```

`WiFi.getSleep()` คืนค่าที่ core จำไว้ ซึ่งใน `WiFiGeneric.cpp` ตั้งค่าเริ่มต้นไว้ว่า

```c
#if CONFIG_IDF_TARGET_ESP32S2
wifi_ps_type_t WiFiGenericClass::_sleepEnabled = WIFI_PS_NONE;
#else
wifi_ps_type_t WiFiGenericClass::_sleepEnabled = WIFI_PS_MIN_MODEM;   // <-- ESP32-S3 มาทางนี้
#endif
```

อีเวนต์ `STA_START` เป็นแบบ **อะซิงโครนัส** มันถูกส่งมาจากทาสก์อีเวนต์ของ core
จึงมาถึง **หลัง** บรรทัด `esp_wifi_set_ps(WIFI_PS_NONE)` ของเราไปแล้ว
ค่าที่เราตั้งจึงถูกเปลี่ยนกลับเป็นโหมดประหยัดพลังงานเงียบ ๆ ไม่มีคำเตือนอะไรทั้งสิ้น

ผลคือวิทยุของจุดบริการหลับเป็นช่วง ๆ แพ็กเก็ตที่แม่ข่ายส่งมาแบบไม่ได้นัดหมายจึงตกหล่น
จะได้รับแน่ ๆ ก็ตอนที่เพิ่งส่ง heartbeat ออกไปเอง ซึ่งเกิดทุก
`6000 + หมายเลขสถานี × 350` มิลลิวินาที **ตรงกับห้าวินาทีที่ท่านจับได้พอดี**

### วิธีแก้

ใช้ `WiFi.setSleep(false)` แทน ซึ่งเปลี่ยน **ทั้งค่าที่ core จำไว้และค่าที่ใช้งานจริง**
อีเวนต์ที่ตามมาภายหลังจึงสั่งค่าเดิมซ้ำ ไม่ได้ทับให้กลับไปหลับอีก
ส่วน `esp_wifi_set_ps(WIFI_PS_NONE)` เดิมยังคงไว้เป็นชั้นสำรอง

### ทำไมฝั่งแม่ข่ายไม่เป็น

แม่ข่ายเป็น AP และไฟล์ `AP.cpp` ของ core **ไม่มี** การสั่งทับแบบนี้เลย
ค่าที่แม่ข่ายตั้งไว้จึงอยู่ครบ ตรงกับที่สังเกตได้ว่าทิศจากจุดบริการมาแม่ข่ายเร็วเสมอ

### เสริมความทนทานฝั่งแม่ข่ายไปด้วย

ของเดิมย้ำคำสั่งสามรอบติดกันด้วย `delay(30)` รวมแล้วกินเวลาแค่ 90 มิลลิวินาที
ถ้าจุดบริการพลาดช่วงสั้น ๆ นั้นไป ก็ต้องรอ heartbeat รอบถัดไปอยู่ดี

เปลี่ยนเป็นย้ำหกรอบ **กระจายออกไปราวสองวินาที โดยให้ `loop()` เป็นคนส่ง**
ไม่หน่วงลูปเลยสักมิลลิวินาที หน้าเว็บจึงตอบกลับทันทีและจอของแม่ข่ายไม่สะดุด
ข้อดีคือทนทานต่อการตกหล่นของสัญญาณโดยไม่ต้องพึ่งว่าคำวินิจฉัยข้างบนถูกต้อง 100%

### ขออภัยที่ต้องแก้สองรอบ

รอบที่แล้วผมด่วนสรุปจากบั๊กที่เห็นชัดในโค้ด คือแพ็กเก็ตกระจายเสียงที่ใส่ฟิลด์ไม่ครบ
ซึ่ง **เป็นบั๊กจริงและควรแก้** แต่ไม่ใช่ตัวที่ทำให้หน่วง ผมน่าจะเอะใจตั้งแต่ตอนที่ท่าน
บอกว่าการสลับสว่างมืดก็ช้าเท่ากัน ทั้งที่ค่าโหมดสีนั้นส่งถูกต้องมาตลอด
จุดนั้นคือหลักฐานว่าปัญหาอยู่ที่ตัวรับ ไม่ใช่ตัวส่ง

---

## ขีดสัญญาณมุมขวาบนของจุดบริการหายไป (Host 113.8.0 / Station 122.9.0)

ท่านแจ้งว่าฝั่งจุดบริการ **ไม่แสดงสัญลักษณ์ระดับสัญญาณ แต่แสดงเป็นตัวเลขแทน**
และต้องการให้เหลือแค่สัญลักษณ์ ไม่ต้องการตัวเลข

เป็นสองเรื่องที่มาพร้อมกัน เรื่องหนึ่งเป็นบั๊ก อีกเรื่องเป็นสิ่งที่ท่านอยากได้

### บั๊ก ขีดสัญญาณหายถาวรหลังเปลี่ยนหน้าครั้งแรก

`drawStationTopBar()` ซึ่งถูกเรียกทุกครั้งที่วาดหน้าใหม่ เริ่มด้วยการล้างแถบบนทั้งแถบ
`tft.fillRect(0, 0, 320, 24, ...)` แล้ววาดคืนแค่ **ชื่อหน้ากับแบตเตอรี่**
ขีดสัญญาณที่เพิ่งถูกลบไปไม่มีใครวาดคืนให้

แล้วทำไมมันไม่กลับมาเองในรอบถัดไป เพราะ `updateTopRightHeaderSmooth()` ที่เดินทุกวินาที
**จำไว้ว่าเคยวาดกี่ขีด** ถ้าจำนวนขีดกับสถานะออนไลน์ยังเท่าเดิม มันจะ `return` ทิ้งทันที
โดยไม่วาดอะไรเลย ซึ่งเป็นกลไกกันจอกะพริบที่ใส่ไว้ตั้งแต่รุ่น 122.3.0

สองอย่างนี้รวมกันแล้วได้ผลลัพธ์คือ **ขีดหายไปเลยจนกว่าความแรงสัญญาณจะข้ามขั้น**
ซึ่งนาน ๆ ทีถึงจะเกิด ส่วนตัวเลข dBm ยังอยู่เพราะบรรทัดนั้นเขียนทับที่เดิมได้
แม้จะ `return` ไปแล้วก็ตาม ตรงกับที่ท่านเห็นพอดี คือเหลือแต่ตัวเลข ไม่มีขีด

แก้โดยให้ `drawStationTopBar()` เรียกตัวอัปเดตแบบ **บังคับวาด** แทนการวาดแบตเตอรี่เอง
ตัวอัปเดตวาดทั้งขีดสัญญาณและแบตเตอรี่ให้ในตัวอยู่แล้ว และยังตั้งค่าที่จำไว้
ให้ตรงกับของจริงไปพร้อมกัน ขีดจึงอยู่ครบทุกหน้าทุกครั้ง

### ตัดตัวเลขออกตามที่ต้องการ

ตัดทั้งตัวเลข `-63dB` และคำว่า `OFFLINE` ออกจากแถบบน เหลือแต่ขีดสัญญาณอย่างเดียว

ตอนขาดการเชื่อมต่อ เดิมอาศัยคำว่า OFFLINE เป็นตัวบอก พอตัดคำออกแล้ว
ขีดที่ว่างทั้งสี่จะดูไม่ต่างจาก "สัญญาณอ่อนมาก" จึงให้ **โครงขีดทั้งสี่เป็นสีแดง**
ตอนขาดการเชื่อมต่อ ต่างจากสีจางตามปกติ ดูแวบเดียวก็แยกออก

ค่า dBm ที่เป็นตัวเลขยังดูได้เหมือนเดิมที่หน้า SYSTEM แถว `Host link`
และสถานะออนไลน์ยังมีป้ายเต็มคำอยู่ที่หน้า 2 ไม่ได้หายไปไหน

### ตรวจฝั่งแม่ข่ายด้วยแล้ว

แถบบนของแม่ข่ายไม่มีขีดสัญญาณอยู่แล้ว มีแค่เลขหน้ากับแบตเตอรี่ จึงไม่มีอาการนี้
ส่วนขีดสัญญาณบนการ์ดร้านหน้า SHOPS นั้นเขียนไว้ถูกแล้ว เพราะหลังล้างพื้นมันสั่ง
`lastBars[i] = -1` บังคับให้วาดใหม่ ไม่ได้ปล่อยให้ค่าที่จำไว้ค้าง

---

## เปลี่ยนคำว่า Point เป็น Station ทั้งระบบ (Host 113.8.0 / Station 122.8.0)

ท่านทักว่าผมใช้คำว่า **Point** ทั้งที่ควรเป็น **station** หรือ **shop**

ถูกต้องครับ และที่แย่กว่านั้นคือมัน **ไม่ตรงกับอะไรเลยในระบบตัวเอง**
ชื่อไฟล์คือ `Canteen_Station_Client` ตัวแปรคือ `currentStationId` `stationNodes`
โปรโตคอลคือ `HostConfigPacket.stationId` แต่สิ่งที่ผู้ใช้เห็นบนจอกลับเขียนว่า Point
เปิดโค้ดกับมองจอแล้วเหมือนคนละระบบ

### แยกสองคำให้ชัด

| สิ่งที่หมายถึง | คำที่ใช้ | เหตุผล |
|---|---|---|
| ตัวเครื่องที่ตั้งอยู่หน้าร้าน | **Station** | ตรงกับชื่อไฟล์ ตัวแปร และโปรโตคอลทั้งหมด |
| ร้านค้าและผู้ประกอบการ | **Shop** | ใช้อยู่แล้วและไม่ได้แตะ |

หน้า SHOPS ของแม่ข่ายเห็นความต่างนี้ชัดที่สุด การ์ดแต่ละใบขึ้น **ชื่อร้าน** เป็นบรรทัดแรก
แล้วมี **Station N** เป็นบรรทัดรอง คือร้านชื่ออะไร และเครื่องตัวไหนตั้งอยู่ที่นั่น

### จุดที่เปลี่ยน

| ที่ | เดิม | ใหม่ |
|---|---|---|
| จอแม่ข่าย หน้า SHOPS | `Point N` | `Station N` |
| จอแม่ข่าย หน้า SYSTEM | `4 service points linked` | `4 stations linked` |
| จอแม่ข่าย รายการแตะบัตรล่าสุด | `Point N card ...` | `Station N card ...` |
| จอแม่ข่าย หน้าแจ้งผลเต็มจอ | `SERVICE POINT` / `Point N` | `STATION` / `Station N` |
| จอจุดบริการ แถบบนทุกหน้า | `POINT N` | `STATION N` |
| จอจุดบริการ หน้าบูต | `Service point` / `Point N` | `Canteen station` / `Station N` |
| จอจุดบริการ หน้า 2 | `THIS POINT` | `THIS STATION` |
| จอจุดบริการ หน้า SYSTEM | `Service point` / `Point N` | `Station` / `No. N` |
| จอจุดบริการ ตั้งหมายเลข | `POINT NUMBER` / `CHOOSE THIS POINT` | `STATION NUMBER` / `CHOOSE THIS STATION` |
| จอจุดบริการ หน้าแจ้งผล | `Point N` | `Station N` |
| หน้าเว็บ แท็บ Today | `Service points` / `Point N` | `Stations` / `Station N` |
| หน้าเว็บ แท็บ Settings | `Display on all service points` | `Display on all stations` |
| หน้าเว็บ ข้อความแจ้ง | `Service points updated` | `Stations updated` |

**คำไทยไม่ได้แตะเลย** ยังเป็น "จุดบริการ" และ "จุดที่" เหมือนเดิม เพราะคำไทยถูกอยู่แล้ว
ปัญหาอยู่ที่คำอังกฤษฝั่งเดียว

จุดหนึ่งที่ต้องขยับพิกัดด้วยคือชื่อบนการ์ดหน้าบูตของจุดบริการ
`Station N` กว้างกว่า `Point N` อยู่ 24 พิกเซล เลื่อนจุดเริ่มจาก x 85 เป็น 106
ข้อความจึงกลับมาอยู่กลางการ์ดเหมือนเดิม

### เก็บกวาดที่เจอระหว่างทาง

* โปรแกรมจำลองจอมีฟังก์ชัน `stOfflineSaved()` กับ `stOfflineRejected()` ตกค้างอยู่
  เป็นหน้าจอของฟีเจอร์คิวออฟไลน์ที่ถูกตัดออกจากเฟิร์มแวร์ไปตั้งแต่รุ่น 122.0.0
  ไม่ได้ถูกเรียกใช้และไม่เคยถูกเรนเดอร์ แต่ทำให้คนอ่านเข้าใจผิดว่ายังมีอยู่ ลบทิ้งแล้ว
* สคริปต์ถ่ายภาพหน้าเว็บในเครื่องมือของผมใช้ข้อมูลจำลองรูปแบบเก่า
  ซึ่งไม่ตรงกับที่ `/api/dashboard` ส่งจริงในรุ่นปัจจุบัน ภาพที่ได้จึงว่างเปล่าทั้งหน้า
  แก้ให้ตรงกับรูปแบบจริงแล้วถ่ายใหม่

ภาพในคู่มือถูกถ่ายใหม่ทั้งหมดแล้ว ทั้งจอ TFT สองฝั่งและหน้าเว็บ
ตัวตรวจทั้งแปดตัวผ่าน และการทดสอบระดับพิกเซลยังตรงกันทุกกรณี

---

## คำสั่งเปลี่ยนโหมดการแสดงผลไปถึงจุดบริการทันที (Host 113.7.0 / Station 122.7.0)

ท่านถามว่าสั่งให้พักหน้าจอหรือสลับสว่าง/มืดแล้ว **ฝั่งจุดบริการใช้เวลาราวห้าวินาที
กว่าจะเปลี่ยนตาม เป็นปกติหรือไม่ ทำไมไม่เปลี่ยนแบบเรียลไทม์**

**ไม่ปกติครับ เป็นบั๊ก** และไล่เจอสองจุดซ้อนกัน

### จุดที่หนึ่ง แพ็กเก็ตกระจายเสียงใส่ฟิลด์ไม่ครบ

`HostConfigPacket` มีเจ็ดฟิลด์ และในโค้ดมี `fillStationConfig()` เขียนไว้อยู่แล้ว
เป็นที่เดียวสำหรับประกอบแพ็กเก็ตนี้ พร้อมคอมเมนต์กำกับว่า
*"ชุดเดียวใช้ร่วมกันทุกที่ จะได้ไม่มีทางส่งค่าไม่ตรงกัน"*

แต่ `broadcastStationTheme()` **ไม่ได้เรียกมัน** กลับประกอบแพ็กเก็ตเองทีละฟิลด์
แล้วหยุดที่ `darkMode` ฟิลด์ที่เหลือจึงเป็นศูนย์ติดไปทุกครั้ง

| ฟิลด์ | ค่าที่ควรส่ง | ค่าที่ส่งจริง |
|---|---|---|
| `darkMode` | ค่าปัจจุบัน | ถูกต้อง |
| `screenOn` | ค่าปัจจุบัน | **0** |
| `screensaver` | ค่าปัจจุบัน | **0** |
| `modeSeq` | เลขลำดับปัจจุบัน | **0** |

ฝั่งจุดบริการกันคำสั่งซ้ำด้วย `modeSeq` เมื่อเลขไม่เคยขยับจากศูนย์
**คำสั่งพักหน้าจอจึงไม่เคยเดินทางมากับการกระจายเสียงเลยสักครั้ง**

แล้วมันไปถึงได้อย่างไร คำตอบคือทางอ้อม ทุกครั้งที่จุดบริการส่ง heartbeat มา
แม่ข่ายจะตอบกลับแล้วแนบ `sendStationTheme()` ไปด้วย ซึ่งเส้นทางนี้เรียก
`fillStationConfig()` อย่างถูกต้อง จุดบริการจึงได้ค่าจริง **แต่ต้องรอรอบ heartbeat**
ซึ่งตั้งไว้ที่ `6000 + หมายเลขจุด × 350` มิลลิวินาที ตรงกับห้าวินาทีที่ท่านจับได้พอดี

### จุดที่สอง สั่งเปลี่ยนธีมตอนพักหน้าจออยู่ จะถูกเตะออกจากหน้าพักจอ

ฝั่งจุดบริการ เมื่อธีมเปลี่ยนมันจะเรียก `showStationPage()` เพื่อวาดใหม่
แต่ฟังก์ชันนั้น **ตั้ง `currentState` เป็น STANDBY หรือ STATUS เสมอ**
ถ้าตอนนั้นกำลังพักหน้าจออยู่ การสั่งเปลี่ยนธีมอย่างเดียวจะเตะมันออกมา
และไม่กลับเข้าไปอีก เพราะ `modeSeq` ไม่ได้เปลี่ยน คำสั่งพักจอจึงไม่ถูกทำซ้ำ
แก้ให้วาดใหม่ตามหน้าที่แสดงอยู่จริง ไม่ไปเปลี่ยนสถานะของเครื่อง

### วิธีแก้เรื่องความเร็ว

* `broadcastStationTheme()` เรียก `fillStationConfig()` เหมือนทุกที่ ค่าครบและตรงกันเสมอ
* `announceDisplayMode()` **ส่งยูนิแคสต์ถึงทุกจุดบริการที่แม่ข่ายรู้จัก MAC แล้วก่อน**
  แล้วค่อยกระจายเสียงตามไป ทำสามรอบเหมือนเดิม

ที่เลือกยูนิแคสต์เป็นหลักเพราะ **ชั้นยูนิแคสต์ของ ESP-NOW มีการตอบรับและส่งซ้ำให้ในตัว**
ต่างจากการกระจายเสียงที่ยิงออกไปแล้วไม่มีใครยืนยัน และที่สำคัญกว่านั้นคือ
มันเป็นเส้นทางเดียวกับที่ใช้ตอบ heartbeat ซึ่ง **พิสูจน์แล้วจากอาการของท่านเองว่าถึงแน่นอน**
ส่วนการกระจายเสียงยังคงไว้ เผื่อจุดบริการที่เพิ่งเปิดเครื่องและยังไม่เคยส่งอะไรมา
แม่ข่ายจึงยังไม่รู้ MAC ของมัน

### ตัวตรวจใหม่ และตัวตรวจที่ไม่ได้ทำงาน

เพิ่ม `packetcheck.py` บังคับว่าทุกที่ที่ประกอบ `HostConfigPacket` ต้องเรียก
`fillStationConfig()` ห้ามตั้ง `msgType = MSG_CONFIG` เองที่อื่น

ระหว่างพิสูจน์ว่ามันจับได้จริง **พบว่าตัวตรวจใหม่นี้ไม่ได้ทำงานเลย** มันขึ้นว่า OK
ทั้งที่รันกับคอมมิตที่เสียจริง ต้นเหตุคือมัน `import body_of` มาจาก `privacycheck.py`
ซึ่ง **ไม่มี `if __name__ == '__main__'`** พอถูก import ไฟล์นั้นจึงรันตัวเองแล้ว
`sys.exit()` ทิ้งทันที ผลที่ผมเห็นว่า "OK" คือผลของ `privacycheck` ไม่ใช่ของตัวใหม่

แก้สองชั้น

* ห่อเนื้อการตรวจของ `privacycheck.py` ไว้ใน `main()` แล้วเรียกผ่าน `__main__` guard
  แบบเดียวกับ `bracecheck.py` ที่ทำถูกอยู่แล้ว
* เพิ่ม `runall.py` รันตัวตรวจทุกตัวเป็น **โปรเซสแยก** ไม่ใช่การ import
  และถือว่า **ตัวตรวจที่ไม่พิมพ์อะไรออกมาเลยคือไม่ผ่าน** ไม่ใช่ผ่านเงียบ ๆ
  ต่อไปสั่ง `python3 tools/proto-check/runall.py` ครั้งเดียวจบ

หลังแก้แล้ว `packetcheck.py` ฟ้องบรรทัดที่ 580 ของคอมมิตที่เสีย ตรงจุดพอดี

### ที่ยังต้องรบกวนท่านยืนยัน

ผมพิสูจน์จากโค้ดได้เต็มร้อยว่า **คำสั่งพักหน้าจอ** ไปไม่ถึงทางการกระจายเสียง
ส่วน **การสลับสว่าง/มืด** นั้นค่าที่ส่งถูกต้องอยู่แล้ว ตามทฤษฎีจึงควรเปลี่ยนทันที
แต่ท่านบอกว่าช้าเท่ากัน แปลว่าแพ็กเก็ตกระจายเสียงน่าจะไปไม่ถึงตั้งแต่แรก
ซึ่งเป็นเรื่องคลื่นวิทยุที่ผมวัดจากตรงนี้ไม่ได้

การแก้ครั้งนี้ครอบคลุมทั้งสองกรณี เพราะย้ายมาใช้เส้นทางยูนิแคสต์ที่ถึงแน่นอน
**รบกวนท่านลองจับเวลาอีกครั้งหลังแฟลช** ทั้งการพักหน้าจอและการสลับสี

---

## คลื่นของสัญลักษณ์แตะบัตรไม่ขึ้นบนจอจริง (Host 113.6.0 / Station 122.6.2)

ท่านแจ้งว่าคอมไพล์ผ่านแล้ว แต่ **"ไอคอนไม่สมบูรณ์ ขาดตัวเส้นสีเขียวที่แสดงถึงคลื่นจากการ์ด"**
คือตัวบัตรขึ้นครบ แต่คลื่นสามชั้นหายไปทั้งหมด

### ต้นเหตุ

Adafruit GFX แบ่งฟังก์ชันวาดเป็นสองพวก ซึ่งผมไม่ได้แยกแยะตอนเขียน

| พวก | ตัวอย่าง | เรียกเดี่ยว ๆ ได้ไหม |
|---|---|---|
| มี `startWrite()`/`endWrite()` ในตัว | `drawPixel` `fillRect` `drawRoundRect` `drawFastHLine` | ได้ |
| ไม่มี เรียก `writePixel()` ตรง ๆ | `writePixel` `writeLine` **`drawCircleHelper`** `fillCircleHelper` | **ไม่ได้** |

ผมดาวน์โหลดซอร์สของไลบรารีมาอ่านยืนยันแล้ว `drawCircleHelper()` ไม่มี `startWrite()`
เพราะมันถูกออกแบบมาให้ถูกเรียก **จากข้างใน** `drawRoundRect()` ซึ่ง `startWrite()` ไว้ก่อนแล้ว

เมื่อเราเรียกมันเดี่ยว ๆ ทรานแซกชัน SPI ไม่ถูกเปิด **ขา CS ไม่ถูกดึงลง จอจึงไม่ได้รับข้อมูลเลย**
นี่คือเหตุผลที่ตัวบัตรขึ้นครบ เพราะวาดด้วย `drawRoundRect` `fillRoundRect` `drawFastHLine`
ซึ่งอยู่ในพวกแรกทั้งหมด ส่วนคลื่นที่วาดด้วย `drawCircleHelper` หายไปทั้งเส้น
ตรงกับอาการที่ท่านเห็นพอดี

โค้ดชุดนี้ลอกมาจากรุ่น 118.1.0 ทั้งดุ้น แปลว่า **บั๊กนี้มีมาตั้งแต่ตอนนั้น**
คลื่นน่าจะไม่เคยขึ้นบนเครื่องจริงเลย

### วิธีแก้

เขียนวงกลมครึ่งขวาเองด้วยอัลกอริทึมของ Bresenham ชุดเดียวกับไลบรารี
แต่ลงจุดด้วย `tft.drawPixel()` ซึ่งเปิดและปิดทรานแซกชันให้เองทุกจุด
เลือกทางนี้แทนการครอบด้วย `startWrite()`/`endWrite()` เพราะไม่ต้องไปพึ่งรายละเอียด
ภายในของไลบรารีที่อาจเปลี่ยนในรุ่นถัดไป และเพิ่ม **จุดขวาสุด** ที่ลูปของไลบรารีข้ามไป
ปลายโค้งจึงไม่ขาดหนึ่งพิกเซลอย่างของเดิม

วาดทั้งหมดราวสามร้อยจุด เฉพาะตอนเข้าหน้าและตอนสถานะเปลี่ยน ไม่ใช่ทุกวินาที

### ทำไมตัวตรวจกับภาพตัวอย่างไม่เห็นบั๊กนี้

**ภาพตัวอย่างคือตัวการ** โปรแกรมจำลองของผมวาดส่วนโค้งด้วย `g.arc()` ของ canvas
ซึ่ง **วาดสำเร็จเสมอ** ภาพจึงออกมาสวยและผมก็เชื่อว่ามันถูก
บทเรียนคือโปรแกรมจำลองที่ "ใจดีเกินจริง" อันตรายกว่าการไม่มีโปรแกรมจำลองเลย
เพราะมันให้ความมั่นใจปลอม ๆ

แก้สองอย่าง

* เปลี่ยนโปรแกรมจำลองมาลงจุดทีละพิกเซลด้วย Bresenham ชุดเดียวกับเฟิร์มแวร์
  ภาพตัวอย่างตอนนี้จึงเป็นพิกเซลชุดเดียวกับที่จอได้รับจริง ขอบหยักเหมือนของจริง
* เพิ่ม `tools/proto-check/gfxcheck.py` เป็นตัวที่แปด ฟ้องทันทีถ้ามีการเรียก
  ฟังก์ชันพวกที่สองโดยไม่มี `startWrite()` เปิดไว้ พิสูจน์แล้วสองทาง
  คือรันกับคอมมิตที่เสียจริง จับได้ทั้งสองบรรทัด และลองครอบด้วย
  `startWrite()`/`endWrite()` ดู ตัวตรวจก็ไม่ฟ้องผิด

บั๊กชนิดนี้ร้ายเป็นพิเศษ เพราะ **คอมไพล์ผ่าน ไม่มีคำเตือน แต่ภาพไม่ขึ้นเงียบ ๆ**
ต่อไปจะถูกจับได้ตั้งแต่ก่อน commit

---

## แก้คอมไพล์ไม่ผ่าน และอุดช่องที่ตัวตรวจมองไม่เห็น (Host 113.6.0 / Station 122.6.1)

ท่านส่งข้อความจากคอมไพเลอร์มาว่า

```
StationScreen.h:393: error: 'drawStandbyReadyState' was not declared in this scope
```

ผมพลาดเองครับ ตอนแทรกฟังก์ชันใหม่ ผมวาง `drawStandbyReadyState()` ไว้ติดกับ
`displayTapCardStandby()` ที่บรรทัด 503 เพราะมันเป็นเรื่องเดียวกัน
แต่ลืมไปว่า `refreshStationLiveValues()` ที่บรรทัด 393 ก็เรียกใช้มันด้วย
ซึ่งอยู่ **เหนือ** จุดที่นิยามไว้ C++ อ่านจากบนลงล่าง จึงยังไม่รู้จักชื่อนี้

แก้โดย **ย้ายนิยามขึ้นไปไว้ใต้ `drawRfidTapIcon()` ทันที** ซึ่งอยู่เหนือทั้งสองจุดที่เรียก
เลือกย้ายแทนการเพิ่มบรรทัดประกาศล่วงหน้า เพราะสองฟังก์ชันนี้เป็นเรื่องเดียวกัน
คือรูปกับป้ายของมัน อยู่ติดกันแล้วอ่านง่ายกว่า และไม่ต้องดูแลสองที่

### เรื่องที่สำคัญกว่าตัวบั๊ก

บั๊กนี้ **ตัวตรวจทั้งหกตัวของผมปล่อยผ่านหมด** ทั้งที่มันเป็นบั๊กชนิดเดียวกับที่เคยเกิด
มาแล้วสองครั้งในโปรเจกต์นี้ สาเหตุคือ `splitcheck.py` ที่เขียนไว้ตอนนั้น
ดูแลเฉพาะ **รอยต่อระหว่าง `.ino` กับ `.h`** คือกรณีที่โค้ดใน `.ino` เรียกฟังก์ชันที่ย้ายไปอยู่ใน `.h`
มันจึงมองไม่เห็นกรณีที่ทั้งผู้เรียกและผู้ถูกเรียกอยู่ในไฟล์ `.h` เดียวกัน

เพิ่ม `tools/proto-check/ordercheck.py` เป็นตัวที่เจ็ด ตรวจกติกาเดียวกันแต่ทั่วถึงกว่า

* ไล่ทุกการเรียกฟังก์ชันในทุกไฟล์ แล้วเทียบกับบรรทัดที่นิยามไว้
* ถ้าถูกเรียกก่อนถูกนิยาม และไม่มีบรรทัดประกาศล่วงหน้าอยู่ข้างบน ถือว่าผิด
* มองเห็น `.ino` กับ `.h` ที่ถูก `#include` **เป็นไฟล์เดียวกันแบบที่คอมไพเลอร์เห็น**
  บรรทัดประกาศล่วงหน้าที่อยู่ใน `.ino` เหนือ `#include` จึงนับว่าใช้ได้
  รุ่นแรกของตัวตรวจที่ผมเขียนยังไม่ได้มองแบบนี้ จึงฟ้องผิดห้าจุดที่ไม่ได้ผิดจริง

พิสูจน์ว่าจับได้จริงสองทาง โดยรันกับสำเนาของคอมมิตที่ท่านคอมไพล์ไม่ผ่าน

```
บรรทัด 393 เรียก drawStandbyReadyState() ซึ่งนิยามอยู่บรรทัด 503
คือต่ำกว่าจุดที่เรียก และไม่มีบรรทัดประกาศล่วงหน้าอยู่ข้างบน
```

ตรงกับที่คอมไพเลอร์ฟ้องทั้งชื่อฟังก์ชันและเลขบรรทัด แล้วลองอีกทางหนึ่ง
คือลบบรรทัดประกาศล่วงหน้าของ `displayTapCardStandby()` ออกจาก `.ino`
ตัวตรวจก็จับได้เช่นกัน

**ขออภัยที่ต้องรบกวนท่านคอมไพล์ให้อีกรอบครับ** ตราบใดที่ผมยังเข้า
`downloads.arduino.cc` ไม่ได้ ท่านคือคนเดียวที่ยืนยันได้ว่าโค้ดคอมไพล์ผ่าน
สิ่งที่ผมทำได้คือทำให้ความผิดพลาดแต่ละแบบที่เกิดขึ้นจริง ถูกจับได้ตั้งแต่ก่อนส่งถึงมือท่าน

---

## คืนสัญลักษณ์แตะบัตรกลับมา และทำให้มันบอกความพร้อมจริง (Host 113.6.0 / Station 122.6.0)

ท่านทักว่า **"ฝั่ง Station ท่านได้ลบสัญลักษณ์ในการแตะบัตรไปไหม ผมยังต้องการสัญลักษณ์นั่นครับ
เพื่อผู้ใช้งานรู้ว่าเครื่องพร้อมให้บริการ"**

ถูกต้องครับ **หายไปจริง** สัญลักษณ์นี้เคยมีตั้งแต่รุ่น 118.1.0 แล้วหายไปตอนที่เริ่มใหม่
จากต้นฉบับในรุ่น 122.0.0 หน้าแรกจึงเหลือแต่ตัวหนังสือ นิสิตที่เดินมาถึงไม่มีอะไรบอกว่า
เครื่องพร้อมรับบัตรอยู่หรือเปล่า ผมเอาโค้ดเดิมกลับมาทั้งดุ้น

### แต่เอากลับมาเฉย ๆ ยังไม่ตอบโจทย์ที่ท่านบอก

ท่านบอกเหตุผลไว้ชัดว่าต้องการให้ **"ผู้ใช้งานรู้ว่าเครื่องพร้อมให้บริการ"**
ของเดิมเป็นรูปนิ่ง คลื่นเป็นสีเขียวตลอดเวลา ถ้าเครื่องอ่านบัตรค้างขึ้นมา
สัญลักษณ์ก็ยังเขียวอยู่ดี นิสิตแตะแล้วไม่มีอะไรเกิดขึ้น แล้วก็ยืนงงกันอยู่ตรงนั้น

ในโค้ดมี `checkRC522()` ที่อ่านทะเบียนรุ่นของ RC522 ทุกสิบวินาทีอยู่แล้ว
แต่ของเดิม **ถ้าอ่านไม่ได้ก็แค่สั่งเริ่มใหม่แล้วจบ** ไม่มีใครรู้ว่าสำเร็จหรือไม่
และไม่มีอะไรบนหน้าจอบอก ผมจึงต่อสองส่วนนี้เข้าด้วยกัน

* อ่านทะเบียนรุ่น **ซ้ำอีกครั้งหลังสั่งเริ่มใหม่** แล้วเก็บผลไว้ใน `isReaderReady`
* อ่านหนึ่งครั้งตอนบูตด้วย สัญลักษณ์จะได้ถูกต้องตั้งแต่วินาทีแรก ไม่ต้องรอรอบตรวจรอบแรก
* คลื่นของสัญลักษณ์ **เขียว = เครื่องอ่านตอบอยู่**, **แดง = ไม่ตอบ**
  และบรรทัดใต้ข้อความเปลี่ยนจาก `Free meal  35 baht  once a day`
  เป็น `Card reader not responding - call staff`

สัญลักษณ์จึงไม่ใช่ของประดับ แต่เป็นสิ่งที่เจ้าหน้าที่มองแวบเดียวก็รู้ว่าเครื่องไหนต้องไปดู

### จัดหน้าใหม่ให้มีที่ว่างพอ

การ์ดใบบนมีที่ว่างเหลืออยู่แล้วราว 36 พิกเซลด้านล่าง จัดใหม่เป็น

| ส่วน | ตำแหน่ง |
|---|---|
| สัญลักษณ์แตะบัตร | กึ่งกลางที่ (160, 72) กินพื้นที่ 72×47 พิกเซล |
| `TAP YOUR CARD` | y 100 สูง 32 |
| บรรทัดคำอธิบาย | y 139 |

บรรทัดคำอธิบายเปลี่ยนจาก `drawFitCenteredText()` เป็น `drawCenteredText()`
เพราะข้อความสองแบบยาวไม่เท่ากัน ตัวเดิมไม่ลบของเก่า สลับข้อความแล้วจะมีหางค้าง

### ตรวจแล้วว่าไม่กลับไปกะพริบ

จุดที่ผมระวังที่สุดคือสัญลักษณ์นี้วาดด้วยเส้นโค้ง ซึ่งวาดทับเส้นโค้งเดิมไม่มิด
สีเก่าจะค้างตามขอบเหมือนที่เคยเจอกับป้าย ONLINE/OFFLINE และแถบความคืบหน้า
จึงต้องล้างพื้นก่อน — แต่การล้างพื้นคือต้นเหตุของการกะพริบที่เพิ่งแก้ไป

ทางออกคือ **ล้างพื้นเฉพาะตอนสถานะเปลี่ยน** ซึ่งนาน ๆ ครั้ง ไม่ใช่ทุกวินาที
เพิ่มกรณีทดสอบสองกรณีใน `partial_test.js` คือตอนเครื่องอ่านล้ม และตอนกลับมาปกติ
ทั้งสองกรณี **ตรงกับการวาดใหม่ทั้งหน้าทุกพิกเซล ทั้งโหมดมืดและโหมดสว่าง**
ส่วนเส้นทางที่วาดทุกวินาที (นาฬิกา) ยังล้างพื้น **0 ครั้ง** เหมือนเดิม

ตัวตรวจคอมเมนต์ยังจับได้ด้วยว่าผมเผลอใช้คำว่า "คืนกลับ" ในป้ายเวอร์ชัน
ซึ่งไม่อยู่ในคำที่มาตรฐานอนุญาต (เพิ่ม/แก้/ย้าย) แก้เป็น "เพิ่ม" แล้ว

**ยังคอมไพล์ไม่ได้เหมือนเดิมครับ** รบกวนท่านแฟลชแล้วดูว่าคลื่นเขียวขึ้นถูกต้องไหม
และถ้าอยากลองกรณีแดง ให้ถอดสาย SDA ของ RC522 ออกสักสิบวินาที

---

## จอสาธารณะบนทีวีในโรงอาหาร (Host 113.6.0 / Station 122.5.0)

ท่านถามว่า **"เรายังคงมีการแสดงผลแบบไม่ต้องล็อกอินไหมครับ เพื่อไปเปิดบนหน้าจอทีวีจอใหญ่"**
คำตอบตอนนั้นคือ **ไม่มีแล้ว** — เฟิร์มแวร์รุ่นเก่ามีหน้านี้อยู่ แต่ตอนที่เขียนแดชบอร์ดใหม่
ในรุ่น 113.0.0 หน้านี้หายไป ทุกเส้นทางกลายเป็นต้องเข้าสู่ระบบหมด
ท่านจึงสั่งว่า **"เขียนใหม่ให้เข้าชุดกับหน้าเว็บปัจจุบัน"**

### หน้าใหม่

เปิดที่ `http://192.168.4.1/display` ไม่ต้องเข้าสู่ระบบ ปล่อยค้างเต็มจอได้ทั้งวัน
ใช้ชุดสี ตัวอักษร และรูปแบบการ์ดเดียวกับแดชบอร์ด แต่จัดวางใหม่ทั้งหมด
สำหรับคนที่ยืนอ่านจากอีกฝั่งของห้อง ไม่ใช่คนที่นั่งหน้าจอ

| ส่วน | เนื้อหา |
|---|---|
| แถบบน | ชื่อโรงอาหาร นาฬิกาเดินวินาที วันที่ และป้ายเปิด/ปิดบริการ |
| ตัวเลขสามช่อง | จ่ายไปกี่จาน เป็นเงินกี่บาท เหลืออีกกี่คน |
| ยอดขายรายร้าน | ชื่อร้าน จำนวนจาน จำนวนเงิน และแท่งเทียบสัดส่วน |
| รายการล่าสุด | แปดรายการหลังสุดที่ผ่านแล้ว |

ไทยกับอังกฤษขึ้นพร้อมกัน ไม่มีปุ่มสลับภาษา เพราะไม่มีใครเดินไปกดปุ่มบนจอทีวี
ขนาดตัวอักษรทุกจุดคิดจากหน่วย `vmin` จอ 1920×1080 กับ 1366×768
จึงได้สัดส่วนเดียวกันโดยไม่ต้องมีจุดตัด

### หน้านี้เปิดให้ทุกคนเห็น จึงต้องกันข้อมูลส่วนบุคคลตั้งแต่ต้นทาง

ของเดิมที่เคยมีในเฟิร์มแวร์รุ่นเก่านั้นดึงจาก API ตัวเดียวกับแดชบอร์ด
ซึ่งมีทั้งชื่อนิสิตและหมายเลขบัตร หน้าใหม่จึงไม่ได้ใช้ `/api/dashboard`
แต่มี `/api/board` เป็นของตัวเอง ที่ **ประกอบข้อมูลขึ้นมาใหม่เฉพาะที่ยอมให้เห็น**
ไม่ใช่การซ่อนด้วย CSS ที่กด View Source แล้วเห็น

* รหัสนิสิตถูกตัดเหลือห้าหลักแรกตั้งแต่ตอนบันทึกลงคิว ไม่ใช่ตอนส่งออก
  ตัวเต็มไม่เคยออกจากเครื่องทางเส้นทางนี้เลย
* ไม่มีชื่อ ไม่มีหมายเลขบัตร ไม่มีเลขอ้างอิง
* ไม่มีอุณหภูมิ หน่วยความจำ หรือ MAC ของเครื่องแม่ข่าย
* มีเฉพาะรายการที่ผ่าน รายการที่ถูกปฏิเสธหรือซ้ำไม่ขึ้นบนจอนี้

คิวเก็บแค่แปดรายการหลังสุดใน `PublicFeedItem` ซึ่งเป็นโครงสร้างแยกต่างหาก
ขนาดคงที่ มีแค่สามฟิลด์ คือรหัสที่ปิดบังแล้ว เวลา และเลขร้าน
โครงสร้างนี้ **ไม่มีที่ให้ใส่ชื่อหรือหมายเลขบัตรได้เลยแม้จะเผลอ** และถูกล้างพร้อมกับ
การปิดยอดประจำวันที่ `/reset`

### ตัวตรวจใหม่: `privacycheck.py`

ข้อกำหนดข้างบนจะอยู่ได้ไม่นานถ้าอาศัยความจำอย่างเดียว จึงเขียนตัวตรวจไว้ ทำสองอย่าง

1. อ่านตัวฟังก์ชัน `handlePublicBoard()` แล้วฟ้องถ้าพบการอ้างถึงฟิลด์ต้องห้าม
   ไม่ว่าจะเป็น `fullName` `uid` `refNo` หรือฟังก์ชันอ่านข้อมูลฮาร์ดแวร์
2. ไล่ `server.on()` ทุกบรรทัด แล้วฟ้องถ้ามีเส้นทางไหนที่ไม่ได้เรียก
   `isAuthenticated()` และไม่ได้อยู่ในรายการสาธารณะที่ประกาศไว้
   ใครเพิ่มเส้นทางใหม่แล้วลืมใส่การตรวจสิทธิ์จะถูกจับได้ทันที

ตอนรันครั้งแรกมันฟ้อง `/upload` ตรวจแล้วพบว่า **เป็นข้อบกพร่องของตัวตรวจเอง**
ไม่ใช่ช่องโหว่ — `/upload` ลงทะเบียนด้วยรูปแบบสี่อาร์กิวเมนต์
`server.on(path, method, handler, upload)` ซึ่งมีตัวจัดการสองตัว
ตัวตรวจรุ่นแรกจับได้เฉพาะตัวเดียวที่ตามด้วยวงเล็บปิด จึงมองไม่เห็นทั้งคู่
แก้ให้อ่านตัวจัดการทุกตัวแล้วบังคับว่า **ต้องตรวจสิทธิ์ทุกตัว** ซึ่งเข้มกว่าเดิม
ของจริงทั้ง `mergeImportedStudents()` และ `handleFileUpload()` ตรวจสิทธิ์อยู่แล้วทั้งคู่
และพิสูจน์ว่าตัวตรวจจับได้จริงโดยลองถอดการตรวจสิทธิ์ออกจากสำเนาแล้วรันซ้ำ

### ตรวจก่อนส่ง

ผมยังคอมไพล์ไม่ได้ (`downloads.arduino.cc` ตอบ 403 ผ่านพร็อกซี) จึงตรวจเท่าที่ทำได้

* ตัวตรวจทั้งหกตัวผ่านหมด
* ดึง `DISPLAY_HTML` ออกจาก `WebDashboard.h` กลับมาเทียบกับต้นฉบับ **ตรงกันทุกไบต์**
  8,560 ไบต์ แล้วเรนเดอร์จากไฟล์ที่ดึงออกมานั้น ไม่ใช่จากต้นฉบับ
* เรนเดอร์สี่กรณีด้วย Chromium จริง: 1920×1080, 1366×768, โหมดสว่าง
  และกรณียังไม่มีใครมารับ **ไม่มี error และไม่มีการล้นจอทั้งแนวตั้งและแนวนอน**
* ภาพทั้งสี่อยู่ใน `docs/interface/` และในหน้ารวมภาพแล้ว

**ยังต้องให้ท่านทดสอบบนเครื่องจริง** โดยเฉพาะว่าเบราว์เซอร์ของทีวีรุ่นที่ใช้
รองรับหน่วย `vmin` และ `fetch` หรือไม่ ถ้าเป็นทีวีรุ่นเก่ามากอาจต้องปรับ

---

## จัดตำแหน่งตัวอักษรบนจอให้ถูกต้อง (Host 113.5.0 / Station 122.5.0)

ท่านแจ้งว่าหลังแฟลชรุ่นก่อน **อักษรซ้อนหายไปแล้ว และการกะพริบดีขึ้น**
แต่บรรทัดสีเขียวบนหน้าพักจอไม่ได้อยู่กึ่งกลางเหมือนนาฬิกากับวันที่

สาเหตุคือตอนผมเลิกล้างพื้น ผมเปลี่ยนบรรทัดที่เคย **คำนวณกึ่งกลางเอง**
ให้เป็น `drawFixedText()` ซึ่งเติมช่องว่าง **ท้ายอย่างเดียว** ข้อความจึงชิดซ้าย
ของช่องเสมอ และเยื้องไปทางซ้ายเมื่อเทียบกับบรรทัดอื่น

### วิธีแก้

เพิ่ม `drawCenteredText()` ที่เติมช่องว่าง **ทั้งสองข้าง** ให้ช่องกว้างคงที่
ข้อความจึงอยู่กึ่งกลางจริง และช่องว่างก็ลบของเดิมที่ยาวกว่าไปพร้อมกัน
ยังไม่ต้องล้างพื้น จึงไม่กลับไปกะพริบอีก

### ตรวจหน้าอื่นแล้วแก้เพิ่มอีกสี่จุด

| หน้า | แก้อะไร |
|---|---|
| **หน้าพักจอ** ทั้งสองฝั่ง | นาฬิกา วันที่ ยอดวันนี้ และแบตเตอรี่ จัดกึ่งกลางที่ x = 160 เหมือนกันหมด |
| **หน้า TODAY** ของแม่ข่าย | วันที่กับช่วงเวลาให้บริการอยู่บรรทัดฐานเดียวกัน จากเดิมเหลื่อมกัน 4 พิกเซล |
| **หน้า 2 ของจุดบริการ** | คำว่า `baht` เคยอยู่ที่ตำแหน่งคงที่ทางขวาของตัวเลข พอตัวเลขสั้นก็เหลือช่องว่างกลางอากาศ ย้ายลงมาอยู่ใต้ตัวเลข ชิดซ้ายเหมือนบรรทัดอื่นในการ์ด |
| **หน้าแรกของจุดบริการ** | นาฬิกาเคยลอยอยู่ระหว่างหัวข้อกับตัวเลข ย้ายให้อยู่บรรทัดเดียวกับตัวเลขยอด |
| **หน้า SYSTEM ของจุดบริการ** | หกแถวกองอยู่ครึ่งบนของการ์ด เหลือที่ว่างข้างล่างเกือบหนึ่งในสี่ กระจายใหม่ให้เต็ม |

ส่วนหน้าอื่นที่ตรวจแล้วไม่ต้องแก้: หน้า SHOPS ของแม่ข่าย (คอลัมน์ป้ายกำกับตรงกันทั้งสี่การ์ด),
หน้า SYSTEM ของแม่ข่าย, หน้าแจ้งผลการแตะบัตร และหน้าแจ้งสถานะ Wi-Fi ตอนบูต
ซึ่งใช้การจัดกึ่งกลางของตัวเองอยู่แล้วและวาดครั้งเดียว

ตัวทดสอบเทียบภาพ 20 กรณียังผ่านครบ ทั้งเรื่องไม่มีเศษพิกเซลค้าง
และเรื่องไม่ล้างพื้นบนบรรทัดที่วาดทุกวินาที

## แก้อักษรซ้อนและภาษาไทยอ่านไม่ออกบนจอ TFT (Host 113.4.0 / Station 122.4.0)

สองอาการที่ท่านเจอมาจาก**ต้นเหตุเดียวกัน**

ฟอนต์ในตัวของ Adafruit GFX มีแต่ ASCII ไบต์ตั้งแต่ `0x80` ขึ้นไปถูกวาดเป็นสัญลักษณ์มั่ว
และ **ภาษาไทยหนึ่งตัวกินสามไบต์** จึงกลายเป็นตัวประหลาดสามตัว
ที่สำคัญกว่านั้นคือ **มันกินที่กว้างกว่าที่โค้ดนับไว้สามเท่า** ข้อความจึงล้นกรอบ
ไปทับของข้างเคียง นั่นคืออักษรซ้อนที่ท่านเห็น

### ต้นตอที่แท้จริง: ค่าเริ่มต้นในโค้ดเป็นภาษาไทย

```c
Shop shops[4] = {
  {"ร้านที่ 1", "นางสาวณัฐกฤตา สุพิทิพย์"},   // <-- ชื่อนี้ถูกส่งไปวาดบนจอตรง ๆ
```

จอจึงขึ้นมั่ว **ตั้งแต่ยังไม่ได้ตั้งค่าอะไรเลย** ไม่ต้องรอให้ใครพิมพ์ชื่อไทยเข้าไป
เป็นของที่ติดมาตั้งแต่ต้นฉบับ 107.0.1

### วิธีแก้ สามชั้น

**ชั้นที่หนึ่ง — ชื่อร้านมีช่องสำหรับจอโดยเฉพาะ**
เพิ่มช่องที่สามในแท็บ Shops บนหน้าเว็บ สำหรับตั้งชื่อสั้น ๆ ภาษาอังกฤษที่จะขึ้นบนจอ
ชื่อจริงภาษาไทยยังอยู่ครบ ใช้บนหน้าเว็บและในไฟล์รายงานเหมือนเดิม
ถ้าเว้นว่างไว้ จอจะถอยไปใช้ส่วนที่เป็น ASCII ของชื่อจริง แล้วถอยไปที่ `Shop 1` ถึง `Shop 4`

**ชั้นที่สอง — กรองทุกข้อความก่อนถึงจอ**
เพิ่ม `asciiOnly()` ทั้งสองฝั่ง ใช้กับทุกข้อความที่มาจากผู้ใช้หรือจากฐานข้อมูล
ทั้งชื่อร้าน ชื่อนิสิต และรหัสนิสิต **จอจะไม่มีวันได้รับข้อความที่ฟอนต์วาดไม่ได้อีก**

**ชั้นที่สาม — ทุกช่องตัดความยาวไม่ให้ล้น**
`drawFixedText()` เปลี่ยนจาก `%-*s` (เติมให้ครบแต่ยาวเกินได้) เป็น `%-*.*s`
(ตัดให้พอดีเสมอ) ต่อให้มีข้อความยาวผิดคาดหลุดมาได้ ก็ล้นไปทับช่องข้างเคียงไม่ได้
ทุกช่องถูกกำหนดความกว้างเผื่อไว้แล้วให้ค่าจริงยาวไม่ถึง

### เพิ่มตัวตรวจ `tools/proto-check/asciicheck.py`

ตรวจสองข้อในไฟล์ที่วาดจอ: สตริงในโค้ดต้องเป็น ASCII ล้วน
และตัวแปรที่มาจากผู้ใช้ต้องผ่าน `asciiOnly()` ก่อนวาด

ทดสอบด้วยการใส่บั๊กทั้งสองแบบกลับเข้าไปในไฟล์สำเนา ตัวตรวจชี้ได้ถูกทั้งคู่

### ข้อจำกัดที่ต้องบอกตรง ๆ

การกรองแบบนี้คือ **ตัดตัวอักษรไทยทิ้ง ไม่ใช่การแปลงเป็นอักษรโรมัน**
ถ้าอยากให้จอแสดงชื่อร้านเป็นไทยจริง ๆ ต้องฝังฟอนต์บิตแมปภาษาไทยเข้าไป
พร้อมเขียนตัวจัดวางสระและวรรณยุกต์เอง ซึ่งเป็นงานคนละขนาดและกินแฟลชเพิ่มมาก
ถ้าท่านต้องการจริง ๆ บอกได้ครับ

## แก้จอกะพริบทุกวินาที (Host 113.3.0 / Station 122.3.0)

รอบที่แล้วผมแก้ผิดจุด ไปลดจำนวนครั้งที่วาดซ้ำ ทั้งที่**ต้นเหตุไม่ใช่การวาดบ่อย
แต่เป็นวิธีวาด** โค้ดเดิมทำตามลำดับ "ล้างพื้นด้วย `fillRect` แล้วค่อยเขียนตัวอักษร"
ระหว่างสองจังหวะนั้นจอว่างเปล่าจริง ๆ ตาคนจึงเห็นเป็นการกะพริบ
และเพราะนาฬิกาเดินทุกวินาที จอจึงกะพริบทุกวินาที

### วิธีแก้ที่ถูกต้อง

Adafruit GFX ลงสีพื้นให้ทุกตัวอักษรอยู่แล้วเมื่อกำหนดสีพื้นไว้ด้วย
(`setTextColor` แบบสองอาร์กิวเมนต์) ข้อความใหม่จึงเขียนทับของเดิมได้ในจังหวะเดียว
**ไม่ต้องล้างพื้นเลย** ไม่มีช่วงที่จอว่าง จึงไม่มีอะไรให้เห็นเป็นการกะพริบ

เงื่อนไขเดียวคือความยาวต้องคงที่ จึงเพิ่ม `drawFixedText()` ไว้ทั้งสองฝั่ง
ซึ่งเติมช่องว่างท้ายข้อความให้ครบความกว้างที่กำหนดเสมอ ไม่งั้นตัวอักษรเก่าที่ยาวกว่า
จะค้างอยู่ เช่น 187 เปลี่ยนเป็น 9 แล้วเหลือ 87 ค้างจอ

ใช้ `%-*s` ซึ่งเติมให้ครบแต่**ไม่ตัดทิ้ง** ค่าที่ยาวเกินคาดจึงยังแสดงครบ ไม่โกหกตัวเลข

### จุดที่แก้

| ที่ | เดิม |
|---|---|
| จอแม่ข่าย หน้า TODAY | ล้างพื้นนาฬิกา 196×34 ทุกวินาที |
| จอแม่ข่าย หน้า SHOPS | ล้างแถวสถานะกับแถวสัญญาณของทั้งสี่การ์ดทุกวินาที แม้ค่าไม่เปลี่ยน |
| จอแม่ข่าย หน้า SYSTEM | ล้างแถวอุณหภูมิและหน่วยความจำทุกครั้งที่ค่าขยับ |
| จอแม่ข่าย หน้าพักจอ | ล้างพื้นนาฬิกาตัวโต 260×52 ทุกวินาที |
| จอจุดบริการ ทุกหน้า | ล้างพื้นก่อนเขียนทุกจุด |
| จอจุดบริการ หน้า SYSTEM | อัปเดตทุกครึ่งวินาที จึงกะพริบถี่ที่สุด |
| จอจุดบริการ แถบบนขวา | เทียบด้วยค่า dBm ดิบซึ่งแกว่งเกินสามหน่วยแทบทุกวินาที แถบบนจึงถูกล้างแล้ววาดใหม่ตลอด ตอนนี้เทียบด้วยจำนวนขีดแทน |

### ตัวทดสอบจับได้อีกหนึ่งบั๊ก

**แถบความคืบหน้าเป็นสี่เหลี่ยมมุมโค้ง `fillRoundRect` จึงไม่ลงสีที่มุมทั้งสี่**
เวลายอดลดลง สีเขียวของค่าเก่าจะค้างอยู่ที่มุม แก้ด้วยการล้างกรอบสี่เหลี่ยมเต็มก่อน
หนึ่งครั้ง ซึ่งทำได้เพราะแถบนี้วาดเฉพาะตอนยอดเปลี่ยน ไม่ได้วาดทุกวินาที

### ตัวทดสอบเข้มขึ้น

`run_partial.mjs` เพิ่มการ **นับจำนวนครั้งที่ล้างพื้นระหว่างวาดซ้ำ**
กรณีที่วาดทุกวินาที (นาฬิกาทั้งสามหน้า) ต้องได้ศูนย์ครั้ง ไม่งั้นถือว่าสอบตก
เพราะถ้ายังมีการล้างพื้นอยู่ ก็คือยังกะพริบอยู่

ผ่านครบ 18 กรณี ทั้งเรื่องพิกเซลตรงกันและเรื่องไม่ล้างพื้น

### แก้ตัวจำลองให้ตรงกับจอจริงด้วย

ตัวจำลองใช้ฟอนต์ของระบบซึ่งมีหางตัวอักษรล้นออกนอกเซลล์ได้ ต่างจากฟอนต์ในตัว
ของ Adafruit GFX ที่อยู่ในกรอบเซลล์เสมอ ทำให้ตัวทดสอบรายงานความต่างปลอม ๆ
สองพิกเซล ตอนนี้ตัดขอบตัวอักษรให้เท่าเซลล์แล้ว

## ซ่อมการรีเฟรชตัวเลขบนจอทั้งสองฝั่ง (Host 113.2.0 / Station 122.2.0)

ท่านให้ตรวจว่าจอรีเฟรชเมื่อตัวเลขเปลี่ยนหรือไม่ ตรวจแล้ว **พบว่าหลายจุดไม่รีเฟรช**
บางจุดเป็นของเดิม บางจุดผมทำพังเองตอนออกแบบหน้าจอใหม่ สรุปตามตาราง

| จุด | อาการเดิม | ใครทำ |
|---|---|---|
| จอแม่ข่าย หน้า **SHOPS** | ยอดรายร้านวาดเฉพาะตอนวาดใหม่ทั้งจอ มีคนมารับอาหารแล้วตัวเลขไม่ขยับ | ผมเอง ตอนออกแบบใหม่ |
| จอแม่ข่าย หน้า **SYSTEM** | ไม่เคยรีเฟรชเลย เพราะ loop() รีเฟรชแค่หน้า 1 กับ 2 อุณหภูมิและหน่วยความจำจึงค้าง | ของเดิม แต่ผมย้ายค่าที่ต้องขยับมาไว้หน้านี้พอดี |
| จอแม่ข่าย หน้าพักจอ | ยอดวันนี้วาดครั้งเดียวตอนเข้าโหมด | ของเดิม |
| จอจุดบริการ หน้า 2 | โค้ดอัปเดตยอดใน loop() ใช้พิกัดและขนาดตัวอักษรของหน้าจอชุดเก่า วาดผิดที่และทับของเดิมไม่มิด | ผมเอง ตอนออกแบบใหม่ |
| จอจุดบริการ หน้า 1 และ 2 | นาฬิกาค้าง ไม่เดิน และสถานะออนไลน์/ออฟไลน์ไม่ขยับจนกว่าจะกดเปลี่ยนหน้า | ของเดิม |
| จอจุดบริการ แถบสัญญาณมุมขวาบน | `updateTopRightHeaderSmooth()` เขียนไว้ครบแต่**ไม่เคยถูกเรียกเลย** แถบสัญญาณจึงไม่เคยขึ้น | ของเดิมตั้งแต่ 117.0.7 |

### วิธีแก้

ทุกจอเปลี่ยนมาใช้หลักเดียวกัน คือ **เทียบค่ากับที่วาดไว้ครั้งก่อน แล้ววาดซ้ำเฉพาะช่องที่เปลี่ยนจริง**
ไม่ล้างแล้ววาดใหม่ทั้งการ์ดทุกวินาที จอจึงไม่กะพริบและตัวเลขก็ไม่ค้าง

- ฝั่งแม่ข่าย `renderHostPage()` เก็บค่าที่วาดไว้ครั้งก่อนของทุกช่อง และ loop()
  รีเฟรช **ทุกหน้า** ทุกหนึ่งวินาที ไม่ใช่แค่สองหน้าแรก
- ฝั่งจุดบริการ เพิ่ม `refreshStationLiveValues()` ไว้ใน `StationScreen.h`
  **อยู่ข้างเดียวกับโค้ดที่วาดหน้านั้นจริง** พิกัดจึงแก้พร้อมกันเสมอ
  ต้นเหตุของบั๊กเดิมคือพิกัดถูกเขียนไว้สองที่แล้วหลุดจากกัน
- แถบสัญญาณถูกต่อสายเข้ากับรอบรีเฟรชแล้ว และมีการ์ดกันไม่ให้ไปวาดทับ
  หน้าแจ้งผลการแตะบัตรซึ่งยึดพื้นที่ทั้งจอ

### เพิ่มตัวทดสอบว่าการวาดบางส่วนไม่ทิ้งเศษพิกเซล

การวาดเฉพาะบางช่องมีกับดักคือ **ถ้าช่องที่ล้างเล็กกว่าของเดิม จะเหลือเศษค้างบนจอ**
เช่น 187 เปลี่ยนเป็น 9 แล้วเลข 87 ยังอยู่

`tools/screen-preview/run_partial.mjs` ทดสอบให้อัตโนมัติ โดยเทียบภาพที่ได้จาก
การวาดใหม่ทั้งหน้า กับการวาดค่าเก่าแล้วแก้เฉพาะช่อง **สองภาพต้องตรงกันทุกพิกเซล**
ทดสอบ 9 กรณี คูณสองโหมดสี รวม 18 กรณี

ตัวทดสอบจับบั๊กจริงได้ทันทีหนึ่งตัว: เปลี่ยนป้าย ONLINE เป็น OFFLINE แล้ว
**สีเขียวค้างอยู่ที่มุมโค้งทั้งสี่ของป้าย** เพราะ `fillRoundRect` ไม่ได้ลงสีที่มุม
การวาดป้ายใหม่ทับจึงไม่ลบมุมเดิม ต้องล้างกรอบสี่เหลี่ยมเต็มก่อน
แก้แล้วและตอนนี้ผ่านครบทั้ง 18 กรณี

### ข้อจำกัดที่ต้องบอกตรง ๆ

ตัวจำลองใน `tools/screen-preview/` เป็น**สำเนาที่เขียนตามโค้ดเฟิร์มแวร์ ไม่ใช่ตัวเฟิร์มแวร์เอง**
พิสูจน์ได้แค่เรื่องเรขาคณิตของการวาด ไม่ได้พิสูจน์ว่าโค้ดบนบอร์ดจริงทำงานถูก
**ยังต้องรบกวนท่านทดสอบบนเครื่องจริง** โดยเฉพาะข้อที่ว่านาฬิกาเดินจริงไหม
และยอดขยับทันทีเมื่อมีคนแตะบัตร

## วางมาตรฐานคอมเมนต์และบังคับใช้ด้วยตัวตรวจ (เอกสารและคอมเมนต์ ไม่แตะตรรกะ)

ท่านขอให้คอมเมนต์เป็นมาตรฐานสากล อ้างอิงเลขเวอร์ชันได้ และบอกได้ว่า
โค้ดชุดหนึ่งเพิ่มอะไรเข้าไปบ้าง จึงวางไว้เป็นสองชั้น

### ชั้นที่หนึ่ง — หัวไฟล์แบบ Doxygen

ทุกไฟล์ `.ino` และ `.h` ขึ้นต้นด้วยบล็อกเดียวกัน มี `@file` `@brief` `@version`
`@date` `@author` พร้อม **ตาราง Revision History** ที่บอกว่าแต่ละรุ่นเปลี่ยนอะไร
ในไฟล์นั้น และ `@warning` สำหรับเรื่องที่ไม่รู้แล้วจะพัง เช่นเรื่องบัส SPI ของจอ
กับเครื่องอ่านบัตร หรือเรื่อง Partition Scheme ที่เลือกผิดแล้วฐานข้อมูลหาย

ใช้แท็กจริงของ Doxygen ทั้งหมด ไม่ได้คิดขึ้นเอง ถ้าวันหนึ่งอยากสร้างเอกสาร
อัตโนมัติจากโค้ด ก็รัน Doxygen ได้เลยโดยไม่ต้องแก้อะไร

หัวไฟล์เดิมของทั้งสองสเก็ตช์ยังเขียนว่าเวอร์ชัน 107.0.1 กับ 117.0.7 อยู่
ทั้งที่ `APP_VERSION` เดินไปถึง 113.1.0 กับ 122.1.0 แล้ว ซึ่งเป็นปัญหาที่
มาตรฐานนี้ตั้งใจแก้พอดี

### ชั้นที่สอง — ป้ายบอกเวอร์ชันในเนื้อโค้ด

หัวไฟล์บอกภาพรวม แต่ไม่ได้บอกว่าบรรทัดไหนมาจากรุ่นไหน จึงปักป้ายไว้เหนือจุดที่
เพิ่มหรือแก้จริง รูปแบบ `// [113.0.0] เพิ่ม: คำอธิบาย` โดยคำกริยาใช้ได้สามคำ
คือ เพิ่ม / แก้ / ย้าย

ปักไว้ 19 จุด เฉพาะที่ยืนยันได้จากประวัติการแก้ไขจริง **ไม่ได้เดา** และไม่ปักกับ
การแก้เล็ก ๆ ที่อ่านโค้ดแล้วเข้าใจได้เอง เพราะป้ายที่เยอะเกินไปจะกลายเป็นขยะ

### บังคับใช้ด้วย `tools/proto-check/headercheck.py`

ตรวจห้าข้อ: แท็กบังคับครบ · `@file` ตรงชื่อไฟล์จริง · `@version` สอดคล้องกับ
`APP_VERSION` · `@date` เป็นรูปแบบ `YYYY-MM-DD` · และป้ายในโค้ดอ้างเลขที่มีอยู่จริง
ในตารางของไฟล์นั้น พร้อมใช้คำกริยาตามมาตรฐาน

ทดสอบด้วยการใส่บั๊กห้าแบบกลับเข้าไปในไฟล์สำเนา ตัวตรวจชี้ได้ครบทั้งห้า

**เรื่องที่ตัวตรวจสอนผมระหว่างทาง** รอบแรกผมตั้งกติกาว่า `@version` ของทุกไฟล์
ต้องเท่ากับ `APP_VERSION` ตัวตรวจจึงฟ้อง `HostScreen.h` ทันที เพราะรุ่น 113.1.0
แก้แค่หน้าเว็บ ไม่ได้แตะไฟล์วาดจอเลย ถ้าไล่ขยับเลขให้เท่ากันหมดตารางจะโกหกว่า
ไฟล์นั้นถูกแก้ทั้งที่ไม่ได้แก้ จึงเปลี่ยนกติกาเป็น `@version` ของไฟล์ `.h` คือ
**เวอร์ชันที่ไฟล์นั้นถูกแก้ครั้งล่าสุด** และต้องไม่ใหม่กว่า `APP_VERSION`

รายละเอียดทั้งหมดอยู่ใน [`docs/CODE-STANDARD.md`](docs/CODE-STANDARD.md)

## แยกส่วนวาดจอของฝั่งจุดบริการออกมา (Station 122.1.0)

ทำแบบเดียวกับฝั่งแม่ข่าย ย้ายฟังก์ชันที่วาดลงจอ TFT ทั้ง 25 ตัวไปไว้ที่
`StationScreen.h` **ย้ายแบบยกก้อนทั้งดุ้น ไม่แก้เนื้อในแม้แต่ตัวอักษรเดียว**
หน้าจอจึงแสดงผลเหมือนเดิมทุกพิกเซล

| ไฟล์ | ก่อน | หลัง |
|---|---|---|
| `Canteen_Station_Client.ino` | 1,775 บรรทัด | **1,141 บรรทัด** |
| `StationScreen.h` | — | 707 บรรทัด |

สิ่งที่ย้ายไป: ชิ้นส่วนพื้นฐาน (การ์ด ป้าย แถบบน แถบล่าง การย่อตัวอักษรให้พอดีกรอบ),
แถบสัญญาณมุมขวาบน, การเปิด-ปิดไฟส่องหลังจอ และหน้าจอเต็มทั้งหมด
สิ่งที่อยู่ในไฟล์หลักเหมือนเดิม: ESP-NOW, การอ่านบัตร, ปุ่มกด, เสียง, ไฟ LED,
การตั้งหมายเลขจุดบริการ และการรับคำสั่งโหมดการแสดงผลจากแม่ข่าย

ตรวจว่าไม่มีอะไรหล่นหายด้วยการนับบรรทัดโค้ดทุกบรรทัดก่อนและหลังย้าย
ผลคือเท่ากันเป๊ะ ไม่มีบรรทัดไหนหายและไม่มีบรรทัดไหนงอกขึ้นมา

### เจอจุดที่จะคอมไพล์ไม่ผ่าน และแก้แล้วสองจุด

1. `drawStationIdConfigProgress()` ถูกเรียกจากไฟล์หลักแต่ไม่มีการประกาศล่วงหน้า
   พอนิยามย้ายไปอยู่ในไฟล์ที่ `#include` ทีหลัง จะขึ้น error แบบเดียวกับที่เคยเจอ
2. `updateTopRightHeaderSmooth()` มีค่าปริยาย `= false` อยู่ที่ตัวนิยาม
   ซึ่งเดิมอยู่ก่อนจุดที่มีคนเรียก พอย้ายไปอยู่ทีหลังจะพังทันที
   ย้ายค่าปริยายไปไว้ที่การประกาศล่วงหน้าแทน

### เพิ่มเครื่องมือ `tools/proto-check/splitcheck.py`

ตรวจปัญหาสองแบบข้างบนให้อัตโนมัติ สำหรับทุกไฟล์ `.h` ที่สเก็ตช์ `#include` ไว้
ทดสอบแล้วด้วยการใส่บั๊กทั้งสองแบบกลับเข้าไปในไฟล์สำเนา ตัวตรวจชี้ได้ถูกทั้งคู่

ตัวตรวจลอกสตริงและคอมเมนต์ออกก่อนเสมอ โค้ด JavaScript ที่ฝังอยู่ใน `WebDashboard.h`
จึงไม่ถูกเข้าใจผิดว่าเป็นฟังก์ชันของ C++ และฟังก์ชันที่ใช้อยู่ภายในไฟล์ `.h` เองเท่านั้น
ก็ไม่ถูกเตือน เพราะไม่จำเป็นต้องประกาศล่วงหน้า

## หน้าเว็บกลับมาเป็นสองภาษา ไทย/อังกฤษ (Host 113.1.0)

ตามที่ท่านขอให้เอาระบบสองภาษากลับมา ทำเฉพาะฝั่งหน้าเว็บ ฝั่งจอ TFT ยังเป็นอังกฤษ
เพราะฟอนต์ในตัวไลบรารี Adafruit GFX ไม่มีตัวอักษรไทย

**วิธีทำต่างจากของเดิม** เฟิร์มแวร์รุ่นเก่าเขียนข้อความซ้ำสองชุดในทุกบรรทัด
ด้วยแอตทริบิวต์ `data-th` กับ `data-en` ซึ่งทำให้หน้าเว็บโตและแก้ยาก
รุ่นนี้เขียนข้อความอังกฤษไว้ใน HTML ตามปกติแล้วติดป้าย `data-i="คีย์"`
ส่วนคำไทยอยู่ในพจนานุกรมชุดเดียวที่หัวของ `DASH_JS` เพิ่มข้อความใหม่ทีหลัง
จึงแก้แค่สองที่ และถ้าลืมเติมคำแปล หน้าเว็บจะแสดงอังกฤษไว้ก่อน ไม่พัง

- แปลครบ 63 จุด ทั้งแท็บ หัวตาราง ปุ่มในแถว ป้ายสถานะ ตัวเลือกในดรอปดาวน์
  ข้อความช่วยเหลือ ข้อความแจ้งผล และกล่องถามยืนยันก่อนลบ
- หน้าเข้าสู่ระบบสลับได้ด้วย มีคำแปลชุดย่อของตัวเองห้าคำ ไม่ต้องโหลด `/a.js`
- ค่าเริ่มต้นเป็นอังกฤษ และเบราว์เซอร์จำค่าที่เลือกไว้
- `/a.js` ส่งพร้อม `charset=utf-8` แล้ว เพราะในไฟล์มีคำแปลภาษาไทย
- กินแฟลชเพิ่มราว 8 KB (สคริปต์โตจาก 8.5 KB เป็น 16.6 KB)

### เพิ่มตัวตรวจคำพูดไม่ครบคู่

ระหว่างทำงานนี้ผมแก้ข้อความ HTML ที่ฝังอยู่ในสตริง C++ แล้ว**ลบเครื่องหมายคำพูด
เปิดทิ้งไปสองบรรทัด** ซึ่งคอมไพล์ไม่ผ่านแน่นอน แต่ตัวนับปีกกาเดิมมองไม่เห็น
เพราะปีกกายังครบทุกตัว จับได้ตอนเรนเดอร์ทดสอบเท่านั้น

`tools/proto-check/bracecheck.py` จึงเพิ่มการตรวจว่ามีสตริงไหนเปิดแล้วไม่ปิด
ภายในบรรทัดเดียวกันหรือไม่ ทดสอบแล้วด้วยการใส่บั๊กเดิมกลับเข้าไปในไฟล์สำเนา
ตัวตรวจชี้บรรทัดที่ผิดได้ถูกต้อง

## เริ่มใหม่จากต้นฉบับ แล้วรื้ออินเตอร์เฟสทั้งหมด (Host 113.0.0 / Station 122.0.0)

รุ่นนี้ **ไม่ได้ต่อยอดจากสายเดิม** แต่กลับไปเริ่มจากไฟล์ต้นฉบับ 107.0.1 และ 117.0.7
ตามที่ท่านเลือก แล้วค่อย ๆ ใส่ของที่จำเป็นกลับเข้าไปทีละอย่าง เพื่อให้แน่ใจว่า
ไม่มีของที่ผมเติมเข้าไปโดยไม่ได้ทดสอบหลงเหลืออยู่

### หนึ่ง — แยกไฟล์ให้ไฟล์หลักสั้นลง

ไฟล์เดียวสามพันบรรทัดทำให้คนที่มารับช่วงดูแลต่อหาของไม่เจอ ตอนนี้แยกเป็น

| ไฟล์ | เนื้อหา |
|---|---|
| `Canteen_Host_Server.ino` | ตรรกะระบบ ฐานข้อมูล ESP-NOW เส้นทางเว็บ |
| `WebDashboard.h` | หน้าเว็บทั้งหมด |
| `HostScreen.h` | ทุกอย่างที่วาดลงจอ TFT |

ทั้งสองไฟล์ถูก `#include` ไว้ท้ายไฟล์หลักก่อน `setup()` **ห้ามย้ายขึ้นไปบนสุด**
เพราะโค้ดข้างในอ้างถึงตัวแปรส่วนกลางที่ประกาศไว้ข้างบน

### สอง — อินเตอร์เฟสใหม่ ภาษาอังกฤษทั้งหมด สองโหมด

ทั้งเว็บและจอ TFT ถูกออกแบบใหม่ตามที่ท่านสั่ง: เรียบง่าย แบ่งช่องชัดเจน
ตัวอักษรน้อย และ **เป็นภาษาอังกฤษทั้งหมด** เพราะนิสิตส่วนใหญ่เป็นชาวต่างชาติ
ส่วนคำอธิบายในโค้ดยังเป็นภาษาไทยไว้ให้คนดูแลระบบอ่าน

หน้าเว็บมีสี่แท็บ Today / Students / Shops / Settings แทนเมนูซ้อนแบบเดิม
หน้าแรกคือสิ่งที่เจ้าของร้านอยากรู้: ขายได้กี่จาน เป็นเงินเท่าไร เทียบกับร้านอื่น
ข้อมูลเชิงเทคนิคอย่างอุณหภูมิชิปกับโหลดซีพียูย้ายไปอยู่หน้า SYSTEM ของจอ TFT

จอแม่ข่ายเหลือสามหน้า TODAY / SHOPS / SYSTEM
จอจุดบริการหน้าแรกมีประโยคเดียวที่นิสิตต้องอ่านคือ TAP YOUR CARD

### สาม — เครื่องแม่ข่ายเป็นผู้กำหนดการแสดงผลของทุกจุดบริการ

โหมดมืด/สว่าง และการพักหน้าจอ ถูกสั่งจากแม่ข่ายที่เดียว ผ่านหน้าเว็บหรือปุ่มบนเครื่อง
ปุ่มสลับธีมที่ตัวจุดบริการถูกถอดออก เพราะถ้าแต่ละจุดตั้งเองได้ จอในโรงอาหาร
จะไม่เหมือนกันและไม่มีใครรู้ว่าใครไปกดอะไรไว้

### สี่ — ประสิทธิภาพ

- CSS กับ JavaScript ของหน้าเว็บย้ายไปอยู่ในแฟลช (`PROGMEM`) เสิร์ฟแยกที่
  `/s.css` และ `/a.js` ไม่ต้องต่อสตริงสองหมื่นตัวอักษรในแรมทุกครั้งที่เปิดหน้า
  และเบราว์เซอร์แคชไว้ได้ หน้าเว็บจึงเปิดเร็วขึ้นมากตั้งแต่ครั้งที่สองเป็นต้นไป
- ตัวเลขสดบนหน้าเว็บมาจาก `/api/dashboard` ทุกสองวินาที ไม่ต้องรีโหลดทั้งหน้า
- รายชื่อนิสิตเลิกใช้ `DynamicJsonDocument` ขนาดคงที่ 8 กิโล ซึ่งพอดีเกินไป
  สำหรับยี่สิบรายชื่อ ถ้าล้นขึ้นมา JSON จะขาดกลางคันแบบเงียบ ๆ ไม่มีใครรู้

### ห้า — ของเดิมที่ผิดอยู่ และแก้ในรุ่นนี้

| อาการ | สาเหตุ |
|---|---|
| เลขอ้างอิงบนจอไม่ตรงกับที่บันทึกไว้ | สร้างเลขใหม่ทุกครั้งที่วาดจอ ตัวนับจึงเดินเรื่อย ๆ |
| หน้าตรวจสอบระบบฝั่งสถานี มีหัวข้อแต่ไม่มีค่า | แถวแบตเตอรี่กับยอดวันนี้ไม่เคยถูกวาดค่าลงไป |
| ชื่อร้านบนจอแม่ข่ายหายไปครึ่งหนึ่ง | ช่องล้างพื้นที่ของจุดสถานะวาดทับตัวอักษร |
| ไฟล์ CSV คอลัมน์เลื่อนทั้งแถว | ชื่อที่มีเครื่องหมายคำพูดไม่ถูกครอบให้ถูกแบบ |
| โทเคนเข้าสู่ระบบเดาได้ | `random()` ของ Arduino ให้ลำดับเดิมทุกครั้งที่เปิดเครื่อง เปลี่ยนไปใช้ตัวสุ่มในตัวชิป |
| ลิงก์เดียวลบข้อมูลได้ | เส้นทางที่เปลี่ยนแปลงข้อมูลเปลี่ยนจาก GET เป็น POST ทั้งหมด |
| ดาวน์โหลดไฟล์ไหนก็ได้ในเครื่อง | ชื่อไฟล์แบบ `../` ผ่านเข้าไปได้ ตอนนี้รับเฉพาะ `arc_*` ในรากเท่านั้น |

### ข้อจำกัดที่ต้องบอกตรง ๆ

ผมยังคอมไพล์จริงไม่ได้ในที่นี้ (`downloads.arduino.cc` ถูกบล็อกที่พร็อกซี)
สิ่งที่ผมทำได้คือตรวจวงเล็บ ตรวจการประกาศฟังก์ชันล่วงหน้า ตรวจไวยากรณ์ JavaScript
ที่ฝังอยู่จริง และเรนเดอร์ทุกหน้าจอด้วยตัวจำลองเพื่อดูว่าตัวอักษรไม่ล้นกรอบ
**การคอมไพล์และทดสอบบนเครื่องจริงต้องรบกวนท่านเป็นคนทำ**

## แก้ปัญหาชื่อ Wi-Fi ไม่โผล่มา (Host 112.0.0 / Station 121.0.0)

อาการ: แฟลชเสร็จแล้วแต่ไม่มีชื่อ `MCU_CANTEEN_HOST` ขึ้นมาให้เลือกบนโทรศัพท์
ไล่ดูลำดับการเปิด Wi-Fi แล้วพบสาเหตุที่เป็นไปได้สองข้อ **ซึ่งเป็นความผิดพลาดของผมเองทั้งคู่**

**1. `WIFI_PROTOCOL_LR` บน SoftAP**

ตอนทำเรื่องความทนทานของลิงก์ (รุ่น `release/05`) ผมใส่ `WIFI_PROTOCOL_LR` ลงไปใน
bitmap ของ SoftAP พร้อมเขียนคอมเมนต์การันตีไว้ว่า *"การใส่เพิ่มเฉย ๆ ปลอดภัยเพราะยังคง
11b/g/n ไว้ โทรศัพท์และคอมพิวเตอร์จึงต่อ Wi-Fi ได้ตามปกติ"* — **ผมไม่เคยทดสอบข้อนี้เลย**
ความจริงคือ LR เป็นโหมดเฉพาะของ Espressif และทำให้อุปกรณ์ทั่วไปหลายรุ่น
**มองไม่เห็นชื่อ Wi-Fi** ทั้งที่เครื่องปล่อยสัญญาณอยู่

ตอนนี้ใส่สวิตช์ `ENABLE_WIFI_LONG_RANGE` ไว้ทั้งสองฝั่ง **ค่าเริ่มต้นคือปิด**
ประโยชน์จริงของ LR มาจากการบังคับอัตราส่ง (`ESPNOW_FORCE_LONG_RANGE_RATE`)
ซึ่งปิดอยู่แล้ว การใส่ LR ลง bitmap เฉย ๆ จึงแทบไม่ช่วยอะไรแต่เสี่ยงมาก

**2. `printerBegin()` ถูกเรียกก่อนเปิด Wi-Fi**

ผมเขียนคอมเมนต์ไว้ว่า *"เริ่มสแต็กเครื่องพิมพ์ก่อนเปิด Wi-Fi เผื่อฝั่ง USB host
ต้องใช้เวลาจับอุปกรณ์"* ซึ่งเป็นเหตุผลที่ผิด ไม่มีอะไรในเครื่องพิมพ์ที่ต้องมาก่อน Wi-Fi
แต่ถ้า `usb_host_install()` ค้างหรือแพนิก (เกิดง่ายมากเมื่อยังไม่ได้จ่ายไฟ 5V เข้าขา VBUS)
จะไม่มีชื่อ Wi-Fi โผล่มาเลยและเข้าไปแก้อะไรไม่ได้ทั้งสิ้น
ย้ายไปเรียก **หลัง** `server.begin()` แล้ว

**สิ่งที่เพิ่มเพื่อให้วินิจฉัยได้เองในสนาม**

- ลองเรียก `WiFi.softAP()` ซ้ำได้ถึงสามครั้ง และเก็บผลไว้ในตัวแปร `apStarted`
- **จอแจ้งสถานะเครือข่ายตอนบูต** แสดงชื่อ Wi-Fi รหัสผ่าน หมายเลขเครื่อง ช่องสัญญาณ
  และเลขเวอร์ชันคาตา ถ้าเปิด AP ไม่สำเร็จจะขึ้นแถบแดงพร้อมเสียงเตือนต่ำสองครั้ง
  เครื่องนี้ไม่ได้เปิด Serial ไว้ จอจึงเป็นช่องทางเดียวที่บอกได้
- เพิ่มหัวข้อ **แก้ปัญหาที่พบบ่อย** ใน README

## แยกไฟล์หลักให้ไม่เกิน 3,000 บรรทัด (Host 111.1.0)

ไฟล์หลักโตขึ้นเป็น 3,502 บรรทัด เกินเกณฑ์ที่โครงการนี้ถือปฏิบัติไว้ว่าไม่ควรเกิน 3,000
แยกออกเป็นสองไฟล์ใหม่ เหลือไฟล์หลัก **2,674 บรรทัด**

| ไฟล์ใหม่ | เนื้อหา | บรรทัด |
|---|---|---|
| `HostDisplay.h` | ทุกอย่างที่วาดลงจอ TFT ตั้งแต่ชิ้นส่วนการ์ด/แถบ ไปจนถึงสามหน้าหลัก โหมดพักจอ ผลการสแกน และหน้าเครดิต | 608 |
| `HostSlips.h` | เนื้อหาสลิปเครื่องพิมพ์และปลายทาง API ทั้งสี่ (ทั้งก้อนอยู่ใต้ `#if ENABLE_THERMAL_PRINTER` ตามเดิม) | 270 |

**เป็นการย้ายที่อยู่ล้วน ๆ ไม่ได้แก้ตรรกะแม้แต่บรรทัดเดียว** ตรวจยืนยันด้วยการเทียบ
เนื้อในของฟังก์ชันทั้ง 107 ตัวกับคอมมิตก่อนหน้าแบบไบต์ต่อไบต์ — ไม่มีตัวไหนหายและ
ไม่มีตัวไหนเนื้อในเปลี่ยน ตรวจเพิ่มว่าไม่มีฟังก์ชันที่ย้ายออกไปถูกเรียกก่อนจุด `#include`
โดยไม่มี forward declaration

> **หมายเหตุสำคัญ** การแยกไฟล์ **ไม่ได้ทำให้เฟิร์มแวร์เล็กลงเลย** โค้ดปริมาณเท่าเดิม
> คอมไพล์ออกมาได้จำนวนไบต์เท่าเดิมเป๊ะ ทำเพื่อให้อ่านง่ายและดูแลต่อได้เท่านั้น
> เรื่อง `Sketch too big` ยังต้องแก้ด้วยการตั้ง Partition Scheme เป็น
> *Huge APP (3MB No OTA/1MB SPIFFS)* ตามที่ระบุไว้ใน README

## ปิดเครื่องพิมพ์สลิปเป็นค่าเริ่มต้น เพื่อลดขนาดเฟิร์มแวร์ (Host 111.0.0)

ตามที่ตกลงกันว่า **ฟีเจอร์เดิมคงไว้ทั้งหมด ถ้าจะตัดให้ตัดเครื่องพิมพ์สลิปก่อน**
เพราะเป็นของที่เพิ่งเพิ่มเข้ามาในรุ่น `release/06` ไม่ใช่ของเดิมของระบบ

- `#define ENABLE_THERMAL_PRINTER` เปลี่ยนค่าเริ่มต้นจาก `1` เป็น `0`
- ครอบส่วนสร้างเนื้อหาสลิปทั้งก้อน (`asciiSafe`, `asciiName`, `slipClip`, `slipHeader`,
  `slipFooter`, `buildClaimSlip`, `buildDailySlip`, `buildTestSlip`, `printClaimSlip`
  และปลายทาง API ทั้งสี่) ด้วย `#if ENABLE_THERMAL_PRINTER` เหลือเพียงโครงเปล่า
  ตอนปิด จึงไม่มีทั้งสแต็ก USB host และข้อความสลิปถูกคอมไพล์เข้าไปเลย
  ของเดิมปิดแค่ไดรเวอร์ แต่เนื้อหาสลิปยังถูกคอมไพล์ทิ้งไว้เปล่า ๆ
- ตัด `printerGuard()` ทิ้ง ไม่จำเป็นอีกแล้วเมื่อทั้งก้อนอยู่ใต้ `#if`
- หน้าเว็บลดระดับลงอย่างสุภาพ: ปุ่มพิมพ์ใบสรุปบนแดชบอร์ด **ไม่ถูกส่งออกมาเลย**
  (ประหยัดไบต์ด้วย) แท็บตั้งค่ามีแถบเตือนสีเหลืองบอกว่าปิดไว้ในเฟิร์มแวร์
  พร้อมวิธีเปิดกลับ และป้ายบนแดชบอร์ดขึ้นว่า *ปิดการใช้งานในเฟิร์มแวร์*

**ฟีเจอร์อื่นไม่ถูกแตะเลย** — จอสาธารณะ `/display` สองภาษา `ArduinoJson`
`ESPmDNS` คิวออฟไลน์ และการตรวจสิทธิ์ตอนลิงก์ขาด ยังอยู่ครบตามเดิม

เมื่อต่อเครื่องพิมพ์แล้วให้แก้ `#define ENABLE_THERMAL_PRINTER` เป็น `1`
แล้วอัปโหลดใหม่ ฟีเจอร์กลับมาครบทันที

> ยังวัดไม่ได้ว่าประหยัดไปกี่ไบต์จริง เพราะเครื่องที่ใช้พัฒนาคอมไพล์ไม่ได้
> ถ้าคอมไพล์แล้วช่วยส่งบรรทัด `Sketch uses ...` กลับมา จะได้เอาตัวเลขจริง
> ไปใส่ใน README แทนค่าประมาณ

## แก้คำแนะนำการตั้งพาร์ทิชันที่ผิด (เอกสาร)

คอมไพล์แล้วขึ้น `Sketch too big` ใช้ไป 1,339,228 ไบต์ จากเพดาน 1,310,720 ไบต์

**สาเหตุไม่ใช่โค้ดยาวเกินไป แต่เป็นการตั้งพาร์ทิชันผิด** เลข 1,310,720 คือขนาด
พาร์ทิชันโปรแกรมของ *Default 4MB with spiffs* ทั้งที่บอร์ด N16R8 มีแฟลช 16 MB
พอเปลี่ยนเป็น *Huge APP (3MB No OTA/1MB SPIFFS)* จะใช้ไปเพียง 43%

**คำแนะนำเดิมใน README ผิดและอันตรายกว่านั้น** — เขียนไว้ว่าให้ใช้
*16M Flash (3MB APP/9.9MB FATFS)* ซึ่งแม้พื้นที่โปรแกรมจะพอ แต่พาร์ทิชันไฟล์
ถูกตั้งชื่อว่า `ffat` ขณะที่โค้ดเรียก `LittleFS.begin(true)` ซึ่งมองหาชื่อ `spiffs`
ผลคือเมานต์ไม่ขึ้นและ **ฐานข้อมูลนิสิตทั้งหมดหายไป** แก้เป็นตารางการตั้งค่าบอร์ด
แบบครบถ้วนพร้อมคำเตือน

เพิ่มหัวข้อ **ขนาดเฟิร์มแวร์** ใน README ระบุว่าส่วนไหนกินแฟลชเท่าไร
(หน้าเว็บที่ฝังอยู่ 106 KB เป็นก้อนใหญ่สุด) พร้อมตารางทางเลือกลดขนาด
เรียงตามความคุ้มค่าและสิ่งที่ต้องแลก เผื่อกรณีถูกบังคับให้ใช้พาร์ทิชันเล็ก

ไม่มีการแก้โค้ด เลขเวอร์ชันจึงเท่าเดิม

## แก้คอมไพล์ไม่ผ่านใน Arduino IDE (Host 110.0.2 / Station 120.0.1)

คอมไพล์จริงบน Arduino IDE แล้วไม่ผ่าน

```
error: variable or field 'fillStationConfig' declared void
error: 'HostConfigPacket' was not declared in this scope
```

สาเหตุคือ Arduino IDE **สร้างต้นแบบฟังก์ชันให้เองอัตโนมัติ** แล้ววางไว้ใกล้หัวไฟล์
ซึ่งอยู่ **เหนือจุดที่นิยาม struct** ฟังก์ชันที่รับ struct ของสเก็ตช์เป็นพารามิเตอร์
จึงต้องมีการประกาศล่วงหน้าไว้เองเสมอ พอมีแล้ว Arduino จะไม่สร้างต้นแบบซ้อนให้อีก

ไล่ตรวจทั้งสองไฟล์แล้วพบสองจุด แก้ทั้งคู่

- `fillStationConfig(HostConfigPacket&, uint8_t)` ฝั่งแม่ข่าย — จุดที่ทำให้คอมไพล์
  ไม่ผ่าน มีมาตั้งแต่รุ่น `release/03` ตอนเพิ่มการซิงค์โหมดการแสดงผล
- `rosterApplyPacket(const HostRosterPacket&)` ฝั่งสถานี — เพิ่งเพิ่มมาใน
  `release/07` ยังไม่ทันได้เจอเพราะฝั่งแม่ข่ายพังก่อน

เพิ่ม [`tools/proto-check/`](tools/proto-check/) ไว้ตรวจปัญหาชนิดนี้โดยไม่ต้องมี
toolchain ของ ESP32 และเขียนเตือนไว้ใน README สำหรับการแก้โค้ดต่อ

> **หมายเหตุเรื่องคำเตือนตอนคอมไพล์** ถ้าขึ้นว่า `Multiple libraries were found for
> "Preferences.h"` แปลว่ามีโฟลเดอร์ `Preferences` ค้างอยู่ใน `~/Documents/Arduino/libraries/`
> ซ้ำกับที่มากับ ESP32 core ลบโฟลเดอร์นั้นทิ้งได้ ไม่ใช่สาเหตุของการคอมไพล์ไม่ผ่าน
> แต่ควรเอาออกกันสับสน

## อยู่ร่วมกับเฟิร์มแวร์สถานีรุ่นเก่าได้ (Host 110.0.1)

ตอนเขียนสารบัญเวอร์ชันแล้วไล่ตรวจว่าผสมรุ่นข้ามฝั่งได้จริงไหม พบว่ายังไม่ได้

เฟิร์มแวร์สถานีรุ่นก่อน 120.0.0 ไม่ได้ฝากเลขรุ่นบัญชีมากับ heartbeat (ช่องนั้นเป็นศูนย์ล้วน)
แม่ข่ายจึงอ่านได้เป็น "รุ่น 0" ซึ่งไม่มีวันตรงกับรุ่นของตัวเอง ผลคือ**ไล่ผลักบัญชีชุดเต็ม
ไปให้เครื่องที่รับไม่เป็นทุก heartbeat ไม่มีวันจบ** ประมาณ 11 แพ็กเก็ตทุก 6 วินาที

- แยกให้ออกจากสถานีรุ่นใหม่ที่ยังไม่มีบัญชี ซึ่งจะฝาก `R:0` มาเสมอ
  ใช้การมีอยู่ของคำนำหน้า `R:` เป็นตัวบอกว่าเฟิร์มแวร์รองรับหรือไม่
- ไม่ผลักบัญชีและไม่ส่งอัปเดตทีละรายการไปให้สถานีที่รับไม่เป็นเลย
- แดชบอร์ดขึ้นว่า *เฟิร์มแวร์เก่า ไม่รองรับ* ที่การ์ดจุดบริการนั้น
  จุดบริการยังทำงานครบทุกอย่าง แค่ไม่มีการตรวจสิทธิ์ตอนลิงก์ขาด
- ชุดทดสอบเพิ่มข้อ 10 ครอบคลุมทั้งกรณีรุ่นเก่าและตอนแฟลชเป็นรุ่นใหม่แล้ว

## จัดระเบียบเวอร์ชันและเก็บต้นฉบับ

- แบ่งเป็นรุ่น `release-00` ถึง `release-07` ทุกจุดที่เลขเวอร์ชันของฝั่งใดฝั่งหนึ่งเปลี่ยน
  แต่ละรุ่นคือเฟิร์มแวร์ครบทั้งคู่ที่ใช้ด้วยกันได้ ตรวจแล้วทีละรุ่นว่าชื่อรุ่นตรงกับ
  `APP_VERSION` ที่อยู่ในโค้ดของคอมมิตนั้นจริง
- จัดโครงสร้าง branch: ย้ายทุกรุ่นไปอยู่ใต้โฟลเดอร์ `release/` (`release/00-...`
  ถึง `release/07-...`) และเพิ่ม `main` เป็น branch หลักแทนชื่อสุ่มจากเซสชัน
  วิธีสลับ default branch กับคำสั่งลบของเก่าอยู่ใน `VERSIONS.md`
- push ขึ้น GitHub เป็น **branch** ไม่ใช่ tag เพราะบัญชีที่เซสชันนี้ใช้
  push `refs/tags/*` ไม่ได้
  เซิร์ฟเวอร์ตอบ 403 ทุกครั้ง (ยืนยันแล้วว่าไม่ใช่การปิดกั้นของพร็อกซี)
  ได้ผลเหมือน tag ทุกอย่างสำหรับการย้อนกลับ และกดโหลด zip ได้จากตารางใน `VERSIONS.md`
  ส่วนคำสั่งสร้าง tag จริงเตรียมไว้ให้คัดลอกไปรันครั้งเดียวจบเช่นกัน
- เพิ่ม [`VERSIONS.md`](VERSIONS.md) เป็นสารบัญเวอร์ชัน พร้อมวิธีย้อนกลับ
  และตารางความเข้ากันได้ของโปรโตคอล ซึ่งอ่านขนาดโครงสร้างจาก `static_assert`
  ในโค้ดของแต่ละแท็กจริง
- เพิ่มโฟลเดอร์ [`original/`](original/) เก็บโค้ดต้นฉบับที่ส่งมาตอนเริ่มโครงการ
  (Host 107.0.1 / Station 117.0.7) ไว้ตามเดิมทุกไบต์ ตรวจสอบด้วย md5 แล้วว่า
  ตรงกับไฟล์ที่ได้รับและตรงกับคอมมิตแรกของโครงการ วางไว้ในโฟลเดอร์ที่ชื่อ
  ตรงกับชื่อไฟล์ จึงเปิดด้วย Arduino IDE ได้ทันที

## ตรวจสิทธิ์ได้เองตอนลิงก์ขาด (Host 110.0.0 / Station 120.0.0)

ปิดช่องโหว่ที่เหลืออยู่ของคิวออฟไลน์: เดิมเมื่อแม่ข่ายไม่ตอบ สถานีรับบัตร **ทุกใบ**
เข้าคิวโดยไม่ตรวจอะไรเลย บัตรที่ไม่ได้ลงทะเบียนหรือบัตรที่ใช้สิทธิ์ไปแล้วก็ได้อาหารไปก่อน
แล้วค่อยไปตกตอนซิงค์ ซึ่งสายเกินกว่าจะเรียกคืนได้

**บัญชีสิทธิ์ย่อที่ผลักไปเก็บที่สถานี** — ข้อความชนิดใหม่ `MSG_ROSTER (5)`
และแพ็กเก็ต `HostRosterPacket` 206 ไบต์ (38 รายการต่อก้อน)

- เก็บเป็นค่าแฮช FNV-1a 32 บิตของเลขบัตร + สถานะใช้สิทธิ์ = 5 ไบต์ต่อคน
  นิสิต 600 คนใช้ 3 KB สถานีไม่เคยได้รับเลขบัตรจริงหรือชื่อนิสิตเลย
- ผลักชุดเต็มเมื่อชุดผู้มีสิทธิ์เปลี่ยน (ทุกเส้นทางผ่าน `saveDatabaseToFS()` จุดเดียว)
  และเมื่อสถานีรายงานเลขรุ่นไม่ตรง ทยอยส่งก้อนละ 30 ms ไม่แย่งจังหวะการสแกนสด
- ตอนมีคนใช้สิทธิ์ส่งแค่รายการเดียว (สถานีละ 1 แพ็กเก็ต) แทนการผลักทั้งชุดวันละ 268 รอบ
- สถานีฝากเลขรุ่นที่ถืออยู่ไปกับ heartbeat ผ่านช่อง `offlineTime` ที่ว่างอยู่แล้ว
  จึงไม่ต้องขยาย `StationPacket` และเฟิร์มแวร์สถานีรุ่นเก่าถูกมองเป็นรุ่น 0 โดยอัตโนมัติ
- เก็บลง NVS แบบหน่วงเวลา 5 นาที บัญชีจึงไม่หายเมื่อรีบูตกลางที่ลิงก์ขาด
  และไม่กินอายุแฟลชโดยไม่จำเป็น

**หลักการคือ "ไม่มั่นใจ ให้ปล่อยผ่าน"** เพราะการปฏิเสธนิสิตที่มีสิทธิ์จริงเสียหายกว่า
การปล่อยบัตรแปลกปลอมผ่านไปหนึ่งใบ ซึ่งแม่ข่ายปัดตกตอนซิงค์อยู่ดี
กรณีที่กลับไปรับบัตรทุกใบเหมือนเดิม: ยังไม่เคยได้รับบัญชี กำลังรับชุดใหม่
จำนวนผู้มีสิทธิ์เกิน `ROSTER_MAX` (600) หรือบัญชีค้างข้ามวัน

**สองจุดที่แก้ตั้งแต่ตอนออกแบบ เพราะจะพังของจริง**

- *บัญชีค้างข้ามวัน* — ถ้าเปิดเครื่องตอนเช้าก่อนแม่ข่ายขึ้นแล้วมีนิสิตมาแตะ บัญชีของเมื่อวาน
  จะทำให้ทุกคนที่กินเมื่อวานถูกปฏิเสธ แก้ด้วยการติดวันที่ (`rosterDate`) ไปกับทุกชุด
  ถ้าวันที่ไม่ตรงหรือนาฬิกายังไม่ซิงค์ จะไม่เชื่อสถานะ "ใช้สิทธิ์แล้ว" แต่ยังตรวจได้ว่า
  บัตรใบไหนไม่อยู่ในทะเบียน เพราะทะเบียนไม่เปลี่ยนรายวัน
- *บัญชีใหญ่เกินเก็บไหว* — เวอร์ชันแรกตั้งเลขรุ่นเป็น 0 เมื่อเก็บไม่ครบ ซึ่งทำให้แม่ข่าย
  ผลักชุดเต็มมาใหม่ทุก heartbeat ไม่จบ แก้เป็นรับเลขรุ่นไว้เสมอ แล้วกันด้วยธง
  `rosterTruncated` แทน พร้อมเติม `!` ต่อท้ายเลขรุ่นใน heartbeat ให้แดชบอร์ดขึ้นเตือน

**หน้าจอใหม่ฝั่งสถานี** — จอปฏิเสธสองแบบ (แดง = บัตรไม่อยู่ในทะเบียน, ส้ม = ใช้สิทธิ์ไปแล้ว)
ขึ้นชัดว่า `DO NOT SERVE THE STUDENT` เพื่อแยกจากจอฟ้าที่แปลว่าบันทึกไว้แล้วให้จ่ายได้เลย
และเพิ่มแถว `OFFLINE CARD LIST` บนหน้า 3/3

**แดชบอร์ด** — การ์ดจุดบริการแต่ละใบขึ้นสถานะ `📋 รายชื่อออฟไลน์`
(เขียว = พร้อมใช้พร้อมเลขรุ่น, เหลือง = กำลังส่งให้, แดง = เกินที่เครื่องเก็บไหว)

**การตรวจสอบ** — ดึงฟังก์ชันจริงจากทั้งสอง `.ino` มาคอมไพล์ด้วย g++ บนเครื่องพัฒนา
แล้วรันจำลองโปรโตคอลทั้งวงจร ผ่านครบ 30 ข้อ ครอบคลุมการผลักชุดเต็ม การอัปเดตทีละรายการ
delta หายกลางทางแล้วกู้คืนเอง ปิดยอดประจำวัน บัญชีเกินความจุ บัญชีค้างข้ามวัน
การชนกันของค่าแฮชในชุดนิสิต 412 คน เลขรุ่นวนรอบที่ 65535 และ heartbeat จากเฟิร์มแวร์รุ่นเก่า
สคริปต์ยังตรวจด้วยว่านิยามโครงสร้างแพ็กเก็ตสองฝั่งตรงกันทุกไบต์

> ยังไม่ได้คอมไพล์ด้วย toolchain ของ ESP32 (สภาพแวดล้อมที่พัฒนาเข้า `downloads.arduino.cc`
> ไม่ได้) และยังไม่ได้ทดสอบกับฮาร์ดแวร์จริง

## เครื่องพิมพ์สลิปความร้อน 58 มม. (Host 109.0.0)

เพิ่มความสามารถต่อเครื่องพิมพ์ความร้อนหน้ากว้าง 58 มม. เข้ากับเครื่องแม่ข่าย
พิมพ์สลิปให้นิสิตทุกครั้งที่ใช้บริการ และสั่งพิมพ์จากหน้าเว็บได้

**ไฟล์ใหม่ `ThermalPrinter.h`** — ไดรเวอร์ ESC/POS อิสระ ไม่รู้จักข้อมูลของระบบ
รับแค่สตริงไบต์ใส่คิวแล้วทยอยส่งออก จึง `#include` ไว้บนสุดของสเก็ตช์ได้
(ต่างจาก `WebPortal.h` ที่ต้องอยู่ท้ายไฟล์)

- สองช่องทางสลับด้วย `#define PRINTER_TRANSPORT_UART` บรรทัดเดียว
  - **0 = USB OTG host (ค่าเริ่มต้น)** — เขียนไดรเวอร์คลาสปริ้นเตอร์เองบน `usb_host_lib`
    เดินดูไบต์ของ config descriptor เอง เลือกอินเทอร์เฟซคลาส 0x07 (Printer) ก่อน
    แล้วค่อยถอยไป 0x0A (CDC Data) หาจุดปลาย bulk-OUT แล้วส่งทีละก้อน 64 ไบต์
  - **1 = UART TTL** — GPIO 17 (TX) / GPIO 18 (RX) / ร่วม GND ที่ 9600 8N1
- คิวพักได้ 8 ใบ คิวเต็มแล้วทิ้งใบใหม่ **ไม่บล็อกการตัดสิทธิ์** ไม่ว่ากรณีใด
- ใบที่ค้างคิวเกิน 2 นาทีโดยไม่พบเครื่องพิมพ์จะถูกทิ้งเอง กันอาการพ่นสลิปเก่า
  ที่หมดความหมายแล้วออกมารวดเดียวตอนเสียบเครื่องพิมพ์ทีหลัง
- มีสวิตช์ `ENABLE_THERMAL_PRINTER 0` ปิดทั้งระบบให้กลับไปเท่าเดิมทุกประการ

**เนื้อหาสลิป (อังกฤษ + ตัวเลขล้วน)** — หัวพิมพ์ราคาประหยัดไม่มีฟอนต์ไทยในตัว
ถ้าส่งไบต์ UTF-8 ไทยออกไปจะได้อักขระขยะเต็มม้วน

- `asciiSafe()` กรองให้เหลือ ASCII 32–126 · `asciiName()` บังคับเพิ่มว่าต้องมี
  ตัวอักษรอังกฤษอย่างน้อยหนึ่งตัว มิฉะนั้นใช้ข้อความสำรอง — เพราะชื่ออย่าง
  "ร้านที่ 1" ถ้ากรองเฉย ๆ จะเหลือแค่ "1" ซึ่งอ่านไม่รู้เรื่อง
- ชื่อนิสิตภาษาไทย → `STUDENT <รหัสนิสิต>` · ชื่อร้านภาษาไทย → เหลือหมายเลขร้าน
- ทุกบรรทัดถูกตรวจแล้วว่าไม่ล้น 32 ช่อง (ตัวใหญ่นับสองเท่า) เลขอ้างอิงยาว 28 ตัว
  จึงถูกย้ายไปขึ้นบรรทัดของตัวเอง ไม่ให้ถูกตัดขึ้นบรรทัดใหม่เอง
- สามแบบ: สลิปนิสิต · ใบสรุปยอดประจำวันพร้อมช่องลงนาม · สลิปทดสอบ

**จุดที่สั่งพิมพ์**

- พิมพ์อัตโนมัติทุกครั้งที่ตัดสิทธิ์สำเร็จ ทั้งจากการแตะบัตรและจากการตัดสิทธิ์ด้วยตนเอง
  เปิด/ปิดได้จากแท็บตั้งค่า จำค่าไว้ใน NVS คีย์ `prn_auto`
- **ข้ามรายการที่ซิงค์ย้อนหลัง** หลังลิงก์ขาด เพราะนิสิตรับอาหารและกลับไปแล้วตั้งแต่ตอนนั้น
  การพิมพ์ทีละหลายสิบใบจะล้นคิวและเปลืองกระดาษเปล่า ยอดยังอยู่ครบในใบสรุปและไฟล์ CSV
- ปุ่ม 🖨️ ต่อแถวในตารางรายชื่อ (เฉพาะรายการที่ตัดสิทธิ์แล้ว) = พิมพ์ซ้ำ
- ปุ่มพิมพ์ใบสรุปประจำวันบนแดชบอร์ด

**หน้าเว็บ** — การ์ดตั้งค่าเครื่องพิมพ์ในแท็บตั้งค่า (สวิตช์อัตโนมัติ + ปุ่มพิมพ์ทดสอบ +
สถานะการเชื่อมต่อและช่องทางที่คอมไพล์ไว้) และป้ายสถานะสดบนแดชบอร์ด
อัปเดตทุก 3 วินาทีผ่านคีย์ `printer` ใน `/api/dashboard`

**ปลายทางใหม่** `/api/print/test` · `/api/print/slip` · `/api/print/daily` ·
`/api/settings/printer` ทั้งหมดเป็น POST และผ่าน `requireAuth()`

**แก้เลขเวอร์ชันที่ค้าง** — `APP_VERSION` ของแม่ข่ายยังเป็น `108.0.0` ทั้งที่
CHANGELOG ไประบุ 108.3.0 แล้ว และตาราง README ยังบอกสถานีเป็น 118.0.0
ทั้งที่โค้ดจริงเป็น 119.0.0 → แก้ให้ตรงกันทั้งหมด

> **ยังไม่ได้คอมไพล์และยังไม่ได้ทดสอบกับเครื่องพิมพ์จริง** — สภาพแวดล้อมที่พัฒนา
> เข้า `downloads.arduino.cc` ไม่ได้ (ถูกนโยบายพร็อกซีปิดกั้น) จึงติดตั้ง toolchain
> ไม่ได้ ส่วนที่เสี่ยงที่สุดคือไดรเวอร์ USB host เพราะ ESP-IDF ไม่มีไดรเวอร์คลาส
> ปริ้นเตอร์มาให้ ต้องเขียนเองทั้งหมด ถ้า USB ไม่ยอมทำงานให้ตั้ง
> `PRINTER_TRANSPORT_UART` เป็น 1 แล้วต่อสาย TTL แทน เนื้อหาสลิปและปุ่มบนหน้าเว็บ
> ทำงานเหมือนกันทั้งสองช่องทาง

## ความทนทานของลิงก์และคิวออฟไลน์ (Host 108.3.0 / Station 119.0.0)

ตรวจคุณสมบัติการเชื่อมต่อทั้งสองฝั่งสำหรับระยะห่างราว 20 เมตร

**การตั้งค่าวิทยุ**

- กำลังส่งเดิมตั้งไว้ `esp_wifi_set_max_tx_power(68)` = 17 dBm ทั้งที่ ESP32-S3 ตั้งได้ถึง
  80 = 20 dBm → ปรับขึ้นทั้งสองฝั่ง
- เพิ่ม `WIFI_PROTOCOL_LR` คู่กับ 11b/g/n ทั้งสองฝั่ง โทรศัพท์ยังต่อ Wi-Fi ได้ตามปกติ
- เพิ่มสวิตช์ `ESPNOW_FORCE_LONG_RANGE_RATE` สำหรับบังคับอัตราส่ง LoRa 250 kbps
  ตั้งค่าเริ่มต้นไว้ที่ปิด เพราะถ้าเปิดข้างเดียวทั้งสองเครื่องจะคุยกันไม่รู้เรื่อง

**การส่งซ้ำ**

- เดิมถ้า unicast ล้มเหลวจะยิงเป็น broadcast แทน ซึ่ง**ทำให้แย่ลง** เพราะ broadcast
  ไม่มี ACK ระดับ MAC จึงไม่มีการส่งซ้ำอัตโนมัติของชิป ขณะที่ unicast มี ARQ ในตัว
  → ใช้ broadcast เฉพาะตอนยังไม่รู้จัก MAC ของอีกฝั่ง
- สถานีลงทะเบียน `onDataSent` ไว้แต่ทิ้งสถานะ (`(void)status`) → นำมาใช้ยิงซ้ำทันที
  ที่ชิปแจ้งว่าส่งไม่ถึง แทนการรอครบช่วงเวลา
- แม่ข่ายไม่เคยลงทะเบียน send callback เลย → เพิ่ม และยิงคำตอบการสแกนซ้ำได้อีก 2 ครั้ง
- เดิมส่งซ้ำแค่ 3 ครั้ง ห่างกัน 450 ms ใช้เวลาไป 1.35 วินาทีจาก timeout 3 วินาที
  เหลือเวลาว่างเปล่า 1.65 วินาที → เปลี่ยนเป็น 7 ครั้งภายในเวลาเท่าเดิม ถี่ช่วงแรกแล้วห่างออก

**คิวออฟไลน์ฝั่งสถานี** — ช่อง `StationPacket.offlineTime[24]` มีอยู่ในโครงสร้างตั้งแต่แรก
แต่ไม่เคยถูกใช้ทั้งสองฝั่ง ตอนนี้นำมาใช้งานจริง

- แม่ข่ายไม่ตอบ → บันทึกการแตะลง NVS (48 รายการต่อสถานี) แล้วขึ้นจอบอกให้จ่ายอาหารได้เลย
  แทนการขึ้นจอแดงปฏิเสธนิสิตโดยไม่เหลือร่องรอย
- ลิงก์กลับมา → ส่งเข้าระบบเองทีละรายการ โดยใช้เวลาตอนแตะบัตรจริงเป็นเวลารับสิทธิ์
- แม่ข่ายข้ามการตรวจช่วงเวลาบริการให้รายการย้อนหลัง จึงไม่ถูกปฏิเสธเพราะซิงค์หลังปิดบริการ
- บัตรใบเดิมแตะซ้ำที่สถานีเดียวกันระหว่างออฟไลน์จะไม่ถูกบันทึกซ้ำ
- ถ้ารู้อยู่แล้วว่าแม่ข่ายหลุด ลดเวลารอต่อการแตะจาก 3 วินาทีเหลือ 1.5 วินาที
- ประเภทบัตรในบันทึกต่อท้ายว่า `(Offline)` ให้เจ้าหน้าที่แยกออกได้
- หน้าแรกของสถานีเปลี่ยนบรรทัดล่างเป็นคำเตือนสีเหลืองบอกจำนวนรายการที่รอส่ง

---

## เติมข้อมูลหน้า 2 ของเครื่องประจำร้านค้า (Station 118.2.0)

เดิมการ์ดสองใบจบที่ y=160 แต่แถบล่างเริ่มที่ y=218 เหลือพื้นที่ว่างเปล่า 58 พิกเซล
คิดเป็น 24% ของความสูงจอ และการ์ดขวาเป็นข้อความคงที่ทั้งใบ (QUOTA / LIMIT / RADIO / CH 1)
ซึ่งไม่มีวันเปลี่ยนค่า

**ที่เพิ่มเข้ามา**

- **รายการที่จ่ายล่าสุดสามรายการของร้านนี้** เต็มแถบล่างที่เคยว่าง แสดงเวลา
  รหัสนิสิตแบบปิดบังห้าหลักแรก และจำนวนเงิน เก็บเป็นคิววนในแรม
- **ภาพรวมทั้งโรงอาหาร** แทนที่การ์ดขวาที่เป็นข้อความคงที่ ด้วยยอดใช้สิทธิ์ทั้งระบบ
  เทียบผู้มีสิทธิ์ทั้งหมด แถบความคืบหน้า สัดส่วนเป็นเปอร์เซ็นต์ และสถานะเปิด-ปิดบริการ
  พร้อมช่วงเวลา — แม่ข่ายฝากมากับช่อง `message[32]` ที่ว่างอยู่ในแพ็กเก็ต heartbeat
  **ขนาดแพ็กเก็ตไม่เปลี่ยน** และเฟิร์มแวร์รุ่นเก่าที่ไม่อ่านช่องนี้ก็ยังทำงานได้ตามปกติ
- **จำนวนครั้งที่ไม่สำเร็จและเวลาที่จ่ายล่าสุด** ในการ์ดซ้าย ซึ่งเดิม `totalScansToday`
  ถูกนับไว้แต่ไม่เคยถูกนำมาแสดงที่หน้าไหนเลย
- ถอดป้าย ONLINE ออกจากการ์ดซ้าย เพราะซ้ำกับตัวบอกสถานะบนแถบบนอยู่แล้ว
  และเดิมวางห่างข้อความ TODAY SERVED แค่ 2 พิกเซลจนดูเหมือนชนกัน
- แยก `displayStatsDashboard()` เป็นส่วนคงที่กับส่วนที่เปลี่ยนค่า จึงรีเฟรชทุก heartbeat
  ได้โดยจอไม่กะพริบ
- แก้เอกสาร: ตารางโปรโตคอลใน README ยังค้างขนาด `HostConfigPacket` ไว้ที่ 5 ไบต์
  จากตอนที่ยังไม่ได้ขยายเป็น 8 ไบต์

---

## ปรับหน้าแรกของเครื่องประจำร้านค้า

- เพิ่มสัญลักษณ์บัตร RFID กลางหน้าจอ เป็นรูปบัตรพร้อมชิปและคลื่น contactless สามชั้น
  วาดด้วย `drawRoundRect`, `fillRoundRect` และ `drawCircleHelper` ของ Adafruit GFX ล้วน ๆ
  จึงไม่กินพื้นที่แฟลชเพิ่มเหมือนการฝังบิตแมป และเปลี่ยนสีตามธีมได้
- ยกข้อความสิทธิ์ต่อวันออกมาเป็นการ์ดของตัวเองที่มีขอบสีเหลือง จากเดิมเป็นบรรทัดเล็ก
  ขนาด 1 อยู่ท้ายการ์ดเดียวกับข้อความอื่น ตอนนี้ **35 THB / DAY** ใช้ตัวอักษรขนาด 3
  จัดกึ่งกลาง อ่านได้จากระยะไกลของเคาน์เตอร์ โดยมีคำว่า SUBSIDY QUOTA กำกับด้านบน
- ข้อความเดิมอยู่ครบทุกบรรทัด: `READY FOR RFID CARD TAP`, `TAP CARD HERE`
  และ `Protocol: ESP-NOW Channel 1 Secured` (ย้ายมาอยู่นอกการ์ด จัดกึ่งกลางจอ)

---

## แก้ปัญหาพอร์ทัลใช้งานไม่ได้ในหน้าต่าง Captive Portal

ตรวจสอบพฤติกรรมตอนโทรศัพท์หรือคอมพิวเตอร์เชื่อมต่อ Wi-Fi ของเครื่องแม่ข่าย

**บั๊กที่พบและแก้แล้ว** — หน้าพอร์ทัลพังทั้งหน้าในเบราว์เซอร์ที่ `localStorage` ใช้ไม่ได้
ซึ่งเป็นกรณีของหน้าต่าง Captive Portal บน iOS/Android และโหมดไม่ระบุตัวตนพอดี
`initTheme()` เรียก `localStorage.getItem()` โดยไม่หุ้ม try/catch เมื่อเบราว์เซอร์โยน
SecurityError สคริปต์จึงตายตั้งแต่บรรทัดแรกของการเริ่มต้น ผลคือ `bindAjaxForms()`,
`bindDelegatedActions()` และ `refreshDashboard()` ไม่เคยถูกเรียก ฟอร์มทุกใบไม่ทำงาน
ปุ่มในตารางกดไม่ได้ และแดชบอร์ดค้างอยู่ที่แถบ skeleton ตลอดไป
→ เพิ่มตัวช่วย `lsGet()` / `lsSet()` ที่หุ้ม try/catch และแยกการเรียกขั้นเริ่มต้นออกจากกัน
เพื่อไม่ให้ขั้นใดขั้นหนึ่งล้มแล้วลากส่วนที่เหลือตายไปด้วย

**ส่วนที่ทำงานถูกต้องอยู่แล้ว** — การดัก DNS และการตอบ 302 ทำให้ Android, iOS,
Windows และ Firefox เด้งหน้าต่างเข้าสู่ระบบขึ้นมาเองครบทุกระบบ

**ที่ปรับเพิ่มเพื่อความทนทาน**

- ส่ง `Location` เป็น URL แบบเต็ม (`http://192.168.4.1/login`) แทนเส้นทางสัมพัทธ์
  เพราะตัวตรวจจับของบางระบบปฏิบัติการดูโฮสต์ในส่วนหัวนี้ และแนบหน้า HTML
  ที่มี meta refresh ไปด้วยสำหรับเครื่องที่ไม่ตามส่วนหัว Location
- ตั้ง `dnsServer.setTTL(0)` และ `setErrorReplyCode(NoError)` เพื่อไม่ให้โทรศัพท์
  จำการชี้โดเมนทั้งหมดมาที่ `192.168.4.1` ไว้หลังตัดการเชื่อมต่อไปแล้ว
- เพิ่ม `Cache-Control: no-store` ในผลตอบกลับของ captive portal
- ตอบ 204 ให้ `/favicon.ico` แทนที่จะปล่อยให้ตกไปที่ onNotFound แล้วโหลดหน้า
  ล็อกอินทั้งหน้ามาเป็นไอคอน
- เพิ่มลิงก์ไปหน้าสถานะโรงอาหารบนหน้าล็อกอิน สำหรับคนที่ไม่ใช่เจ้าหน้าที่
  ซึ่งเดิมเจอแต่ช่องกรอกรหัสที่ผ่านไม่ได้

---

## ซิงค์โหมดการแสดงผลจากแม่ข่ายไปสถานี (Host 108.2.0 / Station 118.1.0)

เครื่องแม่ข่ายเป็นเจ้าของโหมดการแสดงผลของทั้งระบบ

- ขยาย `HostConfigPacket` จาก 5 เป็น 8 ไบต์ เพิ่ม `screenOn`, `screensaver` และ `modeSeq`
  (`static_assert` ยืนยันขนาดทั้งสองฝั่ง เฟิร์มแวร์คนละรุ่นจะไม่ซิงค์กันแต่การแตะบัตรยังทำงานปกติ)
- **ธีมสว่าง/มืด บังคับเสมอ** — แม่ข่ายย้ำคำสั่งทุกครั้งที่ตอบ heartbeat สถานีที่ค่าไม่ตรงจะเปลี่ยนตาม
  ภายในไม่กี่วินาที การกดสามครั้งที่สถานีจึงขึ้นหน้าแจ้งว่าธีมถูกกำหนดจากแม่ข่ายแทนการสลับเอง
- **โหมดพักหน้าจอ** — แม่ข่ายเข้า/ออกโหมดพักหน้าจอ ทั้งจากการกดสองครั้งและการหมดเวลา 5 นาที
  จะสั่งให้ทุกสถานีทำตาม และการแตะบัตรที่จุดใดก็ตามจะปลุกทั้งระบบพร้อมกัน
- **ไฟหน้าจอ** — เพิ่มการกดค้าง 1.5 วินาทีที่แม่ข่ายเพื่อปิด/เปิดไฟหน้าจอ ซึ่งเดิมมีแต่ฝั่งสถานี
  และสั่งให้ทุกสถานีดับจอตาม เมื่อจอแม่ข่ายดับ ระบบจะหยุดวาดจอเพื่อลดงานที่ไม่จำเป็น
- โหมดพักหน้าจอและไฟหน้าจอเป็นคำสั่งแบบ "สั่งเมื่อเปลี่ยน" ดูจาก `modeSeq` ที่เพิ่มขึ้น
  สถานีจึงยังกดปิดจอของตัวเองได้โดยไม่ถูกสั่งเปิดกลับทุกรอบ heartbeat
- ถ้าสถานีกำลังแสดงผลการแตะบัตรอยู่ จะเลื่อนการเปลี่ยนโหมดไปทำหลังจอผลลัพธ์หมดเวลา
  ไม่ตัดจอกลางคันระหว่างที่นิสิตกำลังอ่านผล
- คำสั่งเปลี่ยนโหมดถูก broadcast สามครั้งห่างกัน 8 มิลลิวินาที เพราะ ESP-NOW แบบ broadcast
  ไม่มีการยืนยันการรับ

---

## เพิ่มจอสาธารณะ (Host 108.1.0)

เพิ่มหน้า `/display` สำหรับต่อออกมอนิเตอร์จอใหญ่ในโรงอาหาร ให้นิสิตและร้านค้าเห็น
ยอดการใช้บริการแบบเรียลไทม์

- รีเฟรชตัวเองทุก 2 วินาทีจาก `/api/display` แสดงยอดใช้สิทธิ์ ยอดจัดสรร
  รายการที่ตัดสิทธิ์ล่าสุด 12 รายการ และสถานะร้านค้าทั้งสี่
- **เปิดดูได้โดยไม่ต้องเข้าสู่ระบบ** จึงไม่กินช่องผู้ใช้งานของเจ้าหน้าที่ที่มีอยู่ 3 ช่อง
- ข้อมูลที่ส่งออกถูกตัดให้เหลือเฉพาะที่เปิดเผยได้: ไม่มีชื่อนิสิต ไม่มีเลขบัตร
  ไม่มีเลขที่อ้างอิง ไม่มีข้อมูลฮาร์ดแวร์แม่ข่าย และรหัสนิสิตปิดบังเหลือห้าหลักแรก
- แสดงเฉพาะรายการที่ตัดสิทธิ์สำเร็จ ไม่แสดงบัตรซ้ำหรือบัตรที่ไม่อยู่ในทะเบียน
  เพื่อไม่ให้นิสิตถูกประจานบนจอสาธารณะ
- ไม่มีเมนูและไม่มีปุ่มสั่งงาน เปิดไปหน้าอื่นของระบบไม่ได้
- เพิ่มสวิตช์เปิด/ปิดหน้าจอสาธารณะในแท็บ จัดการระบบ → กำหนดเวลา & ระบบ
  (เก็บค่าใน Preferences คีย์ `pub_disp` ค่าเริ่มต้นคือเปิด)
- ขยายจำนวนเครื่องที่ต่อ Wi-Fi พร้อมกันได้จาก 4 เป็น 8 เพราะจอสาธารณะกินไปหนึ่งช่อง
- ใช้ฟอนต์ของระบบล้วน ๆ ไม่พึ่งเว็บฟอนต์ เพราะเครือข่ายของแม่ข่ายไม่มีทางออกอินเทอร์เน็ต
- ถ้าดึงข้อมูลไม่สำเร็จสองครั้งติดกันจะขึ้นแถบเตือนท้ายจอ แล้วพยายามเชื่อมต่อใหม่ต่อไปเอง
- คิวรายการถูกล้างเมื่อปิดยอดประจำวัน

---

## Host Server 108.0.0 / Station Client 118.0.0

ตรวจสอบโค้ดทั้งสองฝั่งจากรุ่น 107.0.1 / 117.0.7 แล้วแก้ข้อผิดพลาดที่พบ พร้อมปรับ UX/UI
ตามขอบเขตที่เลือกไว้ (จอ: ย่อฟอนต์อัตโนมัติ + สถานะสดจริง · เว็บ: toast/AJAX + แดชบอร์ดสด +
ตารางลื่นขึ้น · ความปลอดภัย: เต็มชุด · SPI: ย้ายจอไป HSPI)

---

### Station Client — ข้อผิดพลาดที่แก้

1. **บัส SPI ชนกัน** — `SPIClass SPI_TFT(FSPI)` อยู่บน peripheral เดียวกับตัวแปร `SPI`
   มาตรฐานของ ESP32-S3 ที่ไลบรารี MFRC522 ใช้ ทั้งสองอุปกรณ์จึงถูกตั้งขาคนละชุดบนบัสเดียวกัน
   → ย้ายจอไป `HSPI`
2. **คำสั่งสลับธีมจากแม่ข่ายถูกทิ้งทั้งหมด** — ตัวรับ ESP-NOW ตัดทุกแพ็กเก็ตที่
   `len != sizeof(HostResponsePacket)` (200 ไบต์) ส่วน `HostConfigPacket` มีแค่ 5 ไบต์
   → เพิ่มการรับ `MSG_CONFIG` และนำไปใช้จริงใน `applyPendingTheme()`
3. **แถบสถานะลิงก์ไม่เคยแสดง** — `updateTopRightHeaderSmooth()` ถูกเขียนไว้ครบแต่ไม่เคยถูกเรียก
   → เปลี่ยนเป็น `updateStationHeaderStatus()` เรียกจาก `drawStationTopBar()` และรีเฟรชทุก 1 วินาที
4. **หน้า Diagnostics ค้างนิ่ง** — `STATE_STATUS` ไม่เคยถูกกำหนดค่า เงื่อนไขรีเฟรชในลูปจึงไม่เคยเป็นจริง
   → เพิ่ม `showStationPage()` ที่ตั้ง state ให้ตรงกับหน้าที่แสดงอยู่เสมอ
5. **ค่าที่หายไปบนหน้า Diagnostics** — มีหัวข้อ `BATTERY VOLTAGE` และ `TODAY SERVED`
   แต่ไม่เคยพิมพ์ค่าลงไป → เติมค่าพร้อมสีบอกสถานะแบตเตอรี่
6. **จอผลลัพธ์ขึ้นช้าเกือบ 1 วินาที** — `soundError()` / `soundAlarm()` บล็อก 660–750 ms
   ก่อนคำสั่งวาดจอ → ย้ายไปเล่นหลังวาดเสร็จ
7. **ตัวนับซ่อนอยู่ในฟังก์ชันวาดจอ** — `totalSuccessToday++` อยู่ใน `displayResult()`
   → ย้ายไปนับที่ลูปหลักตอนได้รับคำตอบ `SUCCESS`
8. **ข้อความแบนเนอร์ล้นจอ** — `"! DUPLICATE: ALREADY CLAIMED !"` ที่ size 2 กว้าง 360px เกินจอ 320px
   และถูกตัดทิ้ง → เพิ่ม `drawFitCenteredText()` ที่ย่อขนาดฟอนต์อัตโนมัติ
9. **ADC บล็อกลูป** — `readBatteryVoltage()` ใช้ `delay(2)` แปดรอบ → เปลี่ยนเป็น
   `delayMicroseconds(300)` พร้อมแคชผล 3 วินาที
10. **เขียน NVS ถี่เกินจำเป็น** — บันทึกยอดทุก heartbeat (~ทุก 6 วินาที) → เขียนเฉพาะตอนค่าเปลี่ยนจริง
11. **`noInterrupts()` ไม่ได้ป้องกันอะไร** — callback ของ ESP-NOW ทำงานใน task ไม่ใช่ ISR
    → เปลี่ยนเป็น `portMUX` critical section
12. รูปแบบ `%d` กับตัวแปร `uint32_t` → แก้เป็น `%u` พร้อม cast

---

### Host Server — ข้อผิดพลาดที่แก้

1. **เลขอ้างอิงบนจอไม่ตรงกับที่บันทึกจริง** — หน้า 3 เรียก `generateRefNo()` ทุกครั้งที่วาดจอ
   ทำให้สร้างเลขใหม่เรื่อย ๆ และดัน `transactionCounter` ขึ้นโดยไม่มีธุรกรรมจริง
   → เก็บ `lastScannedRefNo` ไว้ตอนประมวลผลแล้วนำมาแสดง
2. **ชื่อที่มีลูกน้ำทำข้อมูลเพี้ยน** — `students.csv` และ `daily_log.csv` เขียนแบบไม่ครอบเครื่องหมายคำพูด
   → เพิ่ม `csvQuote()` / `parseCsvLine()` ใช้ทั้งการเขียน อ่าน นำเข้า และส่งออก
   (ยังอ่านไฟล์รุ่นเก่าที่ไม่มีเครื่องหมายคำพูดได้)
3. **ดาวน์โหลดไฟล์นอกคลังประวัติได้** — `/api/archive/download` ไม่กรองชื่อไฟล์
   จึงโหลด `/admins.json` ที่เก็บรหัสผ่านได้ → เพิ่ม `isSafeArchiveName()` บังคับ `arc_*.csv`
4. **Session token เดาได้** — `random()` ไม่เคยถูก seed → เปลี่ยนไปใช้ `esp_random()` 128 บิต
5. **Session หมดอายุผิดพลาดที่ 49 วัน** — เทียบ `millis() < expiry` ตรง ๆ → เปลี่ยนเป็นการเทียบแบบ wrap-safe
6. **คุกกี้ไม่มี SameSite** → เพิ่ม `SameSite=Strict; Max-Age=7200` และล้าง session ฝั่งเซิร์ฟเวอร์ตอน logout
7. **คำสั่งทำลายข้อมูลเป็น GET** — `/reset`, `/api/student/delete`, `/manual-claim`, `/bind-temp`,
   `/api/tempcard/remove`, `/api/archive/delete` → ย้ายเป็น POST ทั้งหมด
8. **ชื่อนิสิตที่มี `'` `"` `<` ทำตารางพัง (XSS)** — ตารางถูกประกอบด้วย `innerHTML` และ `onclick`
   ที่ฝังค่าลงในสตริง JavaScript → สร้างแถวด้วย DOM/`textContent` และใช้ `data-attribute`
   สำหรับปุ่มที่เรนเดอร์จากฝั่งเซิร์ฟเวอร์ พร้อม `htmlEscape()` ทุกจุดที่ยังต้องต่อสตริง HTML
9. **`limit` ไม่มีเพดาน** — `/api/students?limit=1000` ทำให้ `DynamicJsonDocument(8192)` ล้น
   จน JSON ที่ส่งกลับไม่สมบูรณ์ → จำกัดที่ 100 และปรับขนาดเอกสารตามจำนวนที่ขอจริง
10. **ไม่มีการจำกัดการเดารหัสผ่าน** → พิมพ์ผิด 5 ครั้งติดกันล็อก 1 นาที
11. **`/api/system/health` เปิดให้เข้าถึงโดยไม่ต้องเข้าสู่ระบบ** → บังคับยืนยันตัวตน
12. **`readHostBatteryVoltage()` บล็อก 16 ms ทุกครั้งที่วาดแถบบน** → แคช 3 วินาที และเลิกใช้ `delay()`
13. **แบนเนอร์ผลสแกนล้นจอ** เหมือนฝั่งสถานี → ย่อฟอนต์อัตโนมัติ
14. **`File root` ไม่ถูกปิด** หลังไล่รายการไฟล์ประวัติ → ปิดแล้ว
15. **ไม่มีการตรวจข้อมูลขาเข้า** — เพิ่มการตรวจรหัสนิสิตซ้ำ, เลขบัตรซ้ำ, ความยาวฟิลด์,
    ความถูกต้องของวันที่/เวลา และช่วงเวลาเปิด-ปิดบริการ
16. **แก้ไข UID ของนิสิตที่ถือบัตรสำรองอยู่แล้วไปทับบัตรชั่วคราว** → เขียนลง `originalUid` แทน
17. **ธีมถูกส่งซ้ำทุก heartbeat** — เมื่อฝั่งสถานีรับ `MSG_CONFIG` ได้แล้ว การส่งซ้ำจะไปทับ
    ธีมที่ผู้ใช้กดเองที่หน้าเครื่องสถานี → ส่งเฉพาะตอนสถานีเพิ่งออนไลน์หรือเจ้าหน้าที่สั่งเอง
18. รูปแบบ `%d` กับ `size_t` / `uint32_t` หลายจุด → แก้เป็น `%u` พร้อม cast

---

### เว็บพอร์ทัล — สิ่งที่ปรับปรุง

- **เลิกใช้ `alert()`** ที่บังคับรีโหลดทั้งหน้าและทำให้เสียแท็บที่ค้างอยู่ → ทุกคำสั่งส่งแบบ AJAX
  และแจ้งผลด้วย toast มุมขวาล่าง พร้อมสถานะ "กำลังบันทึก..." บนปุ่ม
- **แดชบอร์ดสด** — ดึง `/api/dashboard` ทุก 3 วินาที อัปเดตเกจโควตา ยอดจัดสรร อุณหภูมิ CPU
  แบตเตอรี่ นาฬิกา ป้ายสถานะเปิด/ปิดบริการ กราฟรายร้าน และการ์ดจุดบริการทั้ง 4 จุด
  (ออนไลน์/ออฟไลน์, แท่งสัญญาณ, RSSI, แบตเตอรี่, เวลาที่ได้ยินล่าสุด)
- **ตารางรายชื่อ** — หัวตารางตรึงขณะเลื่อน, skeleton ระหว่างโหลด, แถบไฮไลต์เมื่อชี้,
  ตัวเลขหน้าแสดงเป็น "หน้า/ทั้งหมด", ปุ่มมี tooltip อธิบายทุกปุ่ม
- **เลิกใช้ `prompt()`** สำหรับผูกบัตรสำรองและตัดสิทธิ์ด้วยตนเอง → เปลี่ยนเป็น modal
  ที่มี dropdown เลือกจุดบริการ ปิดได้ด้วยปุ่ม Esc หรือคลิกพื้นหลัง
- จำแท็บที่เปิดค้างไว้ และกลับมาที่แท็บเดิมหลังบันทึกข้อมูล

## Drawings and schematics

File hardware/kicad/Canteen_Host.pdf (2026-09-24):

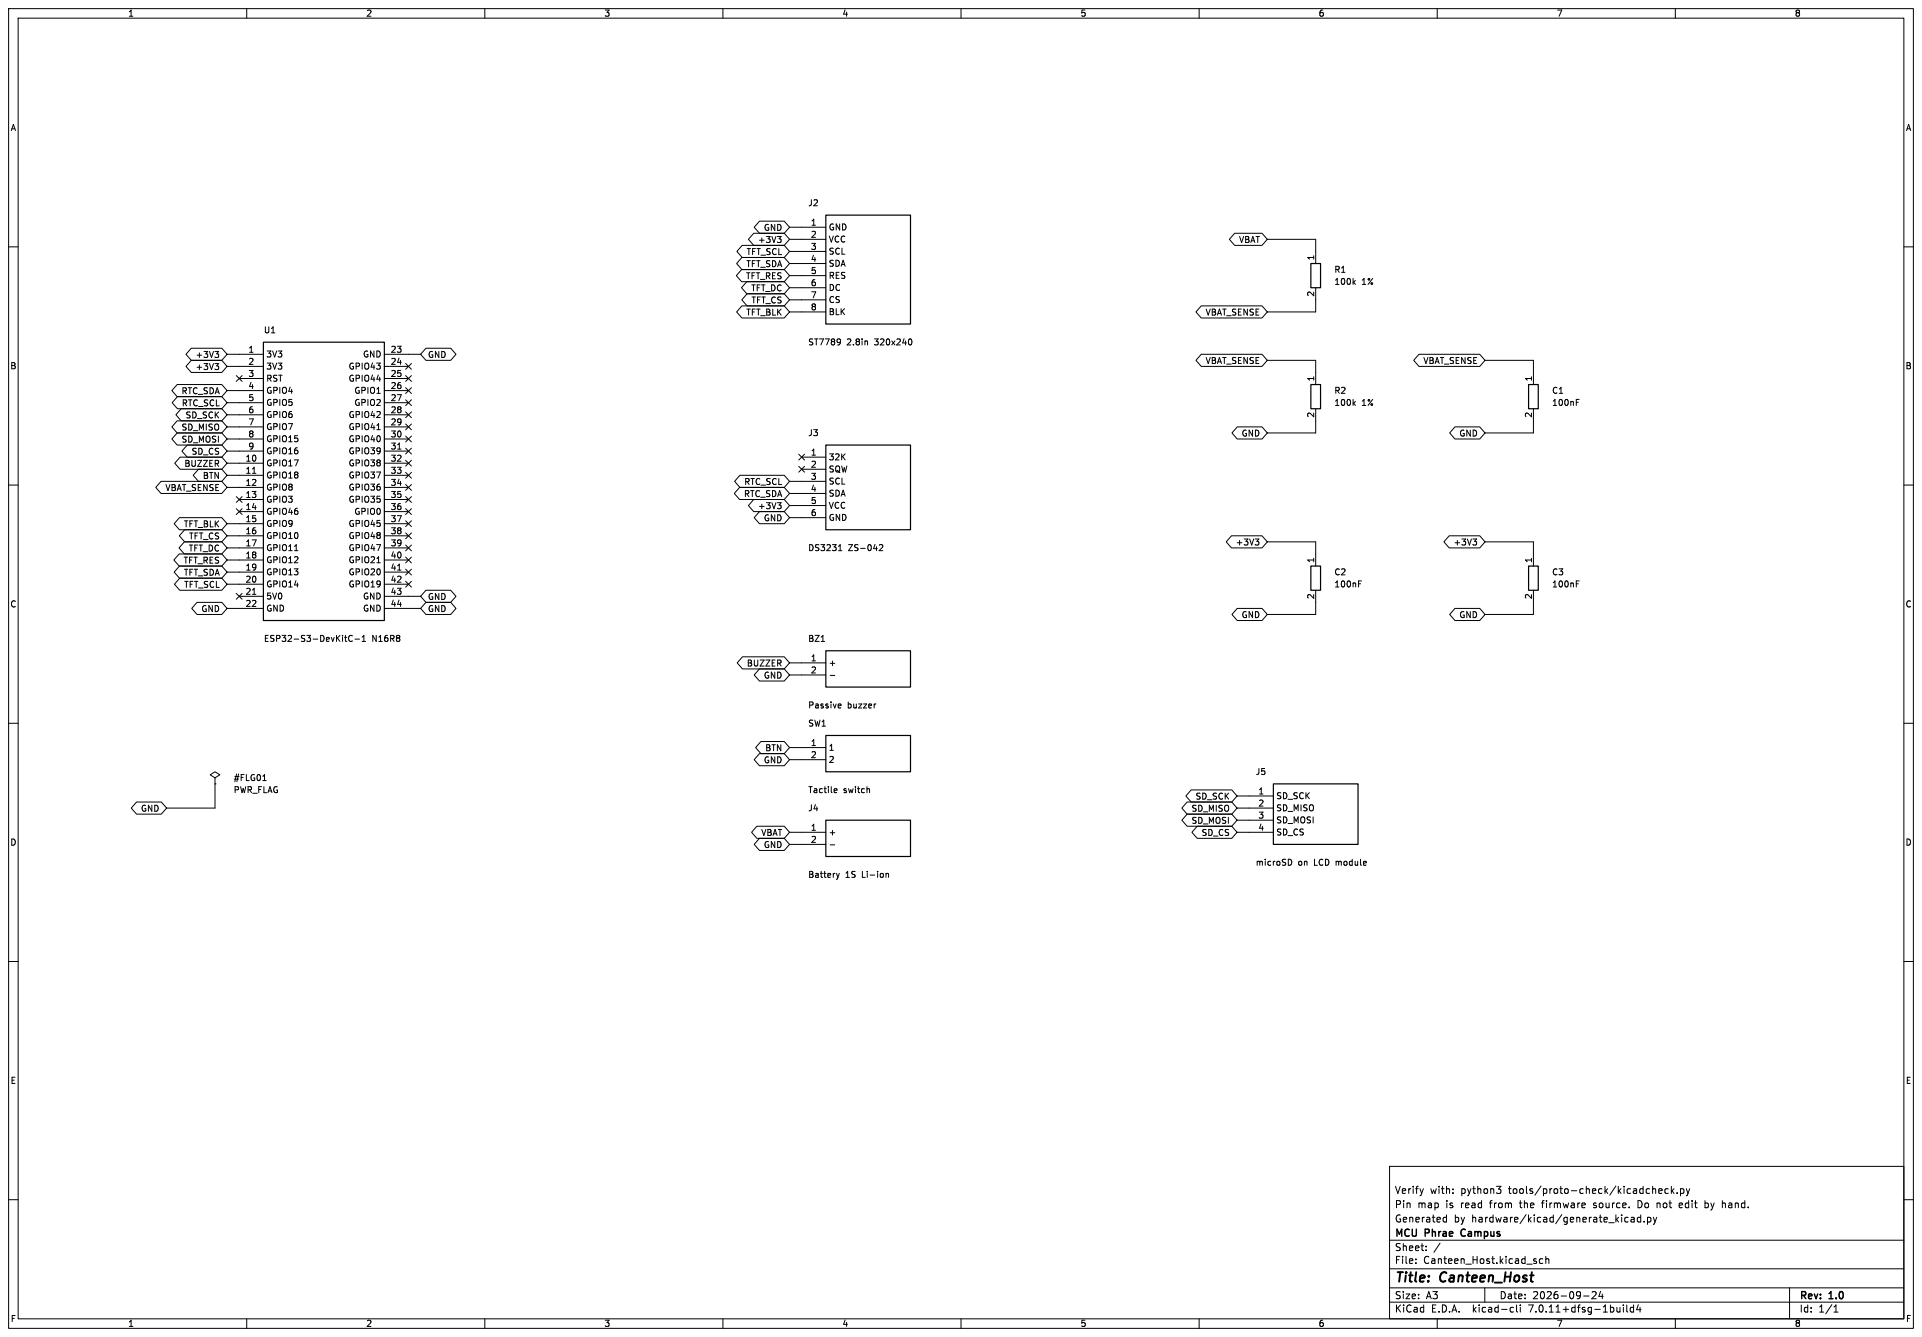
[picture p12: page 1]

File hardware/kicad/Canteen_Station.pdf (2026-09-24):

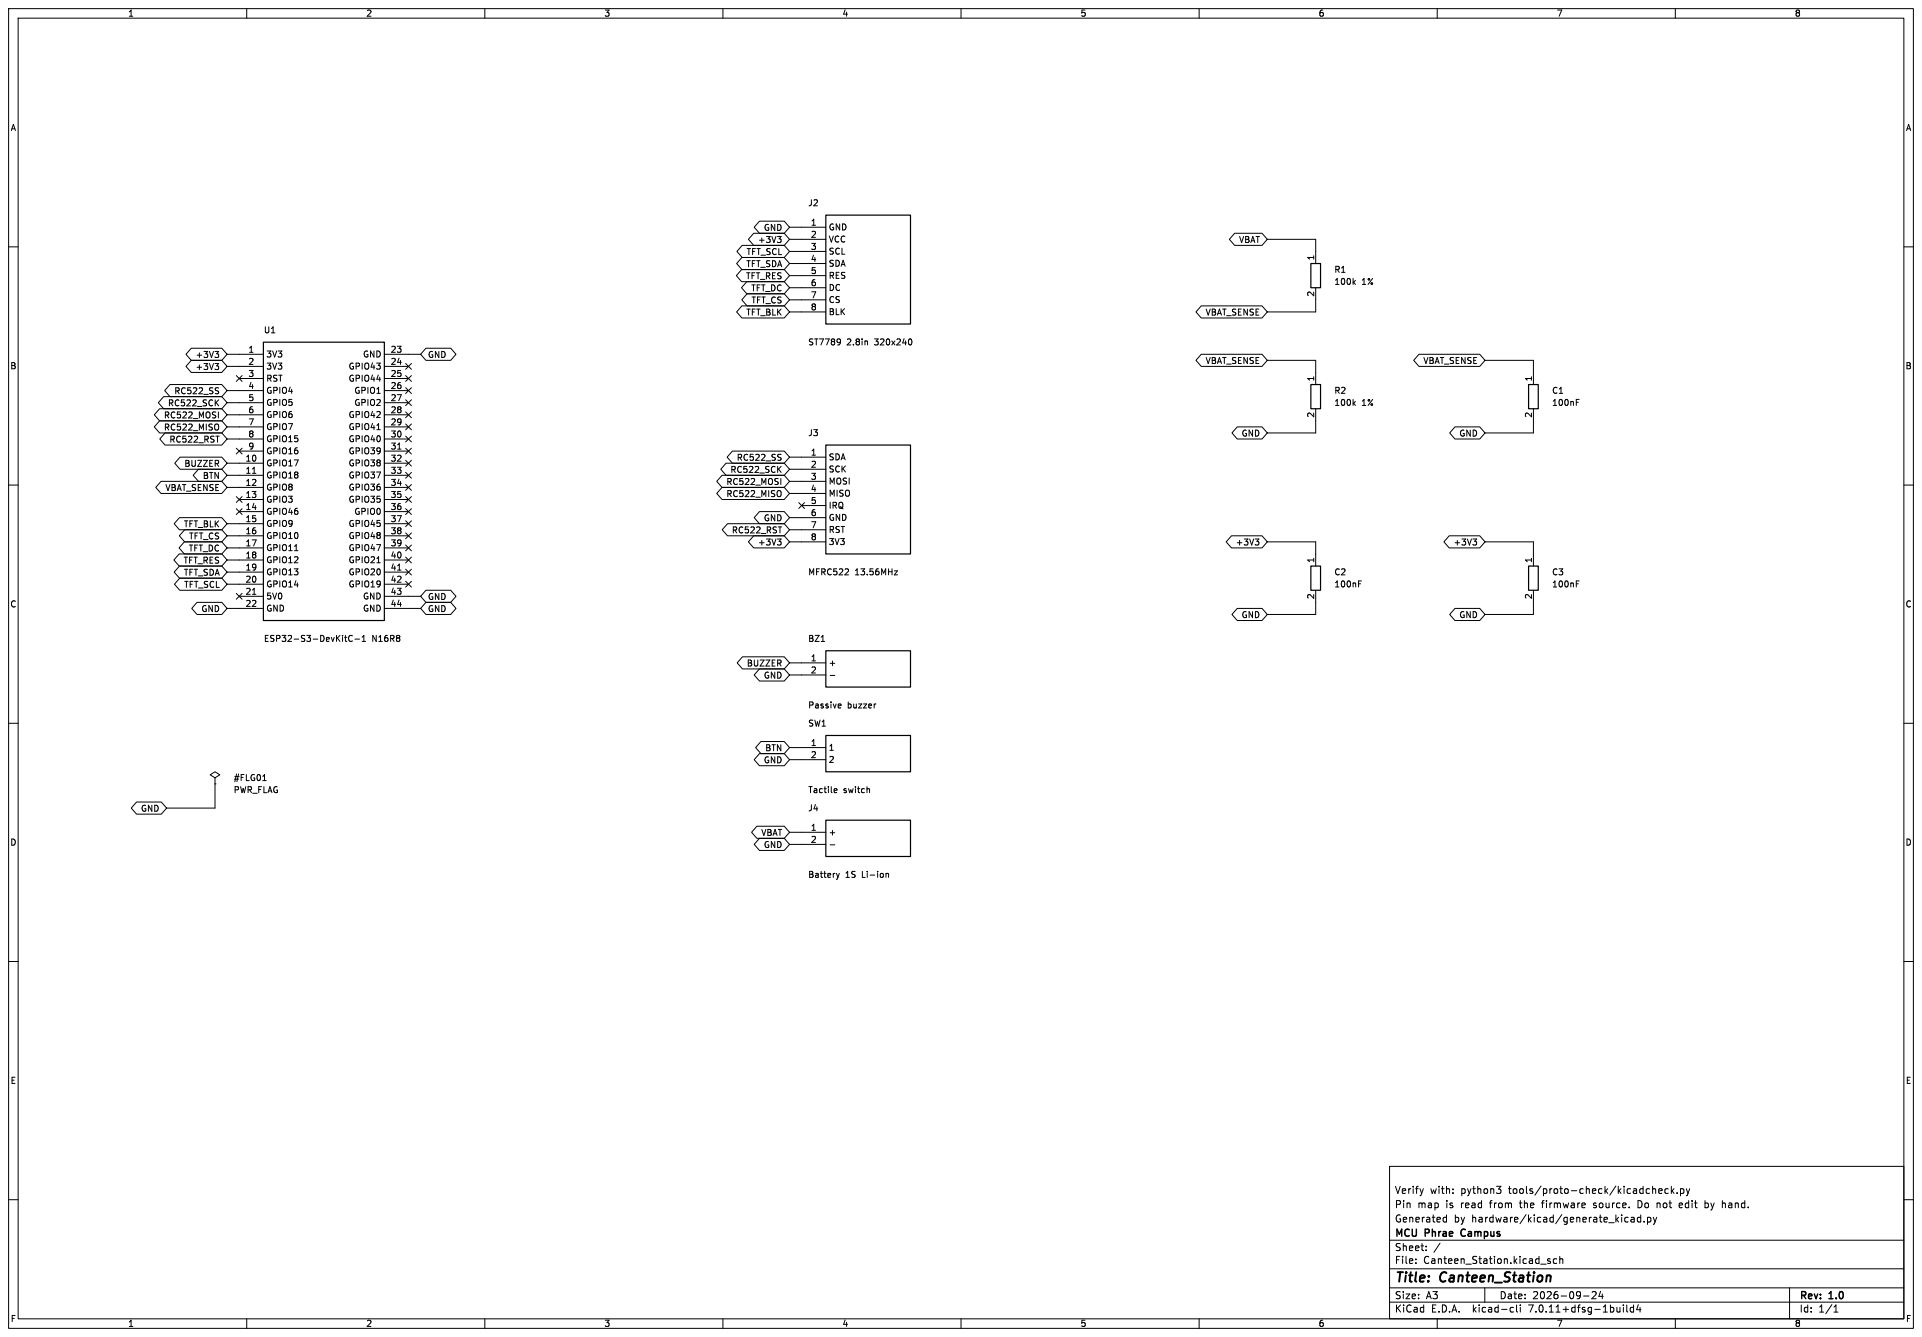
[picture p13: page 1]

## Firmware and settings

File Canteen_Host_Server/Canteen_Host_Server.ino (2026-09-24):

/**
 * @file      Canteen_Host_Server.ino
 * @brief     เครื่องแม่ข่ายของระบบสวัสดิการอาหารกลางวัน 35 บาท/คน/วัน
 * @version   113.12.0
 * @date      2026-09-23
 * @author    Kittiphan Rattanakorn <kittiphun.rut@mcu.ac.th>
 *
 * @par Organization
 * มหาวิทยาลัยมหาจุฬาลงกรณราชวิทยาลัย วิทยาเขตแพร่
 *
 * @par Description
 * ถือฐานข้อมูลนิสิตทั้งหมด ตัดสินสิทธิ์ทุกครั้งที่มีคนแตะบัตรที่จุดบริการ
 * บันทึกประวัติลง LittleFS และเปิดเว็บให้เจ้าหน้าที่จัดการข้อมูล
 * คุยกับจุดบริการทั้งสี่จุดผ่าน ESP-NOW ช่อง 1
 *
 * ไฟล์นี้เก็บเฉพาะตรรกะระบบ ส่วนที่วาดลงจอและหน้าเว็บถูกแยกออกไปเป็น
 * HostScreen.h กับ WebDashboard.h ซึ่ง #include ไว้ท้ายไฟล์ก่อน setup()
 *
 * @par Hardware
 * ESP32-S3 DevKitC-1 (N16R8) · จอ ST7789V 2.8" 320x240 บนบัส FSPI ·
 * นาฬิกา DS3231 บน I2C · บัซเซอร์ GPIO 6 · ปุ่มกด GPIO 2 · WS2812 GPIO 48
 *
 * @par Dependencies
 * Adafruit GFX · Adafruit ST7735/ST7789 · ArduinoJson v6 · RTClib ·
 * Arduino ESP32 core 2.x หรือ 3.x
 *
 * @par Build Settings (Arduino IDE)
 * Board: ESP32S3 Dev Module · Flash: 16MB · PSRAM: OPI ·
 * Partition: Huge APP (3MB No OTA/1MB SPIFFS)
 *
 * @par Revision History
 * | Version | Date | Change |
 * |---|---|---|
 * | 113.12.0 | 2026-09-24 | ย้ายการ์ด SD ไปอยู่บัส SPI ของตัวเอง (HSPI) ไม่ใช้ร่วมกับจอ สี่ขาเรียงติดกันที่ตำแหน่ง 6 ถึง 9 เดินสายหนึ่งต่อหนึ่งไม่ต้องแยกสาย และคืนบัสของจอให้เป็นสายขาออกอย่างเดียวเหมือนเดิม |
 * | 113.11.0 | 2026-09-24 | บันทึกสำเนาลงการ์ด SD ที่อยู่หลังโมดูลจอ ทั้งรายการประจำวัน ไฟล์ปิดยอด และทะเบียนนิสิต LittleFS ยังเป็นที่เก็บหลัก ไม่มีการ์ดก็ทำงานได้ครบ ใช้บัส SPI ร่วมกับจอ เพิ่มขา SD_MISO ที่ GPIO6 และ SD_CS ที่ GPIO7 |
 * | 113.10.0 | 2026-09-24 | จัดขาใหม่ทั้งบอร์ดให้สายไม่ไขว้กัน อุปกรณ์ทุกตัวอยู่บนแถวซ้ายแถวเดียว ย้ายบัซเซอร์ไป GPIO17 ปุ่มกดไป GPIO18 วัดแบตเตอรี่ไป GPIO8 และไฟหน้าจอไป GPIO9 |
 * | 113.9.0 | 2026-09-23 | ย้ำคำสั่งการแสดงผลหกรอบกระจายออกไปราวสองวินาทีโดยไม่หน่วงลูป แทนการย้ำสามรอบติดกันด้วย delay(30) หน้าเว็บจึงตอบกลับทันที |
 * | 113.8.0 | 2026-09-23 | ตามการเปลี่ยนคำของ HostScreen.h และ WebDashboard.h ตรรกะในไฟล์นี้ไม่เปลี่ยน |
 * | 113.7.0 | 2026-09-23 | คำสั่งเปลี่ยนโหมดการแสดงผลไปถึงจุดบริการทันที ส่งยูนิแคสต์ถึงทุกจุดก่อนแล้วค่อยกระจายเสียง และแก้ broadcastStationTheme() ที่ประกอบแพ็กเก็ตเองจนฟิลด์ screenOn, screensaver, modeSeq เป็นศูนย์ติดไปทุกครั้ง |
 * | 113.6.0 | 2026-09-23 | เพิ่มจอสาธารณะสำหรับทีวีในโรงอาหาร /display กับ /api/board เปิดดูได้โดยไม่ต้องเข้าสู่ระบบ ปิดบังรหัสนิสิตเหลือห้าหลักแรก ไม่มีชื่อ ไม่มีหมายเลขบัตร ไม่มีเลขอ้างอิง และไม่มีข้อมูลฮาร์ดแวร์ |
 * | 113.5.0 | 2026-09-23 | ตามการจัดตำแหน่งตัวอักษรของ HostScreen.h ตรรกะในไฟล์นี้ไม่เปลี่ยน |
 * | 113.4.0 | 2026-09-23 | เพิ่มชื่อร้านสำหรับขึ้นจอ (ภาษาอังกฤษ) แยกจากชื่อจริงที่ใช้บนเว็บ |
 * | 113.3.0 | 2026-09-22 | ตามการแก้เรื่องกะพริบของ HostScreen.h ตรรกะในไฟล์นี้ไม่เปลี่ยน |
 * | 113.2.0 | 2026-09-22 | รีเฟรชหน้าจอทุกหน้า ไม่ใช่แค่สองหน้าแรก หน้า SYSTEM จึงไม่ค้างอีกต่อไป |
 * | 113.1.0 | 2026-09-22 | หน้าเว็บเป็นสองภาษา ไทย/อังกฤษ และเสิร์ฟสคริปต์พร้อม charset |
 * | 113.0.0 | 2026-09-22 | เริ่มใหม่จากต้นฉบับ แยกไฟล์จอและเว็บออกมา คุมการแสดงผลของทุกจุดบริการ เพิ่ม /api/dashboard เปลี่ยนเส้นทางที่แก้ข้อมูลเป็น POST ซ่อม CSV โทเคนเซสชัน และเลขอ้างอิงบนจอ |
 * | 107.0.1 | 2026-09-21 | ต้นฉบับที่ใช้เป็นจุดเริ่ม เก็บสำเนาไว้ที่ original/ |
 *
 * @warning  #include ของ HostScreen.h และ WebDashboard.h ต้องอยู่ท้ายไฟล์ก่อน setup()
 *           เพราะโค้ดข้างในอ้างถึงตัวแปรส่วนกลางข้างบน ย้ายขึ้นไปบนสุดแล้วคอมไพล์ไม่ผ่าน
 * @warning  Partition Scheme ต้องลงท้ายด้วย SPIFFS เท่านั้น ถ้าเลือกแบบ FATFS
 *           LittleFS จะเมานต์ไม่ขึ้นและฐานข้อมูลนิสิตทั้งหมดหายไป
 * @note     รหัสผ่านเจ้าหน้าที่เก็บเป็นข้อความธรรมดาใน /admins.json
 *           เครื่องนี้จึงควรอยู่ในพื้นที่ควบคุม
 */

#include <WiFi.h>
#include <esp_now.h>
#include <esp_wifi.h>
#include <WebServer.h>
#include <DNSServer.h>
#include <LittleFS.h>
#include <SD.h>
#include <Preferences.h>
#include <ArduinoJson.h>
#include <ESPmDNS.h>
#include <Adafruit_GFX.h>
#include <Adafruit_ST7789.h>
#include <SPI.h>
#include <Wire.h>
#include <RTClib.h>

#define APP_VERSION         "113.12.0"
#define DEV_NAME            "Kittiphan Rattanakorn"
#define DEV_ROLE            "Computer Technical Officer"
#define DEV_INSTITUTION     "MCU Phrae Campus"

// ============================================================================
// การจัดขา (Pin Map) — ESP32-S3 DevKitC-1 N16R8
// ============================================================================
// [113.10.0] แก้: จัดขาใหม่ทั้งหมดให้สายไม่ไขว้กัน
//           อุปกรณ์ภายนอก **ทุกตัวอยู่บนแถวซ้ายของบอร์ดแถวเดียว** ไม่มีอะไรข้ามไปฝั่งขวา
//           และขาของแต่ละโมดูลเรียงติดกันตามลำดับขาบนตัวโมดูลเอง
//           รายละเอียดและผังเต็มอยู่ใน docs/HARDWARE.md
//
//   ตำแหน่ง   ขา        เครื่องแม่ข่าย
//   --------  --------  ----------------------------------------------------
//    1, 2     3V3       ไฟเลี้ยง 3.3V ของทุกโมดูล
//    3        RST       ปุ่มรีเซ็ตของบอร์ด ห้ามต่ออะไร
//    4        GPIO4     DS3231  SDA
//    5        GPIO5     DS3231  SCL
//    6        GPIO6     การ์ด SD  SD_SCK    (หัวต่อด้านหลังโมดูลจอ)
//    7        GPIO7     การ์ด SD  SD_MISO
//    8        GPIO15    การ์ด SD  SD_MOSI
//    9        GPIO16    การ์ด SD  SD_CS
//   10        GPIO17    บัซเซอร์
//   11        GPIO18    ปุ่มกด (INPUT_PULLUP)
//   12        GPIO8     วัดแรงดันแบตเตอรี่ (ADC1_CH7)
//   13,14     GPIO3,46  ไม่ใช้ เป็นขา strapping
//   15        GPIO9     TFT  BLK
//   16        GPIO10    TFT  CS
//   17        GPIO11    TFT  DC
//   18        GPIO12    TFT  RES
//   19        GPIO13    TFT  SDA (MOSI)
//   20        GPIO14    TFT  SCL (SCLK)
//   21        5V0       ไม่ได้ใช้
//   22        GND       กราวด์ร่วมของทุกโมดูล
//
// แถวขวาไม่ได้ต่อสายอะไรเลย เหลือไว้ทั้งแถว
// ขาที่ห้ามใช้บนรุ่น N16R8: GPIO26-37 (แฟลชกับ PSRAM แบบ OPI),
// GPIO19/20 (USB), GPIO43/44 (UART0), GPIO0/3/45/46 (strapping)

// จอ ST7789 — หกขาเรียงติดกันที่ตำแหน่ง 15 ถึง 20
// เรียงตรงกับลำดับขาบนตัวโมดูลพอดี อ่านจากล่างขึ้นบน
// GND, VCC, SCL, SDA, RES, DC, CS, BLK จึงเสียบตรงลงมาได้โดยไม่ไขว้เลย
#define TFT_BLK             9
#define TFT_CS              10
#define TFT_DC              11
#define TFT_RST             12
#define TFT_MOSI            13
#define TFT_SCLK            14

// DS3231 บน I2C — สองขาติดกันที่ตำแหน่ง 4 และ 5 ใกล้ขา 3V3 ด้านบน
#define I2C_SDA_PIN         4
#define I2C_SCL_PIN         5

// การ์ด SD ที่อยู่ด้านหลังโมดูลจอ — สี่ขาเรียงติดกันที่ตำแหน่ง 6 ถึง 9
// โมดูลจอมีหัวต่อของการ์ดแยกไว้อีกชุดหนึ่งที่ขอบขวาของบอร์ด คือ
// SD_SCK, SD_MISO, SD_MOSI, SD_CS ไม่ได้ต่อกับหัวแถว SPI ของจอ ต้องเดินสายเอง
// ลำดับขาข้างล่างตรงกับลำดับบนตัวโมดูลพอดี เสียบตรงลงมาได้โดยไม่ไขว้
//
// [113.12.0] แก้: ย้ายการ์ดมาอยู่บัส SPI ของตัวเอง (HSPI) ไม่ใช้ร่วมกับจออีกแล้ว
//
//   ทั้งสองแบบใช้งานได้จริงและการแชร์บัสก็เป็นวิธีมาตรฐาน แต่เหตุผลที่แยก
//   1. **เดินสายง่ายกว่า** การแชร์บัสต้องเอาสายสองเส้นยัดเข้าหัวต่อเดียวกัน
//      ที่ GPIO13 กับ GPIO14 ซึ่งเป็นจุดที่หลุดง่ายที่สุดในงานประกอบด้วยมือ
//      แบบแยกคือสี่สายไปสี่ขาที่เรียงติดกัน หนึ่งต่อหนึ่ง
//   2. **สายหลุดเส้นเดียวไม่ดับทั้งคู่** ถ้าแชร์บัสแล้ว SCK หลุด จอกับการ์ดดับพร้อมกัน
//   3. **บัสของจอสะอาดเหมือนเดิม** ไลบรารี ST77xx ตั้งความเร็วไว้ที่ 32 MHz
//      การแตกแขนงสายเพิ่มที่ความถี่นั้นทำให้สัญญาณแย่ลง
//
//   ที่ทำได้เพราะแม่ข่ายใช้ SPI แค่ตัวเดียวคือ FSPI ส่วน HSPI ว่างสนิท
//   และขาตำแหน่ง 8 กับ 9 ก็ว่างอยู่พอดี เหตุผลที่ตำราส่วนใหญ่ให้แชร์บัส
//   คือบอร์ดอย่าง Arduino Uno มีขาไม่พอ ซึ่งไม่ใช่ข้อจำกัดของบอร์ดนี้
#define SD_SCK_PIN          6
#define SD_MISO_PIN         7
#define SD_MOSI_PIN         15
#define SD_CS_PIN           16

// อุปกรณ์สายเดี่ยว — สามขาติดกันที่ตำแหน่ง 10 ถึง 12
// ชุดนี้ใช้ขาเดียวกับฝั่งจุดบริการเป๊ะ สายชุดเดียวใช้ได้ทั้งสองบอร์ด
#define BUZZER_PIN          17
#define BTN_PIN             18
#define BATTERY_ADC_PIN     8   // ADC1_CH7 อ่านได้ขณะเปิด Wi-Fi

#define RGB_LED_PIN         48  // WS2812 บนบอร์ด ไม่ต้องเดินสาย

// ============================================================================
// COLOR MACROS & THEME ENGINE
// ============================================================================
#define BENTO_BG            0x0000
#define BENTO_CARD_BG       0x10A4
#define BENTO_CARD_BORDER   0x2965
#define BENTO_NEON_GREEN    0x07E0
#define BENTO_NEON_CYAN     0x07FF
#define BENTO_NEON_YELLOW   0xFFE0
#define BENTO_NEON_ROSE     0xF800  // สีแดงแท้ (Pure Red)
#define BENTO_TEXT_MUTED    0x8410
#define BENTO_WHITE         0xFFFF

#ifndef ST77XX_NAVY
  #define ST77XX_NAVY       0x000F
#endif
#ifndef ST77XX_DARKGREY
  #define ST77XX_DARKGREY   0x2124
#endif
#ifndef ST77XX_DARKGREEN
  #define ST77XX_DARKGREEN  0x03E0
#endif
#ifndef ST77XX_LIGHTGREY
  #define ST77XX_LIGHTGREY  0xC618
#endif
#ifndef ST77XX_ORANGE
  #define ST77XX_ORANGE     0xFD20
#endif

bool isTftDarkMode = true;

uint16_t getTftBg()          { return isTftDarkMode ? BENTO_BG : 0xF7BF; }
uint16_t getTftCardBg()      { return isTftDarkMode ? BENTO_CARD_BG : BENTO_WHITE; }
uint16_t getTftCardBorder()  { return isTftDarkMode ? BENTO_CARD_BORDER : 0xCE79; }
uint16_t getTftTextMain()    { return isTftDarkMode ? BENTO_WHITE : 0x0841; }
uint16_t getTftTextMuted()   { return isTftDarkMode ? BENTO_TEXT_MUTED : 0x632C; }
uint16_t getTftAccentGreen() { return isTftDarkMode ? BENTO_NEON_GREEN : 0x04A6; }
uint16_t getTftAccentCyan()  { return isTftDarkMode ? BENTO_NEON_CYAN : 0x0318; }
uint16_t getTftAccentYellow(){ return isTftDarkMode ? BENTO_NEON_YELLOW : 0xCBA0; }
uint16_t getTftAccentRose()  { return isTftDarkMode ? BENTO_NEON_ROSE : 0xD800; }

SPIClass SPI_TFT(FSPI);
// [113.12.0] เพิ่ม: การ์ด SD อยู่บนบัสของตัวเอง ไม่ยุ่งกับบัสของจอเลย
SPIClass SPI_SD(HSPI);
Adafruit_ST7789 tft = Adafruit_ST7789(&SPI_TFT, TFT_CS, TFT_DC, TFT_RST);
RTC_DS3231 rtc;

WebServer server(80);
DNSServer dnsServer;
Preferences preferences;

const byte DNS_PORT = 53;
const char* default_ap_ssid = "MCU_CANTEEN_HOST";
const char* default_ap_pass = "12345678";
const char* mdns_hostname   = "canteen";

uint8_t broadcastAddress[]   = {0xFF, 0xFF, 0xFF, 0xFF, 0xFF, 0xFF};
const uint8_t ESPNOW_CHANNEL = 1;

bool timeWindowEnabled = true;
int serviceStartHour   = 10;
int serviceStartMin    = 0;
int serviceEndHour     = 13;
int serviceEndMin      = 30;

struct AdminUser {
  String username;
  String password;
  String displayName;
};
std::vector<AdminUser> adminUsers;

struct ActiveSession {
  String token;
  String username;
  unsigned long expiry;
};
ActiveSession activeSessions[3];

enum MsgType : uint8_t { MSG_HEARTBEAT = 1, MSG_SCAN_REQ = 2, MSG_SCAN_RESP = 3, MSG_CONFIG = 4 };

#define ESPNOW_PROTO_MAGIC 0xCA
#define ESPNOW_PROTO_VER   2

typedef struct __attribute__((packed)) {
  uint8_t magic;
  uint8_t version;
  uint8_t msgType;
  uint8_t stationId;
  uint16_t seq;
  char uid[16];
  char offlineTime[24];
  float systemVoltage;
} StationPacket;

typedef struct __attribute__((packed)) {
  uint8_t magic;
  uint8_t version;
  uint8_t msgType;
  uint8_t stationId;
  uint16_t seq;
  char status[16];
  char studentId[16];
  char name[64];
  char refNo[36];
  char claimTime[24];
  char message[32];
  int amount;
  uint16_t servedCount;
} HostResponsePacket;

// คำสั่งการแสดงผลที่แม่ข่ายสั่งลงไปยังสถานี — แม่ข่ายเป็นผู้กำหนดฝ่ายเดียว
//   darkMode    โหมดมืด/สว่าง บังคับเสมอ
//   screenOn    เปิด/ปิดไฟหน้าจอของสถานี
//   screensaver สั่งเข้า/ออกโหมดพักหน้าจอ
//   modeSeq     เพิ่มขึ้นทุกครั้งที่ค่าเปลี่ยน สถานีใช้กันการทำคำสั่งเดิมซ้ำ
typedef struct __attribute__((packed)) {
  uint8_t magic;
  uint8_t version;
  uint8_t msgType;
  uint8_t stationId;   // 0 = ทุกสถานี
  uint8_t darkMode;
  uint8_t screenOn;
  uint8_t screensaver;
  uint8_t modeSeq;
} HostConfigPacket;
static_assert(sizeof(StationPacket) == 50, "StationPacket size mismatch");
static_assert(sizeof(HostResponsePacket) == 200, "HostResponsePacket size mismatch");
static_assert(sizeof(HostConfigPacket) == 8, "HostConfigPacket size mismatch");

struct StationNode {
  bool isOnline = false;
  int rssi = -100;
  float systemVoltage = 0.0;
  unsigned long lastSeen = 0;
  uint8_t mac[6] = {0};
};
StationNode stationNodes[4];
bool stationPeerReady[4] = {false, false, false, false};
volatile bool hbAckPending[4] = {false, false, false, false};

uint16_t lastScanSeq[4] = {0, 0, 0, 0};
bool hasLastScanSeq[4] = {false, false, false, false};
HostResponsePacket lastScanResponse[4] = {};

struct Student {
  String studentId;
  String fullName;
  String uid;
  String originalUid;
  bool claimed;
  String claimTime;
  String refNo;
  int station;
  bool isTempCard;
};

// [113.4.0] เพิ่ม: screen คือชื่อสั้น ๆ ภาษาอังกฤษสำหรับขึ้นบนจอ TFT
//           เพราะฟอนต์ในตัวของจอไม่มีตัวอักษรไทย ชื่อไทยจะกลายเป็นสัญลักษณ์มั่ว
//           ส่วน name ยังเป็นชื่อจริงภาษาไทยที่ใช้บนหน้าเว็บและในไฟล์รายงาน
struct Shop {
  String name;
  String vendor;
  String screen;
};

std::vector<Student> db;
// ช่องที่สามคือชื่อสำหรับขึ้นจอ TFT ต้องเป็นภาษาอังกฤษเท่านั้น
// ค่าเริ่มต้นเดิมมีแต่ชื่อไทย พอขึ้นจอจึงกลายเป็นสัญลักษณ์มั่วตั้งแต่ยังไม่ได้ตั้งค่าอะไร
Shop shops[4] = {
  {"ร้านที่ 1", "นางสาวณัฐกฤตา สุพิทิพย์", "Shop 1"},
  {"ร้านที่ 2", "นางสาวปียาวัน เหมืองหม้อ", "Shop 2"},
  {"ร้านที่ 3", "นางฉวีวรรณ วงศ์นาม",       "Shop 3"},
  {"ร้านที่ 4", "น.ส.พัชรินทร์ ชำนาญใช้",   "Shop 4"}
};

// ============================================================================
// Forward Declarations
// ============================================================================
#if ESP_ARDUINO_VERSION_MAJOR >= 3
void onDataRecv(const esp_now_recv_info_t *recv_info, const uint8_t *data, int len);
#else
void onDataRecv(const uint8_t *mac, const uint8_t *data, int len);
#endif

void renderHostPage(bool fullRedraw);
void renderScreensaver(bool fullRedraw);
void renderDeveloperCredit();
void displayHostLiveScan(String uid, String studentId, String status, int stId);
void playBootAnimation();
String getLoginHTML(bool hasError = false);
String getHTML();
void sendAlert(String message, String redirectUrl = "/");
void saveDatabaseToFS();
void loadDatabaseFromFS();
void saveAdminsToFS();
void loadAdminsFromFS();
void saveShopsToFS();
void loadShopsFromFS();
void restoreDailyLogs();
void appendLogToFS(String studentId, String fullName, String uid, String refNo, String timestamp, int station, String type);
bool isAuthenticated();
void redirectToLogin();
String generateSessionToken();
String generateRefNo(int stationId);
void processScanRequest(const uint8_t* mac, StationPacket pkt, int rssi);
float calculateCpuLoad();
float getChipTemperature();
float readHostBatteryVoltage();
int getHostBatteryPercentage(float voltage);
void drawBentoCard(int x, int y, int w, int h, uint16_t borderColor, uint16_t bgColor);
void drawBentoPillBadge(int x, int y, int w, int h, const char* text, uint16_t fgColor, uint16_t bgColor);
void drawHostBatteryHUD(int x, int y);
void drawMiniBattery(int x, int y, int pct);
void drawHostTopBar(String title, int pageNo = 0);
void drawBentoBottomBar(String instruction);
String maskUID(String uid);
uint16_t getStationServedCount(uint8_t stationId);
String getRealTimeStr();
String getDateFormattedStr();
String getTimeOnlyStr();
bool isWithinServiceTime();
bool ensureStationPeer(uint8_t stationId);
bool sendToStation(uint8_t stationId, const uint8_t *data, size_t len);
void sendStationTheme(uint8_t stationId);
// ต้องประกาศตรงนี้ (หลังนิยาม HostConfigPacket) ไม่งั้น Arduino IDE จะสร้าง
// ต้นแบบฟังก์ชันให้เองแล้ววางไว้เหนือจุดที่นิยามโครงสร้าง คอมไพล์ไม่ผ่านทันที
void fillStationConfig(HostConfigPacket &cfg, uint8_t stationId);
void broadcastStationTheme();
void announceDisplayMode();
String jsonEscape(const String &raw);
void handleDashboardAPI();
void handlePublicBoard();
void handleSetDisplayMode();
void setLedColor(uint8_t r, uint8_t g, uint8_t b);
void ledStandby();
void ledApproved();
void ledDuplicate();
void ledRejected();
void ledOff();
void soundWelcome();
void soundCreditJingle();
void soundBeep();
void soundScreensaverBeep();
void soundHomeBeep();
void soundScanSuccess();
void soundThemeSwitch();
void mergeImportedStudents();
void handleFileUpload();
void handleGetStudentsAPI();
String csvField(const String &raw);
void handleExportCSV();
void handleSetRTCTime();
void handleDownloadArchive();
void handleDeleteArchive();
void handleSaveStudent();
void handleSaveTempCard();
void handleRemoveTempCard();
void handleDeleteStudent();
void handleSaveAdmin();
void handleDeleteAdmin();
void pushPublicFeed(const String &studentId, const String &claimTime, int shop);
void showBootNetworkStatus();
void handleHostButton();

struct ScanQueueItem {
  uint8_t mac[6];
  StationPacket pkt;
  int rssi;
};
QueueHandle_t scanQueue = NULL;

File fsUploadFile;
String lastScannedUID       = "-";
String lastScannedStudentId = "-";
int lastScannedStation      = 0;
String lastScannedStatus    = "READY";
// [113.6.0] เพิ่ม: รายการล่าสุดสำหรับจอสาธารณะบนทีวี
// เก็บแค่แปดรายการล่าสุดแบบวงแหวน ไม่ต้องไปไล่เรียงฐานข้อมูลทุกครั้งที่ทีวีขอข้อมูล
// **เก็บเฉพาะรหัสที่ปิดบังแล้ว** ไม่เก็บชื่อ ไม่เก็บหมายเลขบัตร ไม่เก็บเลขอ้างอิง
// ข้อมูลที่ไม่ได้เก็บ ย่อมหลุดออกไปทางหน้าเว็บสาธารณะไม่ได้
#define PUBLIC_FEED_SIZE 8
struct PublicFeedItem {
  char maskedId[16];   // ห้าหลักแรกของรหัสนิสิต ที่เหลือเป็นดอกจัน
  char atTime[12];     // เวลาที่รับสิทธิ์ รูปแบบ HH:MM:SS
  uint8_t shop;        // ร้านที่ 1 ถึง 4
};
PublicFeedItem publicFeed[PUBLIC_FEED_SIZE] = {};
int publicFeedCount = 0;   // จำนวนรายการที่มีจริง สูงสุดเท่าขนาดวงแหวน
int publicFeedHead  = 0;   // ตำแหน่งที่จะเขียนรายการถัดไป

bool hostApReady            = false; // ปล่อยสัญญาณ Wi-Fi สำเร็จหรือไม่ ใช้บอกบนจอตอนบูต
// [113.0.0] แก้: เก็บเลขอ้างอิงของการสแกนไว้ ของเดิมสร้างใหม่ทุกครั้งที่วาดจอ
//           ทำให้ตัวนับเดินเรื่อย ๆ และเลขบนจอไม่ตรงกับที่บันทึกไว้
String lastScannedRef       = "-";   // เลขอ้างอิงของการสแกนครั้งล่าสุด
                                     // เก็บไว้ ไม่สร้างใหม่ตอนวาดจอ ไม่งั้นเลขจะเดินทุกครั้งที่รีเฟรช

uint32_t transactionCounter = 0;

int currentHostPage         = 0;
const int TOTAL_PAGES       = 3;
bool isScreensaverActive    = false;
bool stationScreenOn        = true;   // แม่ข่ายสั่งให้ไฟจอของสถานีเปิดอยู่หรือไม่
bool stationScreensaver     = false;  // แม่ข่ายสั่งให้สถานีพักหน้าจออยู่หรือไม่
uint8_t hostModeSeq         = 0;      // นับทุกครั้งที่คำสั่งการแสดงผลเปลี่ยน

// [113.9.0] เพิ่ม: ย้ำคำสั่งการแสดงผลหลายรอบแบบไม่หน่วงลูป
//           ของเดิมย้ำสามรอบติดกันด้วย delay(30) รวมแล้วกินเวลาแค่ 90 มิลลิวินาที
//           ถ้าจุดบริการพลาดช่วงนั้นไปก็ต้องรอ heartbeat รอบถัดไปเป็นวินาที
//           ตอนนี้กระจายการย้ำออกไปราวสองวินาที โดยให้ loop() เป็นคนส่ง
//           หน้าเว็บจึงตอบกลับทันทีโดยไม่ต้องค้างรอ และจอของแม่ข่ายก็ไม่สะดุด
uint8_t  displayAnnounceLeft = 0;
unsigned long displayAnnounceNext = 0;
const uint8_t      DISPLAY_ANNOUNCE_ROUNDS = 6;
const unsigned long DISPLAY_ANNOUNCE_GAP   = 300;
bool isCreditActive         = false;
bool isLiveScanDisplaying   = false;
unsigned long liveScanHoldUntil = 0;
unsigned long lastActivity  = 0;
const unsigned long TIMEOUT_SCREENSAVER = 300000;
const unsigned long DOUBLE_CLICK_GAP    = 280;
const unsigned long STATION_OFFLINE_TIMEOUT = 15000;

unsigned long lastMonitorCheck = 0;
unsigned long lastClockRefresh = 0;
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
void loop() {
  dnsServer.processNextRequest();
  server.handleClient();
  handleHostButton();
  calculateCpuLoad();

  ScanQueueItem item;
  if (scanQueue != NULL && xQueueReceive(scanQueue, &item, 0) == pdTRUE) {
    processScanRequest(item.mac, item.pkt, item.rssi);
  }

  for (int i = 0; i < 4; i++) {
    if (hbAckPending[i]) {
      hbAckPending[i] = false;
      HostResponsePacket ack = {};
      ack.magic = ESPNOW_PROTO_MAGIC;
      ack.version = ESPNOW_PROTO_VER;
      ack.msgType = MSG_HEARTBEAT;
      ack.stationId = i + 1;
      ack.seq = 0;
      strcpy(ack.status, "ONLINE");
      strncpy(ack.claimTime, getRealTimeStr().c_str(), sizeof(ack.claimTime) - 1);
      ack.servedCount = getStationServedCount(i + 1);
      sendToStation(i + 1, (uint8_t *)&ack, sizeof(HostResponsePacket));
      sendStationTheme(i + 1);
    }
  }

  // [113.11.0] เพิ่ม: ถ้าการ์ดยังไม่พร้อม ลองเมานต์ใหม่ทุกสามสิบวินาที
  //            เสียบการ์ดทีหลังได้โดยไม่ต้องรีบูต และถ้าการ์ดหลุดกลางวันแล้วเสียบคืน
  //            ระบบก็กลับมาบันทึกสำเนาต่อเองโดยไม่ต้องมีใครสั่ง
  if (!sdReady && millis() - lastSdRetry > 30000) {
    lastSdRetry = millis();
    initSDCard();
  }

  // [113.9.0] เพิ่ม: ย้ำคำสั่งการแสดงผลรอบที่เหลือ กระจายออกไปราวสองวินาที
  //           จุดบริการที่พลาดรอบแรกจึงได้รับภายในไม่ถึงวินาที แทนที่จะรอ heartbeat
  if (displayAnnounceLeft > 0 && millis() >= displayAnnounceNext) {
    displayAnnounceLeft--;
    displayAnnounceNext = millis() + DISPLAY_ANNOUNCE_GAP;
    sendDisplayConfigRound();
  }

  if (isLiveScanDisplaying && millis() > liveScanHoldUntil) {
    isLiveScanDisplaying = false;
    renderHostPage(true);
  }

  if (!isLiveScanDisplaying && !isScreensaverActive && !isCreditActive && (millis() - lastActivity >= TIMEOUT_SCREENSAVER)) {
    isScreensaverActive = true; 
    renderScreensaver(true);
  }

  // [113.2.0] แก้: เดิมรีเฟรชเฉพาะหน้า 1 กับหน้า 2 หน้า SYSTEM จึงค้างอยู่กับที่
  //           ทั้งที่มีอุณหภูมิชิปกับหน่วยความจำว่างที่ควรขยับ ตอนนี้รีเฟรชทุกหน้า
  //           ฟังก์ชันวาดจะเทียบค่าเก่าเองแล้ววาดซ้ำเฉพาะช่องที่เปลี่ยน จอจึงไม่กะพริบ
  if (!isLiveScanDisplaying && !isCreditActive && (millis() - lastClockRefresh >= 1000)) {
    lastClockRefresh = millis();
    if (isScreensaverActive) renderScreensaver(false);
    else renderHostPage(false);
  }

  if (millis() - lastMonitorCheck > 2500) {
    lastMonitorCheck = millis();
    for (int i = 0; i < 4; i++) {
      if (stationNodes[i].isOnline && (millis() - stationNodes[i].lastSeen > STATION_OFFLINE_TIMEOUT)) {
        stationNodes[i].isOnline = false;
      }
    }
    // [113.2.0] ย้าย: การวาดซ้ำย้ายไปอยู่กับรอบหนึ่งวินาทีข้างบนแล้ว
    //           ตรงนี้เหลือหน้าที่เดียวคือตัดสถานีที่เงียบหายไปออกจากสถานะออนไลน์
  }

  delay(2);
}

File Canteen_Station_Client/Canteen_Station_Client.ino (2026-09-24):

/**
 * @file      Canteen_Station_Client.ino
 * @brief     เครื่องประจำร้านค้า อ่านบัตร RFID แล้วถามสิทธิ์จากเครื่องแม่ข่าย
 * @version   122.12.0
 * @date      2026-09-23
 * @author    Kittiphan Rattanakorn <kittiphun.rut@mcu.ac.th>
 *
 * @par Organization
 * มหาวิทยาลัยมหาจุฬาลงกรณราชวิทยาลัย วิทยาเขตแพร่
 *
 * @par Description
 * เครื่องนี้ไม่ได้ตัดสินสิทธิ์เอง หน้าที่คืออ่านหมายเลขบัตรแล้วส่งไปถามแม่ข่าย
 * ผ่าน ESP-NOW ช่อง 1 แล้วแสดงคำตอบที่ได้กลับมา
 *
 * ไฟล์นี้เก็บเฉพาะตรรกะระบบ ส่วนที่วาดลงจอถูกแยกออกไปเป็น StationScreen.h
 * ซึ่ง #include ไว้ท้ายไฟล์ก่อน setup()
 *
 * @par Hardware
 * ESP32-S3 DevKitC-1 (N16R8) · จอ ST7789V 2.8" 320x240 บนบัส HSPI ·
 * เครื่องอ่านบัตร RC522 บนบัส FSPI · บัซเซอร์ GPIO 38 · ปุ่มกด GPIO 2 · WS2812 GPIO 48
 *
 * @par Dependencies
 * Adafruit GFX · Adafruit ST7735/ST7789 · MFRC522 ·
 * Arduino ESP32 core 2.x หรือ 3.x
 *
 * @par Revision History
 * | Version | Date | Change |
 * |---|---|---|
 * | 122.12.0 | 2026-09-24 | ปฏิเสธการแตะบัตรตั้งแต่ต้นเมื่อรู้อยู่แล้วว่าแม่ข่ายไม่ตอบ และแยกข้อความกรณีหมดเวลารอคำตอบเป็น "ไม่ทราบผล" แทน "ไม่สำเร็จ" |
 * | 122.11.0 | 2026-09-24 | จัดขาใหม่ทั้งบอร์ดให้สายไม่ไขว้กัน ย้าย RC522 มาอยู่ติดกันที่ GPIO4-7 กับ 15 ย้าย MISO ออกจากแถวขวา ย้ายวัดแบตเตอรี่ออกจากขา strapping GPIO3 ไป GPIO8 และใช้ขาบัซเซอร์ ปุ่มกด แบตเตอรี่ ชุดเดียวกับฝั่งแม่ข่าย |
 * | 122.10.0 | 2026-09-23 | ปิดโหมดประหยัดพลังงานของวิทยุด้วย WiFi.setSleep(false) ของเดิมใช้ esp_wifi_set_ps() ซึ่งถูกอีเวนต์ STA_START ของ Arduino core ทับกลับเป็น WIFI_PS_MIN_MODEM วิทยุจึงหลับและรับคำสั่งจากแม่ข่ายได้เฉพาะตอนเพิ่งส่ง heartbeat |
 * | 122.9.0 | 2026-09-23 | ตามการแก้แถบบนของ StationScreen.h ตรรกะในไฟล์นี้ไม่เปลี่ยน |
 * | 122.8.0 | 2026-09-23 | เปลี่ยนป้ายบนแถบบนและหน้าตั้งหมายเลขจาก POINT เป็น STATION |
 * | 122.7.0 | 2026-09-23 | สั่งเปลี่ยนธีมตอนสถานีพักหน้าจออยู่ ไม่เตะออกจากหน้าพักจออีกต่อไป วาดใหม่ตามหน้าที่แสดงอยู่จริงแทนการเรียก showStationPage() เสมอ |
 * | 122.6.2 | 2026-09-23 | ตามการแก้วิธีวาดคลื่นของ StationScreen.h ตรรกะในไฟล์นี้ไม่เปลี่ยน |
 * | 122.6.1 | 2026-09-23 | ตามการย้ายตำแหน่งฟังก์ชันของ StationScreen.h ที่ทำให้คอมไพล์ไม่ผ่าน ตรรกะในไฟล์นี้ไม่เปลี่ยน |
 * | 122.6.0 | 2026-09-23 | บันทึกผลการตรวจสุขภาพ RC522 ไว้ใน isReaderReady ให้สัญลักษณ์แตะบัตรบนหน้าแรกบอกความพร้อมได้จริง และตรวจทะเบียนรุ่นซ้ำหลังสั่งเริ่มใหม่ |
 * | 122.5.0 | 2026-09-23 | ตามการจัดตำแหน่งตัวอักษรของ StationScreen.h ตรรกะในไฟล์นี้ไม่เปลี่ยน |
 * | 122.4.0 | 2026-09-23 | ตามการแก้ของ StationScreen.h ตรรกะในไฟล์นี้ไม่เปลี่ยน |
 * | 122.3.0 | 2026-09-22 | ตามการแก้เรื่องกะพริบของ StationScreen.h ตรรกะในไฟล์นี้ไม่เปลี่ยน |
 * | 122.2.0 | 2026-09-22 | เรียกการวาดซ้ำทุกหนึ่งวินาที และเลิกวาดยอดด้วยพิกัดของตัวเองใน loop() |
 * | 122.1.0 | 2026-09-22 | แยกส่วนวาดจอออกไปเป็น StationScreen.h ตรรกะไม่เปลี่ยน |
 * | 122.0.0 | 2026-09-22 | เริ่มใหม่จากต้นฉบับ ย้ายจอไปบัส HSPI แก้ปัญหาจอเพี้ยนหลัง PCD_Init() รับคำสั่งโหมดการแสดงผลจากแม่ข่าย และตัดการตั้งค่าธีมที่ตัวเครื่องออก |
 * | 117.0.7 | 2026-09-21 | ต้นฉบับที่ใช้เป็นจุดเริ่ม เก็บสำเนาไว้ที่ original/ |
 *
 * @warning  จอต้องอยู่บนบัส HSPI เท่านั้น เพราะไลบรารี MFRC522 ยึดตัวแปร SPI
 *           มาตรฐาน (FSPI) ไว้ ถ้าใช้บัสเดียวกันจอจะเพี้ยนทันทีหลัง PCD_Init()
 * @warning  #include ของ StationScreen.h ต้องอยู่ท้ายไฟล์ก่อน setup()
 * @note     โหมดมืด/สว่าง และการพักหน้าจอ ถูกกำหนดจากเครื่องแม่ข่ายฝ่ายเดียว
 *           ปุ่มที่ตัวเครื่องจึงขึ้นข้อความแจ้งแทนการสลับเอง
 */

#include <WiFi.h>
#include <esp_now.h>
#include <esp_wifi.h>
#include <Preferences.h>
#include <Adafruit_GFX.h>
#include <Adafruit_ST7789.h>
#include <SPI.h>
#include <MFRC522.h>
#include <time.h>
#include <sys/time.h>

#define APP_VERSION         "122.12.0"
#define DEV_NAME            "Kittiphan Rattanakorn"
#define DEV_ROLE            "Computer Technical Officer"
#define DEV_INSTITUTION     "MCU Phrae Campus"

// Pin Configuration สำหรับ ESP32-S3 DevKitC-1
// ============================================================================
// การจัดขา (Pin Map) — ESP32-S3 DevKitC-1 N16R8
// ============================================================================
// [122.11.0] แก้: จัดขาใหม่ทั้งหมดให้สายไม่ไขว้กัน
//           อุปกรณ์ภายนอก **ทุกตัวอยู่บนแถวซ้ายของบอร์ดแถวเดียว** ไม่มีอะไรข้ามไปฝั่งขวา
//           และขาของแต่ละโมดูลเรียงติดกันตามลำดับขาบนตัวโมดูลเอง
//           รายละเอียดและผังเต็มอยู่ใน docs/HARDWARE.md
//
//   ตำแหน่ง   ขา        จุดบริการ
//   --------  --------  ----------------------------------------------------
//    1, 2     3V3       ไฟเลี้ยง 3.3V ของทุกโมดูล
//    3        RST       ปุ่มรีเซ็ตของบอร์ด ห้ามต่ออะไร
//    4        GPIO4     RC522  SDA (SS)
//    5        GPIO5     RC522  SCK
//    6        GPIO6     RC522  MOSI
//    7        GPIO7     RC522  MISO
//    8        GPIO15    RC522  RST
//    9        GPIO16    ว่าง คั่นระหว่างกลุ่ม
//   10        GPIO17    บัซเซอร์
//   11        GPIO18    ปุ่มกด (INPUT_PULLUP)
//   12        GPIO8     วัดแรงดันแบตเตอรี่ (ADC1_CH7)
//   13,14     GPIO3,46  ไม่ใช้ เป็นขา strapping
//   15        GPIO9     TFT  BLK
//   16        GPIO10    TFT  CS
//   17        GPIO11    TFT  DC
//   18        GPIO12    TFT  RES
//   19        GPIO13    TFT  SDA (MOSI)
//   20        GPIO14    TFT  SCL (SCLK)
//   21        5V0       ไม่ได้ใช้
//   22        GND       กราวด์ร่วมของทุกโมดูล
//
// แถวขวาไม่ได้ต่อสายอะไรเลย เหลือไว้ทั้งแถว
// ขาที่ห้ามใช้บนรุ่น N16R8: GPIO26-37 (แฟลชกับ PSRAM แบบ OPI),
// GPIO19/20 (USB), GPIO43/44 (UART0), GPIO0/3/45/46 (strapping)

// จอ ST7789 — หกขาเรียงติดกันที่ตำแหน่ง 15 ถึง 20
// เรียงตรงกับลำดับขาบนตัวโมดูลพอดี อ่านจากล่างขึ้นบน
// GND, VCC, SCL, SDA, RES, DC, CS, BLK จึงเสียบตรงลงมาได้โดยไม่ไขว้เลย
#define TFT_BLK             9
#define TFT_CS              10
#define TFT_DC              11
#define TFT_RST             12
#define TFT_MOSI            13
#define TFT_SCLK            14

// RC522 — ห้าขาเรียงติดกันที่ตำแหน่ง 4 ถึง 8 ใกล้ขา 3V3 ด้านบน
// ลำดับตรงกับขาบนตัวโมดูล SDA, SCK, MOSI, MISO แล้วข้าม IRQ กับ GND ไป RST
// สายทุกเส้นวิ่งลงทางเดียวกัน ไม่มีเส้นไหนไขว้กัน ส่วน IRQ ไม่ได้ใช้
#define RC522_SS            4
#define RC522_SCK           5
#define RC522_MOSI          6
#define RC522_MISO          7
#define RC522_RST           15

// อุปกรณ์สายเดี่ยว — สามขาติดกันที่ตำแหน่ง 10 ถึง 12
// ชุดนี้ใช้ขาเดียวกับฝั่งแม่ข่ายเป๊ะ สายชุดเดียวใช้ได้ทั้งสองบอร์ด
#define BUZZER_PIN          17
#define BTN_PIN             18
#define BATTERY_ADC_PIN     8   // ADC1_CH7 อ่านได้ขณะเปิด Wi-Fi

#define RGB_LED_PIN         48  // WS2812 บนบอร์ด ไม่ต้องเดินสาย

// ============================================================================
// DYNAMIC THEME ENGINE (คาลิเบทตาม TFT Color Calibration Tool)
// ============================================================================
bool isStationDarkMode = true;
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

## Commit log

2026-09-21 chore: import original firmware as baseline
    Host Server v107.0.1 and Station Client v117.0.7 as supplied, unmodified,
    so that subsequent fixes are reviewable as a diff.
    Claude-Session: https://claude.ai/code/session_01X9SBq9sFrEp9tTPMPW8bbn
    [Canteen_Host_Server.ino, Canteen_Station_Client.ino]
2026-09-21 fix(station): แยกบัส SPI, ซ่อมสถานะลิงก์สด, รับคำสั่งสลับธีมจาก Host
    - ย้ายจอ ST7789V ไปบัส HSPI เดิม SPI_TFT(FSPI) ชนกับตัวแปร SPI มาตรฐาน
    ของ ESP32-S3 ที่ผูกกับ FSPI และถูก MFRC522 เรียกใช้ ทำให้สองอุปกรณ์
    แย่ง peripheral เดียวกันคนละขา
    - รับ MSG_CONFIG/HostConfigPacket ที่ Host ส่งมา ของเดิมตัวรับตัดทิ้งทุก
    แพ็กเก็ตที่ len != sizeof(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
    [Canteen_Station_Client.ino]
2026-09-21 fix(host): ปิดช่องโหว่ ซ่อม CSV/เลขอ้างอิง และยกเครื่องเว็บพอร์ทัลให้เป็นแบบสด
    แก้ข้อผิดพลาด
    - หน้า 3 ของจอเรียก generateRefNo() ทุกครั้งที่วาด ทำให้เลขอ้างอิงบนจอไม่ตรง
    กับที่บันทึกจริง และ transactionCounter วิ่งขึ้นโดยไม่มีธุรกรรม
    - เพิ่ม csvQuote()/parseCsvLine() ใช้กับทุกเส้นทางของไฟล์ CSV ชื่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
    [Canteen_Host_Server.ino]
2026-09-21 perf(host): จองหน่วยความจำล่วงหน้าก่อนประกอบหน้าเว็บและรายงาน CSV
    หน้าพอร์ทัลมีขนาดราว 80KB และรายงาน CSV โตตามจำนวนนิสิต การปล่อยให้
    String ขยายบัฟเฟอร์เองนับสิบครั้งต่อหนึ่งคำขอทำให้ heap แตกเป็นเสี่ยง
    บนอุปกรณ์ที่เปิดทิ้งไว้ยาว ๆ
    Claude-Session: https://claude.ai/code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
2026-09-21 docs: เพิ่มภาพหน้าจอ 31 ภาพและหน้ารวมภาพสำหรับใช้ประกอบเอกสาร
    - docs/interface/web-*.png ถ่ายจากหน้าเว็บจริงที่เฟิร์มแวร์สร้างขึ้น
    โดยเปิดด้วย Chromium และป้อนข้อมูลตัวอย่างผ่าน /api/dashboard และ
    /api/students ครอบคลุมหน้าเข้าสู่ระบบ แดชบอร์ด ทะเบียนนิสิต การแจ้งผล
    ด้วย toast หน้าต่างตัดสิท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
2026-09-21 refactor(host): แยกหน้าเว็บออกเป็น WebPortal.h
    ย้าย getLoginHTML() และ getHTML() ทั้งก้อน (HTML, CSS และ JavaScript รวม
    ราว 72KB) ออกจากไฟล์สเก็ตช์หลักไปไว้ใน WebPortal.h ที่อยู่โฟลเดอร์เดียวกัน
    Arduino IDE จะแสดงเป็นอีกแท็บโดยอัตโนมัติ ไฟล์หลักจึงเหลือ 2,623 บรรทัด
    จาก 3,960 บรรทัด และเหลือเฉพาะตรรกะของระบบ
    การคอมไพล์แ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
2026-09-21 feat(host): เพิ่มหน้าจอสาธารณะ /display สำหรับมอนิเตอร์จอใหญ่
    หน้าใหม่สำหรับต่อออกจอใหญ่ในโรงอาหาร ให้นิสิตและร้านค้าเห็นยอดการใช้บริการ
    แบบเรียลไทม์ รีเฟรชเองทุก 2 วินาที แสดงยอดใช้สิทธิ์ ยอดจัดสรร รายการที่
    ตัดสิทธิ์ล่าสุด 12 รายการ และสถานะร้านค้าทั้งสี่
    อ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
2026-09-21 feat: ให้สถานีเปลี่ยนโหมดการแสดงผลตามเครื่องแม่ข่าย
    แม่ข่ายเป็นเจ้าของโหมดการแสดงผลของทั้งระบบ ขยาย HostConfigPacket จาก 5
    เป็น 8 ไบต์ เพิ่ม screenOn, screensaver และ modeSeq
    - ธีมสว่าง/มืด บังคับเสมอ แม่ข่ายย้ำคำสั่งทุกครั้งที่ตอบ heartbeat
    การกดสามครั้งที่สถานีจึงขึ้นหน้าแจ้งแทนการสล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
2026-09-21 fix(host): พอร์ทัลใช้งานไม่ได้ในหน้าต่าง captive portal
    initTheme() เรียก localStorage.getItem() โดยไม่หุ้ม try/catch หน้าต่าง
    captive portal ของ iOS/Android และโหมดไม่ระบุตัวตนจะโยน SecurityError
    ทำให้สคริปต์ตายตั้งแต่บรรทัดแรกของการเริ่มต้น ผลคือ bindAjaxForms(),
    bindDelegatedActions() และ refreshDashboard() ไม่เคยถูกเรียก ฟอร์มทุกใบ
    ไม่ทำงาน ปุ่มในตา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
    [Canteen_Host_Server.ino]
2026-09-21 feat(station): เพิ่มสัญลักษณ์ RFID และยกสิทธิ์ 35 บาทให้เด่นขึ้นบนหน้าแรก
    - วาดสัญลักษณ์บัตร RFID กลางหน้าจอ เป็นรูปบัตรพร้อมชิปและคลื่น contactless
    สามชั้น ใช้ drawRoundRect, fillRoundRect และ drawCircleHelper ล้วน ๆ
    จึงไม่กินแฟลชเพิ่มเหมือนการฝังบิตแมป และเปลี่ยนสีตามธีมได้
    - แยกสิทธิ์ต่อวันออกมาเ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
2026-09-21 feat(station): เติมข้อมูลหน้า 2 ให้เต็มจอและเป็นข้อมูลสด
    เดิมการ์ดจบที่ y=160 แต่แถบล่างเริ่มที่ y=218 เหลือพื้นที่ว่าง 58 พิกเซล
    คิดเป็น 24% ของจอ และการ์ดขวาเป็นข้อความคงที่ทั้งใบ
    - เพิ่มรายการที่จ่ายล่าสุดสามรายการของร้านนี้ในแถบล่างที่เคยว่าง
    เวลา รหัสนิสิตแบบป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
2026-09-21 docs: อธิบายข้อมูลใหม่บนหน้า 2 และแก้ขนาดแพ็กเก็ตใน README
    ตารางโปรโตคอลยังค้างขนาด HostConfigPacket ไว้ที่ 5 ไบต์ จากตอนที่ขยาย
    เป็น 8 ไบต์แล้ว และเพิ่มคำอธิบายรูปแบบภาพรวมระบบที่ฝากไปกับ heartbeat
    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
2026-09-21 feat: เสริมความทนทานของลิงก์และเพิ่มคิวออฟไลน์ฝั่งสถานี
    วิทยุ
    - กำลังส่ง 68 (17 dBm) -> 80 (20 dBm) ซึ่งเป็นค่าสูงสุดของ ESP32-S3
    - เพิ่ม WIFI_PROTOCOL_LR คู่กับ 11b/g/n ทั้งสองฝั่ง
    - เพิ่มสวิตช์ ESPNOW_FORCE_LONG_RANGE_RATE ปิดไว้เป็นค่าเริ่มต้น
    การส่งซ้ำ
    - เลิก fallback เป็น broadcast ที่ทำให้แย่ลงเพราะไม่มี ACK ระดับ MAC
    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
2026-09-21 feat(host): เพิ่มการพิมพ์สลิปออกเครื่องพิมพ์ความร้อน 58 มม. (v109.0.0)
    ไฟล์ใหม่ ThermalPrinter.h เป็นไดรเวอร์ ESC/POS อิสระ มีคิวและสองช่องทาง
    สลับด้วย #define บรรทัดเดียว: USB OTG host (ค่าเริ่มต้น เขียนไดรเวอร์คลาส
    ปริ้นเตอร์เองบน usb_host_lib) หรือ UART TTL ที่ GPIO 17/18
    - พิมพ์สลิปอัตโนมัติทุกครั้งที่ตัดสิทธิ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
2026-09-22 feat: ตรวจสิทธิ์ได้เองตอนลิงก์ขาด (Host 110.0.0 / Station 120.0.0)
    เดิมคิวออฟไลน์รับบัตรทุกใบโดยไม่ตรวจอะไรเลย บัตรที่ไม่ได้ลงทะเบียนหรือบัตร
    ที่ใช้สิทธิ์ไปแล้วก็ได้อาหารไปก่อน แล้วค่อยไปตกตอนซิงค์ซึ่งเรียกคืนไม่ได้แล้ว
    แม่ข่ายผลักบัญชีสิทธิ์ย่อไปเก็บที่สถานีล่ว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
2026-09-22 chore: ปักแท็กทุกเวอร์ชัน เก็บต้นฉบับ และแก้การอยู่ร่วมกับสถานีรุ่นเก่า (Host 110.0.1)
    **เก็บต้นฉบับ** — เพิ่มโฟลเดอร์ original/ เก็บโค้ดที่ส่งมาตอนเริ่มโครงการ
    (Host 107.0.1 / Station 117.0.7) ไว้ตามเดิมทุกไบต์ ตรวจด้วย md5 แล้วว่าตรงกับ
    ไฟล์ที่ได้รับและตรงกับคอมมิตแรก วางในโฟลเดอร์ชื่อต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
2026-09-22 fix(docs): เอา branch หลักออกจากรายการที่สั่งให้ลบ
    VERSIONS.md สั่งให้ลบ fervent-wozniak-66knt2 โดยเข้าใจผิดว่าเป็น branch
    ที่หลุดมาจากคำสั่ง push ระหว่างทาง ความจริงคือ default branch ของ repository
    (ยืนยันด้วย git remote show origin) และเป็น base ของ pull request ที่เปิดอยู่
    ถ้ารันคำสั่งนั้นจะลบ branch หลักทิ้งและทำให้ PR ใช้การไม่ได้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
2026-09-22 fix: เพิ่ม forward declaration ที่ขาด ทำให้คอมไพล์ผ่าน Arduino IDE
    Arduino IDE สร้างต้นแบบฟังก์ชันให้เองแล้ววางไว้เหนือจุดที่นิยาม struct
    ฟังก์ชันที่รับ struct ของสเก็ตช์เป็นพารามิเตอร์จึงต้องประกาศล่วงหน้าไว้เองเสมอ
    - fillStationConfig(HostConfigPacket&, uint8_t) ฝั่งแม่ข่าย
    คือจุดที่ทำให้คอมไพล์ไม่ผ่าน มีมาต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
    [Canteen_Host_Server.ino, Canteen_Station_Client.ino, protoscan.py]
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2026-09-22 docs: แก้คำแนะนำพาร์ทิชันที่ผิด และเพิ่มหัวข้อขนาดเฟิร์มแวร์
    Sketch too big ไม่ได้เกิดจากโค้ดยาวเกินไป แต่เกิดจากตั้ง Partition Scheme
    เป็นค่าเริ่มต้นซึ่งให้พื้นที่โปรแกรมแค่ 1.25 MB ทั้งที่บอร์ด N16R8 มีแฟลช 16 MB
    เปลี่ยนเป็น Huge APP (3MB No OTA/1MB SPIFFS) แล้วใช้ไปเพียง 43%
    คำแนะนำเดิมใน README ผิดและอ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
2026-09-22 fix(docs): แก้เลขคอมมิตของ release/08 ที่ใส่ผิด
    ตอนเพิ่มแถว release/09 ผมใส่เลขคอมมิตของ release/08 เป็นค่าที่แต่งขึ้นเอง
    ไม่ได้อ่านจากของจริง แก้เป็น b7dfc73 และตรวจซ้ำทุกแถวในตารางแล้วว่าตรงกับ
    branch บน GitHub ครบทุกอัน
    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
2026-09-22 fix: แก้ปัญหาชื่อ Wi-Fi ไม่โผล่มา (Host 112.0.0 / Station 121.0.0)
    สองสาเหตุ ความผิดพลาดของผมเองทั้งคู่
    1. WIFI_PROTOCOL_LR บน SoftAP ทำให้โทรศัพท์มองไม่เห็นชื่อ Wi-Fi ทั้งที่เครื่อง
    ปล่อยสัญญาณอยู่ ผมเคยเขียนคอมเมนต์การันตีว่าปลอดภัยโดยไม่เคยทดสอบ
    ตอนนี้ใส่สวิตช์ ENABLE_WIFI_LONG_RANGE ทั้งสองฝั่ง ค่าเร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
    [Canteen_Host_Server.ino, Canteen_Station_Client.ino]
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2026-09-22 feat(tft): ออกแบบหน้าจอใหม่ทั้งสองฝั่ง เรียบง่าย ภาษาอังกฤษ สองโหมด
    จอเดิมเต็มไปด้วยศัพท์ช่าง เช่น BENTO EXECUTIVE OVERVIEW, CORE TELEMETRY,
    LAST SCANNED BENEFICIARY ACTIVITY, ENCRYPTED CARD UID ซึ่งคนที่ยืนอยู่หน้าจอจริง
    คือนิสิตกับเจ้าของร้าน ไม่ใช่ช่าง จอใหม่จึงพูดภาษาคน และเหลือข้อความน้อยที่สุด
    เครื่องแม่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
    [Canteen_Host_Server.ino, Canteen_Station_Client.ino, HostScreen.h]
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2026-09-22 fix(tft): ซ่อมการรีเฟรชตัวเลขบนจอทั้งสองฝั่ง (113.2.0 / 122.2.0)
    ตรวจตามที่ท่านสั่ง พบว่าหลายจุดไม่รีเฟรชจริง บางจุดเป็นของเดิม
    บางจุดผมทำพังเองตอนออกแบบหน้าจอใหม่
    จุดที่ผมทำพังเอง
    - จอแม่ข่ายหน้า SHOPS ยอดรายร้านวาดเฉพาะตอนวาดใหม่ทั้งจอ มีคนมารับอาหาร
    แล้วตัวเลข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
    [Canteen_Host_Server.ino, Canteen_Station_Client.ino, HostScreen.h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]
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2026-09-22 fix(tft): แก้จอกะพริบทุกวินาที (113.3.0 / 122.3.0)
    รอบที่แล้วผมแก้ผิดจุด ไปลดจำนวนครั้งที่วาดซ้ำ ทั้งที่ต้นเหตุไม่ใช่การวาดบ่อย
    แต่เป็นวิธีวาด โค้ดเดิมล้างพื้นด้วย fillRect แล้วค่อยเขียนตัวอักษร
    ระหว่างสองจังหวะนั้นจอว่างเปล่าจริง ๆ ตาคนจึงเห็นเป็นการกะพริบ
    และเพราะ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
    [Canteen_Host_Server.ino, Canteen_Station_Client.ino, HostScreen.h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]
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2026-09-23 fix(tft): แก้อักษรซ้อนและภาษาไทยอ่านไม่ออกบนจอ (113.4.0 / 122.4.0)
    สองอาการที่ท่านเจอมาจากต้นเหตุเดียวกัน ฟอนต์ในตัวของ Adafruit GFX มีแต่ ASCII
    ไบต์ตั้งแต่ 0x80 ขึ้นไปถูกวาดเป็นสัญลักษณ์มั่ว และภาษาไทยหนึ่งตัวกินสามไบต์
    จึงกลายเป็นตัวประหลาดสามตัว ที่สำคัญกว่านั้นคือกินที่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
    [Canteen_Host_Server.ino, Canteen_Station_Client.ino, HostScreen.h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]
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2026-09-23 fix(tft): จัดตำแหน่งตัวอักษรบนจอให้ถูกต้อง (113.5.0 / 122.5.0)
    ท่านแจ้งว่าอักษรซ้อนหายแล้วและการกะพริบดีขึ้น แต่บรรทัดสีเขียวบนหน้าพักจอ
    ไม่ได้อยู่กึ่งกลางเหมือนนาฬิกากับวันที่
    สาเหตุ: ตอนเลิกล้างพื้น ผมเปลี่ยนบรรทัดที่เคยคำนวณกึ่งกลางเองให้เป็น
    drawFixedText() ซึ่งเติ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
    [Canteen_Host_Server.ino, Canteen_Station_Client.ino, HostScreen.h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]
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2026-09-24 เพิ่มไฟล์วงจรสำหรับ KiCad ทั้งสองบอร์ด
    สร้างด้วยสคริปต์ที่อ่านค่า define ของขาจากซอร์สเฟิร์มแวร์จริง ไม่ได้วาดมือ
    เพราะถ้าวาดมือแล้ววันหนึ่งย้ายขา ไฟล์วงจรจะเพี้ยนจากของจริงโดยไม่มีอะไรฟ้อง
    ช่างจะเดินสายตามแบบที่ผิดจนกว่าจะประกอบเสร็จแล้วใช้ไม่ได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
    [Canteen_Host.kicad_sch, Canteen_Station.kicad_sch]
2026-09-24 บันทึกสำเนาลงการ์ด SD ที่อยู่หลังโมดูลจอ (Host 113.11.0)
    หัวต่อการ์ดบนโมดูลจอเป็นคนละชุดกับหัวแถว SPI ของจอ อยู่คนละขอบบอร์ด
    ต้องเดินสายเพิ่มสี่เส้น แต่สองเส้นใช้บัสร่วมกับจอได้ คือ SD_SCK ไป GPIO14
    เส้นเดียวกับ TFT SCL และ SD_MOSI ไป GPIO13 เส้นเดียวกับ TFT SDA
    เหลือ SD_MISO กับ SD_CS ที่ต้องมีขา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
    [Canteen_Host.kicad_sch, Canteen_Station.kicad_sch]
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2026-09-24 ย้ายการ์ด SD ไปอยู่บัส SPI ของตัวเอง ไม่ใช้ร่วมกับจอ (Host 113.12.0)
    การแชร์บัสใช้งานได้จริงและเป็นวิธีมาตรฐาน ฝั่งซอฟต์แวร์ปลอดภัยเพราะไลบรารี SD
    ใน arduino-esp32 เรียก beginTransaction และ endTransaction ทุกครั้งเหมือน Adafruit
    และความเสี่ยงเรื่องการ์ดไม่ปล่อยขา MISO ก็ใช้ไม่ได้กับผังนี้เพราะจอไ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
    [Canteen_Host.kicad_sch, Canteen_Station.kicad_sch]
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
